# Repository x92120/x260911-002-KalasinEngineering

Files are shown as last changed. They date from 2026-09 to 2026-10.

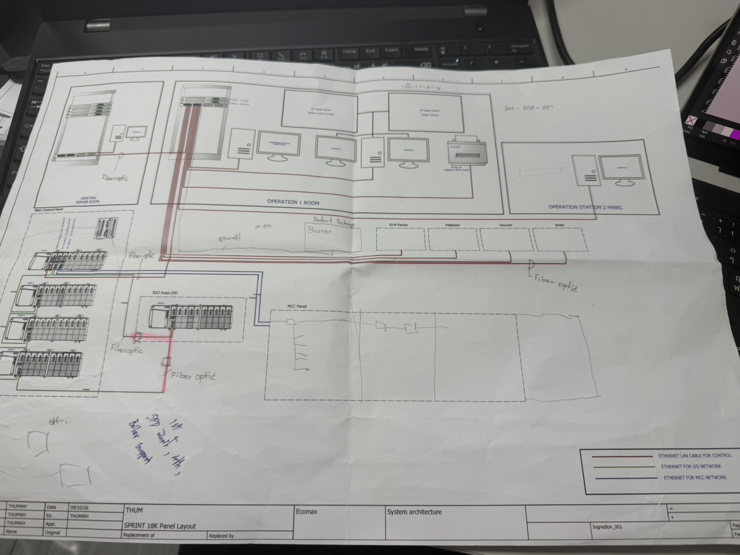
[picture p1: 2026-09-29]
01_Network_Design/05_Drawings_and_Schematics/S__103251990.jpg

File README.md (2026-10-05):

# Ingredion Kalasin Spray Dryer Plant — Engineering Workspace

**Project**: Ingredion Thailand — Sprint 18K TPA Spray Dryer Plant (Kalasin)  
**Engineering Disciplines**: Industrial OT Networks, Electrical Engineering, Instrumentation, Control Systems & CAD Automation  
**Control Platform**: Rockwell Automation ControlLogix 5580 (1756-L950TPSXT) / Studio 5000 / FactoryTalk View SE / Cisco Catalyst 9300 / Stratix 5700  
**Location**: Kalasin, Thailand  
**Ref / Order**: SPRINT 18K TPA Project  

---

## 📁 Workspace Directory Map

```text
x260911-002-KalasinEngineering/
├── 01_Network_Design/                  # Industrial OT Network Architecture, Cisco Core & Redundancy
│   ├── 01_Topology_and_Architecture/  # CPwE Topology Specs & Purdue Level 1-3 Network Architecture
│   ├── 02_IP_Address_Allocation/      # Subnet & IP Allocation Matrix (VLAN 10, 20, 30, 40, 50, 99)
│   ├── 03_Switch_and_Hardware_Config/ # Cisco Catalyst 9300 HSRP, Stratix 5700 & Server Teaming Configurations
│   ├── 04_DLR_and_Redundancy/         # Device Level Ring (DLR) Design & Supervisor Ring Rules
│   ├── 05_Drawings_and_Schematics/    # Network Riser Drawings (SVG, PDF, PNG, DXF & HTML Viewers)
│   ├── 06_Cable_Schedule/             # Cat6A Copper & OM3/OS2 Fiber Optic Cable Schedule
│   └── 07_Commissioning_and_FAT_SAT/  # SAT Test Sheets & Failover Validation Checklists
│
├── 02_Electrical_and_eDrawing/         # Electrical Schematics, CAD Deliverables & Instrument Specifications
│   ├── 01_Source_Drawings_DWG/        # Original Vendor AutoCAD DWG Drawings (SCD, LAY, WIR)
│   ├── 02_ePlan_Exports/              # Exported ePlan Project Packages (Spray Dryer & Electrical)
│   ├── 03_CAD_Exports_DXF_SVG/        # 154 Vectorized DXF & SVG Engineering Drawing Sheets
│   ├── 04_PDF_Reports_and_Drawings/   # 145 Engineering Drawing PDFs, JB Reports & Mounting Plans
│   ├── 05_Instrument_Manuals/         # 22 Vendor Instrument Technical & User Manuals & IS Barriers
│   ├── 06_SCADA_Demo/                 # FactoryTalk View SE HMI Demo Screens, Trends & Slides
│   └── 07_Presentations_and_Overviews/# PID Control Strategy Presentations & Loop Architecture
│
├── 03_IO_Lists_and_Schedules/          # Master Excel Workbooks, I/O Tag Databases & Junction Schedules
│   ├── Destination_Reports/           # 16 Field Junction Box & MCC Destination Schedule Workbooks
│   ├── IO_List/                       # Slot-Configured I/O Master Workbooks & Tag Databases
│   ├── IO_List-Bak/                   # Engineering Revision Archives & Raw Tag Imports
│   └── Slot_by_Slot_Reports/          # Per-Chassis (C1–C7) Slot-by-Slot Hardware Reports (Excel & PDF)
│
├── 04_Automation_Scripts/              # CAD Automation, PDF Report Builders & Interactive HTML Viewers
│   ├── cable_schedule_viewer.html      # Interactive Cable Schedule Search & Filter Tool
│   ├── pid_loop_control_viewer.html    # Interactive PID Loop Control Strategy Web Viewer
│   └── *.py                            # Python Scripts for CAD, PDF, SVG, and Excel Report Generation
│
├── 261005-IO_Config/                   # Remote I/O & Junction Panel Configuration Reports
├── Datasheet/                          # Pepperl+Fuchs Barrier & Instrument Field Datasheets
├── eDrawingTemplate/                   # AutoCAD DXF Drawing Frames, Title Blocks & Module Templates
├── x900-eDrawing/                      # Legacy Vendor ePlan EDB Projects & AutoCAD DWG Drawings
└── x9100-eDrawing/                     # 47 Individual Slot-by-Slot I/O DXF Schematics (C1S1–C5S4)
```

---

## 🎨 Visual Master Deliverables & Interactive Viewers

| Deliverable Sheet | Web / Vector / CAD Links | Description |
| :--- | :--- | :--- |
| **Redundant Cisco Core & Server Infrastructure** | [Web Viewer](file:///e:/xApp-01/x260911-002-KalasinEngineering/01_Network_Design/05_Drawings_and_Schematics/Viewer_Redundant_Network_Diagram.html) • [PDF](file:///e:/xApp-01/x260911-002-KalasinEngineering/01_Network_Design/05_Drawings_and_Schematics/Redundant_Cisco_Core_and_Server_Network_Diagram.pdf) • [SVG](file:///e:/xApp-01/x260911-002-KalasinEngineering/01_Network_Design/05_Drawings_and_Schematics/Redundant_Cisco_Core_and_Server_Network_Diagram.svg) | Dual Cisco Catalyst 9300 HSRP v2, FT View SE Server Teaming, 10G Fiber Uplinks, MCC Switch Trunk |
| **ControlLogix 5-Chassis DLR Network & 13-Slot Rack** | [Web Viewer](file:///e:/xApp-01/x260911-002-KalasinEngineering/01_Network_Design/05_Drawings_and_Schematics/Viewer_Network_and_Rack_Design.html) • [PDF](file:///e:/xApp-01/x260911-002-KalasinEngineering/01_Network_Design/05_Drawings_and_Schematics/ControlLogix_5Chassis_DLR_Network_and_Rack_Design.pdf) • [SVG](file:///e:/xApp-01/x260911-002-KalasinEngineering/01_Network_Design/05_Drawings_and_Schematics/ControlLogix_5Chassis_DLR_Network_and_Rack_Design.svg) | ODVA DLR Ring (CS1–CS4 in MCP-01, CS5 RIO200 via Fiber) & 13-Slot Chassis Elevation |
| **SPRINT 18K Control Layout & System Architecture** | [Web Viewer](file:///e:/xApp-01/x260911-002-KalasinEngineering/01_Network_Design/05_Drawings_and_Schematics/Viewer_SPRINT_18K_Control_Layout.html) • [DXF](file:///e:/xApp-01/x260911-002-KalasinEngineering/01_Network_Design/05_Drawings_and_Schematics/SPRINT_18K_Control_Layout_System_Architecture.dxf) • [PDF](file:///e:/xApp-01/x260911-002-KalasinEngineering/01_Network_Design/05_Drawings_and_Schematics/SPRINT_18K_Control_Layout_System_Architecture.pdf) | Complete Plant Architecture matching hand-drawn draft S__103251990 |
| **Interactive Plant Cable Schedule Viewer** | [HTML Viewer](file:///e:/xApp-01/x260911-002-KalasinEngineering/04_Automation_Scripts/cable_schedule_viewer.html) | Interactive tool for searching instrument cables, terminal pins, and destination JB routing |
| **Interactive PID Loop Control Viewer** | [HTML Viewer](file:///e:/xApp-01/x260911-002-KalasinEngineering/04_Automation_Scripts/pid_loop_control_viewer.html) | Interactive viewer detailing PID control loops for Jet Cooker, Dryer Tower, and CIP |

---

## 📑 Core Documentation Index

### 1. Network Engineering (`01_Network_Design`)
* 📄 [Network Architecture Specification](file:///e:/xApp-01/x260911-002-KalasinEngineering/01_Network_Design/01_Topology_and_Architecture/NETWORK_ARCHITECTURE_SPEC.md)
* 📄 [Plant Subnet & IP Allocation Matrix](file:///e:/xApp-01/x260911-002-KalasinEngineering/01_Network_Design/02_IP_Address_Allocation/IP_ALLOCATION_MATRIX.md)
* 📄 [Cisco Core Switch Configuration Guide](file:///e:/xApp-01/x260911-002-KalasinEngineering/01_Network_Design/03_Switch_and_Hardware_Config/CISCO_REDUNDANT_CORE_SWITCH_CONFIG.md)
* 📄 [Server Redundancy & Dual NIC Teaming](file:///e:/xApp-01/x260911-002-KalasinEngineering/01_Network_Design/03_Switch_and_Hardware_Config/SERVER_REDUNDANCY_AND_NIC_TEAMING_CONFIG.md)
* 📄 [MCC Trunk & Stratix Switch Setup](file:///e:/xApp-01/x260911-002-KalasinEngineering/01_Network_Design/03_Switch_and_Hardware_Config/MCC_TRUNK_AND_SWITCH_CONFIG.md)
* 📄 [Device Level Ring (DLR) Topology Design](file:///e:/xApp-01/x260911-002-KalasinEngineering/01_Network_Design/04_DLR_and_Redundancy/DLR_TOPOLOGY_DESIGN.md)

### 2. Electrical & Drawings (`02_Electrical_and_eDrawing`)
* 📄 [Source DWG Drawings Overview](file:///e:/xApp-01/x260911-002-KalasinEngineering/02_Electrical_and_eDrawing/01_Source_Drawings_DWG/README.md)
* 📄 [ePlan Project Exports Index](file:///e:/xApp-01/x260911-002-KalasinEngineering/02_Electrical_and_eDrawing/02_ePlan_Exports/README.md)
* 📄 [CAD Exports (DXF/SVG) Index](file:///e:/xApp-01/x260911-002-KalasinEngineering/02_Electrical_and_eDrawing/03_CAD_Exports_DXF_SVG/README.md)
* 📄 [PDF Reports & Wiring PDF Drawings](file:///e:/xApp-01/x260911-002-KalasinEngineering/02_Electrical_and_eDrawing/04_PDF_Reports_and_Drawings/README.md)
* 📄 [Pepperl+Fuchs IS Barriers Documentation](file:///e:/xApp-01/x260911-002-KalasinEngineering/02_Electrical_and_eDrawing/05_Instrument_Manuals/Pepperl+Fuchs%20IS%20Barriers/README.md)

### 3. I/O Lists & Schedules (`03_IO_Lists_and_Schedules`)
* 📄 [Destination Junction Box Schedules](file:///e:/xApp-01/x260911-002-KalasinEngineering/03_IO_Lists_and_Schedules/Destination_Reports/README.md)
* 📄 [Master Slot-Configured I/O Databases](file:///e:/xApp-01/x260911-002-KalasinEngineering/03_IO_Lists_and_Schedules/IO_List/README.md)
* 📄 [Per-Chassis Slot-by-Slot Reports](file:///e:/xApp-01/x260911-002-KalasinEngineering/03_IO_Lists_and_Schedules/Slot_by_Slot_Reports/README.md)

### 4. CAD & Automation Tools (`04_Automation_Scripts`)
* 📄 [Automation Scripts Overview](file:///e:/xApp-01/x260911-002-KalasinEngineering/04_Automation_Scripts/README.md)

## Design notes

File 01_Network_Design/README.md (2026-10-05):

# Industrial OT Network Design Specification

**Project**: Ingredion Thailand — Sprint 18K TPA Spray Dryer Plant (Kalasin)  
**Standard**: Converged Plantwide Ethernet (CPwE) / ANSI/ISA-95 & ISA-99 (IEC 62443)  
**Plant Systems**: Area 202 (Pre-Slurry), Area 402 (Adjustment), Area 602 (Spray Dryer), Area 814 (Plant CIP)  
**Main Platform**: Rockwell Automation ControlLogix 5580, Stratix 5700/5400 Managed Switches, EtherNet/IP (CIP), Cisco Catalyst 9300 Core  

---

## 📌 Overview & Architecture Principles

The Industrial OT Network for the Ingredion Kalasin Spray Dryer Plant is architected according to CPwE guidelines to ensure:
1. **Deterministic Performance**: Dedicated EtherNet/IP bandwidth for real-time PLC-to-PLC communication and I/O scan loops.
2. **High Availability & Fault Tolerance**: Device Level Ring (DLR) for field I/O racks with sub-3ms media recovery time, redundant Cisco Catalyst 9300 core switches (HSRP v2), and dual-homed server NIC teaming.
3. **Purdue Security Segmentation**: Strict segmentation across Purdue Levels 0–3 using managed VLANs (10, 20, 30, 40, 50, 99) and access control policies.
4. **Structured Cabling**: Standardized Cat6A industrial copper and OM3/OS2 fiber optic links with defined cabling schedules.

---

## 📁 Directory Structure & Module Index

```text
01_Network_Design/
├── README.md                              # Main Industrial OT Network Specification
├── 01_Topology_and_Architecture/          # CPwE Architecture, Purdue Levels & Topology Specifications
│   ├── README.md
│   └── NETWORK_ARCHITECTURE_SPEC.md       # Core Architecture & Purdue Model Definition
├── 02_IP_Address_Allocation/              # Subnetting Plan, VLAN Assignments & Device Schedule
│   ├── README.md
│   └── IP_ALLOCATION_MATRIX.md            # Detailed IP Address Assignment Table
├── 03_Switch_and_Hardware_Config/         # Cisco IOS Core Configs, Stratix Switch Port Maps & Server Setup
│   ├── README.md
│   ├── CISCO_REDUNDANT_CORE_SWITCH_CONFIG.md  # Cisco Catalyst 9300 HSRP v2 & LACP Production Config
│   ├── MCC_TRUNK_AND_SWITCH_CONFIG.md         # Stratix 5700 MCC 802.1Q Trunk Configuration
│   ├── SERVER_REDUNDANCY_AND_NIC_TEAMING_CONFIG.md # FT View SE Server Redundancy & Teaming Guide
│   └── SWITCH_HARDWARE_SPEC.md                # Managed Switch Hardware Specifications
├── 04_DLR_and_Redundancy/                 # Device Level Ring (DLR) Topology & Ring Supervisor Rules
│   ├── README.md
│   └── DLR_TOPOLOGY_DESIGN.md             # DLR Ring Supervisor Rules & Active/Backup Node Setup
├── 05_Drawings_and_Schematics/            # Master Vector Network Riser Diagrams, Elevation & Web Viewers
│   ├── README.md
│   ├── Redundant_Cisco_Core_and_Server_Network_Diagram.svg
│   ├── ControlLogix_5Chassis_DLR_Network_and_Rack_Design.svg
│   ├── SPRINT_18K_Control_Layout_System_Architecture.dxf
│   └── *.html / *.pdf / *.png
├── 06_Cable_Schedule/                     # Copper Cat6A & Fiber Optic Cable Schedule
│   ├── README.md
│   └── CABLE_SCHEDULE_TEMPLATE.md         # Industrial Cable Schedule Specification
└── 07_Commissioning_and_FAT_SAT/          # SAT Checklists, Ping Sweep Records & Failover Testing
    ├── README.md
    └── NETWORK_COMMISSIONING_CHECKLIST.md # Network Testing & Validation Protocol
```

---

## 🎨 Master Deliverable Drawings

1. **Redundant Cisco Core & Server Infrastructure**:
   * [Interactive Web Viewer](file:///e:/xApp-01/x260911-002-KalasinEngineering/01_Network_Design/05_Drawings_and_Schematics/Viewer_Redundant_Network_Diagram.html)
   * [Printable PDF](file:///e:/xApp-01/x260911-002-KalasinEngineering/01_Network_Design/05_Drawings_and_Schematics/Redundant_Cisco_Core_and_Server_Network_Diagram.pdf)
   * [Vector SVG](file:///e:/xApp-01/x260911-002-KalasinEngineering/01_Network_Design/05_Drawings_and_Schematics/Redundant_Cisco_Core_and_Server_Network_Diagram.svg)
2. **ControlLogix 5-Chassis DLR Network & 13-Slot Rack Redesign**:
   * [Interactive Web Viewer](file:///e:/xApp-01/x260911-002-KalasinEngineering/01_Network_Design/05_Drawings_and_Schematics/Viewer_Network_and_Rack_Design.html)
   * [Printable PDF](file:///e:/xApp-01/x260911-002-KalasinEngineering/01_Network_Design/05_Drawings_and_Schematics/ControlLogix_5Chassis_DLR_Network_and_Rack_Design.pdf)
   * [Vector SVG](file:///e:/xApp-01/x260911-002-KalasinEngineering/01_Network_Design/05_Drawings_and_Schematics/ControlLogix_5Chassis_DLR_Network_and_Rack_Design.svg)
3. **SPRINT 18K Control Layout & System Architecture**:
   * [Interactive Web Viewer](file:///e:/xApp-01/x260911-002-KalasinEngineering/01_Network_Design/05_Drawings_and_Schematics/Viewer_SPRINT_18K_Control_Layout.html)
   * [AutoCAD DXF (R2010)](file:///e:/xApp-01/x260911-002-KalasinEngineering/01_Network_Design/05_Drawings_and_Schematics/SPRINT_18K_Control_Layout_System_Architecture.dxf)

---

## 🏷️ Network Layer Summary

| Layer | Purdue Level | Typical Devices | Network Media | Subnet Example |
|---|---|---|---|---|
| **Site Operations / SCADA** | Level 3 | FactoryTalk SE HMI Server, Historian, Engineering Workstation (EWS) | 1Gbps Fiber / Cat6A | `192.168.10.0/24` (VLAN 10) |
| **Supervisory / Operator HMI** | Level 2 | PanelView 5510, Area Thin Clients, Engineering Laptops | 1Gbps / 100Mbps Copper | `192.168.20.0/24` (VLAN 20) |
| **Control & Inter-PLC** | Level 1 | ControlLogix 5580 CPUs, 1756-EN4TR, Safety PACs | 1000BASE-T / Ring Trunk | `192.168.30.0/24` (VLAN 30) |
| **Field I/O & Drives (DLR Rings)** | Level 0/1 | POINT I/O 1734-AENTR, PowerFlex 525/755 VFDs, Flowmeters | 100BASE-TX M12 / RJ45 DLR | `192.168.40.0/24` (VLAN 40) |

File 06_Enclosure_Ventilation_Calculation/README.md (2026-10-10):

# 06 Enclosure Ventilation & Thermal Calculation

**Project**: Sprint 18K TPA Spray Dryer / Jet Cooker  
**Ref Code**: `xCIP-1545` (Ref: `x2608003`)  
**Client**: Ingredion (Thailand) Co., Ltd.  
**Contractor**: Kalasin Engineering Co., Ltd.  

---

## Deliverables in this Folder

1. **Official PDF Calculation Report**:
   - [`Enclosure_Ventilation_Calculation_Report.pdf`](file:///Users/x92120/xApp-001/x260911-002-KalasinEngineering/06_Enclosure_Ventilation_Calculation/Enclosure_Ventilation_Calculation_Report.pdf) (4 Pages, ready for client submission & FAT binder)

2. **Full Markdown Engineering Report**:
   - [`Enclosure_Ventilation_Calculation_Report.md`](file:///Users/x92120/xApp-001/x260911-002-KalasinEngineering/06_Enclosure_Ventilation_Calculation/Enclosure_Ventilation_Calculation_Report.md)

3. **Source Typst File**:
   - [`Enclosure_Ventilation_Calculation_Report.typ`](file:///Users/x92120/xApp-001/x260911-002-KalasinEngineering/06_Enclosure_Ventilation_Calculation/Enclosure_Ventilation_Calculation_Report.typ)

4. **Automated Calculation Script**:
   - [`calculate_ventilation.py`](file:///Users/x92120/xApp-001/x260911-002-KalasinEngineering/06_Enclosure_Ventilation_Calculation/calculate_ventilation.py)

5. **Diagrams & Catalog Excerpts in `assets/`**:
   - Enclosure Thermal Layout Diagram: [`assets/enclosure_ventilation_diagram.png`](file:///Users/x92120/xApp-001/x260911-002-KalasinEngineering/06_Enclosure_Ventilation_Calculation/assets/enclosure_ventilation_diagram.png)
   - Airflow vs. Temperature Characteristic Curves: [`assets/airflow_vs_temperature_curve.png`](file:///Users/x92120/xApp-001/x260911-002-KalasinEngineering/06_Enclosure_Ventilation_Calculation/assets/airflow_vs_temperature_curve.png)
   - Supplier Catalog Excerpt (Fans): [`assets/primus_fan_models_crop.png`](file:///Users/x92120/xApp-001/x260911-002-KalasinEngineering/06_Enclosure_Ventilation_Calculation/assets/primus_fan_models_crop.png)
   - Supplier Catalog Excerpt (Thermostats): [`assets/primus_thermostats_crop.png`](file:///Users/x92120/xApp-001/x260911-002-KalasinEngineering/06_Enclosure_Ventilation_Calculation/assets/primus_thermostats_crop.png)

---

## Quick Summary of Calculation Results

- **Enclosure**: 800 (W) × 2000 (H) × 400 (D) mm (Volume = 0.640 m³)
- **External Ambient**: 30.0 °C
- **Target Enclosure Temperature**: 35.0 °C ($\Delta T = 5.0\text{ K}$)
- **Total Thermal Dissipation**: **268.3 Watts** (**915.5 BTU/h**), including +15% engineering margin
- **Required Airflow**:
  - Pure Airflow: **166.3 m³/h**
  - Design Airflow (+30% filter margin): **216.2 m³/h**
- **Selected Primus Equipment**:
  - **Filter Fan Unit**: **Primus PMV250N** (8", 220VAC, **428 m³/h**, 56 dB, IP54) — **1.98× design safety factor**
  - **Exhaust Grille**: **Primus PMF250N** (250 × 250 mm with G4 washable filter mat)
  - **Thermostat**: **Primus CMA-001** (Mechanical bimetal, set to Cut-in 35°C / Cut-out 30°C)

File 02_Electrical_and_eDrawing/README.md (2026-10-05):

# Electrical & eDrawing Deliverables

**Project**: Ingredion Thailand — Sprint 18K TPA Spray Dryer Plant (Kalasin)  
**Engineering Discipline**: Electrical Engineering, Cabinet Layout, Loop Wiring, & CAD Deliverables  

---

## 📁 Module Directory Overview

This module houses all original vendor DWG schematics, exported ePlan packages, DXF/SVG CAD exports, print-ready PDF engineering drawing sets, instrument vendor documentation, SCADA demo assets, and control strategy presentations.

```text
02_Electrical_and_eDrawing/
├── 01_Source_Drawings_DWG/          # Original vendor AutoCAD DWG schematics & wiring layouts
├── 02_ePlan_Exports/                # Exported ePlan project packages & electrical schematics
├── 03_CAD_Exports_DXF_SVG/          # 154 vectorized DXF & SVG component & panel sheets
├── 04_PDF_Reports_and_Drawings/     # 145 engineering PDF drawings, JB reports & cable schedules
├── 05_Instrument_Manuals/           # 22 vendor instrument manuals & IS Barrier datasheets
├── 06_SCADA_Demo/                   # SCADA HMI demo screens, process trend slides & HTML viewers
└── 07_Presentations_and_Overviews/  # PID loop control specification slides & architecture overviews
```

---

## 📑 Key Master Engineering Documents

| Document Title | Format | Description / Link |
| :--- | :---: | :--- |
| **Kalasin Jet Cooker Master Drawings** | PDF | [KALASIN_JET_COOKER_MASTER_ENGINEERING_DRAWINGS_COMPLETE.pdf](file:///e:/xApp-01/x260911-002-KalasinEngineering/02_Electrical_and_eDrawing/04_PDF_Reports_and_Drawings/KALASIN_JET_COOKER_MASTER_ENGINEERING_DRAWINGS_COMPLETE.pdf) |
| **Jet Cooker PLC I/O Wiring Drawings Complete** | PDF | [Jet_Cooker_PLC_IO_Wiring_Drawings_Complete.pdf](file:///e:/xApp-01/x260911-002-KalasinEngineering/02_Electrical_and_eDrawing/04_PDF_Reports_and_Drawings/Jet_Cooker_PLC_IO_Wiring_Drawings_Complete.pdf) |
| **MCC Panel Layout & Mounting Plan (M1–M4)** | PDF | [MCC_Panel_Layout_Mounting_Plan_M1_M2_M3_M4.pdf](file:///e:/xApp-01/x260911-002-KalasinEngineering/02_Electrical_and_eDrawing/04_PDF_Reports_and_Drawings/MCC_Panel_Layout_Mounting_Plan_M1_M2_M3_M4.pdf) |
| **Cable Schedule (MCC to Junction Boxes)** | PDF | [Cable_Schedule_MCC_to_Junction_Boxes.pdf](file:///e:/xApp-01/x260911-002-KalasinEngineering/02_Electrical_and_eDrawing/04_PDF_Reports_and_Drawings/Cable_Schedule_MCC_to_Junction_Boxes.pdf) |
| **Instrument Installation Hookups & Wiring** | PDF | [Instrument_Installation_Hookup_and_Wiring_Templates.pdf](file:///e:/xApp-01/x260911-002-KalasinEngineering/02_Electrical_and_eDrawing/04_PDF_Reports_and_Drawings/Instrument_Installation_Hookup_and_Wiring_Templates.pdf) |
| **All Junction Boxes Master I/O Report** | PDF | [IO_List_All_Junction_Boxes_Master_Report.pdf](file:///e:/xApp-01/x260911-002-KalasinEngineering/02_Electrical_and_eDrawing/04_PDF_Reports_and_Drawings/IO_List_All_Junction_Boxes_Master_Report.pdf) |
| **PID Loop Control Specification Presentation** | PPTX / HTML | [PID_Loop_Control_Specification_Kalasin.pptx](file:///e:/xApp-01/x260911-002-KalasinEngineering/02_Electrical_and_eDrawing/07_Presentations_and_Overviews/PID_Loop_Control_Specification_Kalasin.pptx) |

---

## 📐 Source AutoCAD DWG Reference

* [R5THS00138-000-SCD-10001_0.dwg](file:///e:/xApp-01/x260911-002-KalasinEngineering/02_Electrical_and_eDrawing/01_Source_Drawings_DWG/R5THS00138-000-SCD-10001_0.dwg) — Master Control System Schematic
* [R5THS00138-FBR-LAY-20001_1.dwg](file:///e:/xApp-01/x260911-002-KalasinEngineering/02_Electrical_and_eDrawing/01_Source_Drawings_DWG/R5THS00138-FBR-LAY-20001_1.dwg) — Silo Panel General Layout & BOM
* [R5THS00138-FBR-WIR-20001_3.dwg](file:///e:/xApp-01/x260911-002-KalasinEngineering/02_Electrical_and_eDrawing/01_Source_Drawings_DWG/R5THS00138-FBR-WIR-20001_3.dwg) — Electrical Wiring Layout

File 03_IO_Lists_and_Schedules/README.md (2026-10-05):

# I/O Lists & Instrument Schedules

**Project**: Ingredion Thailand — Sprint 18K TPA Spray Dryer Plant (Kalasin)  
**Engineering Discipline**: Instrumentation, Control System I/O Allocation & Cable Scheduling  

---

## 📌 Module Directory Overview

This module houses all master Excel workbooks, PDF I/O schedules, per-enclosure destination reports, per-chassis slot reports, and instrument cable mapping matrices for the plant control system.

```text
03_IO_Lists_and_Schedules/
├── Destination_Reports/             # 16 Field Junction Box & MCC Enclosure Workbooks
│   └── README.md
├── IO_List/                         # Slot-Configured I/O Master Workbooks & Tag Databases
│   └── README.md
├── IO_List-Bak/                     # Revision Archives, Raw Tag Imports & Historical Summaries
│   └── README.md
├── Slot_by_Slot_Reports/            # Per-Chassis (C1–C7) Slot-by-Slot Reports (Excel & PDF)
│   └── README.md
├── Chassis_and_Slot_IO_Source_Destination_Report.pdf  # ⭐ MASTER PDF: 99-Page I/O Schedule
├── Chassis_IO_List_Per_Slot_Report.xlsx               # ⭐ MASTER EXCEL: 48 Tabs (1 Sheet per Slot)
├── Destination_IO_List_Master_Report.pdf              # ⭐ MASTER PDF: 82-Page Destination Schedule
└── Destination_IO_List_Master_Report.xlsx             # ⭐ MASTER EXCEL: 17 Tabs (1 Sheet per Destination)
```

---

## 📑 Key Master Workbooks & PDF Reports

| Report / Deliverable Name | Format | Purpose | Link / Location |
| :--- | :---: | :--- | :--- |
| **Destination I/O Master Schedule** | PDF (82 Pages) | Master Field Enclosure Vector Schedule | [Destination_IO_List_Master_Report.pdf](file:///e:/xApp-01/x260911-002-KalasinEngineering/03_IO_Lists_and_Schedules/IO_List-Bak/Destination_IO_List_Master_Report.pdf) |
| **Destination I/O Master Excel** | Excel (17 Tabs) | 1 Tab Per Field Destination (16 JBs + Index) | [Destination_IO_List_Master_Report.xlsx](file:///e:/xApp-01/x260911-002-KalasinEngineering/03_IO_Lists_and_Schedules/IO_List-Bak/Destination_IO_List_Master_Report.xlsx) |
| **Per-Destination Workbooks** | Excel (16 Files) | Independent Enclosure Schedule Workbooks | [Destination_Reports/](file:///e:/xApp-01/x260911-002-KalasinEngineering/03_IO_Lists_and_Schedules/Destination_Reports/README.md) |
| **Chassis & Slot Master PDF** | PDF (99 Pages) | Hardware Rack Wiring Vector Deliverable | [Chassis_and_Slot_IO_Source_Destination_Report.pdf](file:///e:/xApp-01/x260911-002-KalasinEngineering/03_IO_Lists_and_Schedules/IO_List-Bak/Chassis_and_Slot_IO_Source_Destination_Report.pdf) |
| **Chassis I/O List Per Slot** | Excel (48 Tabs) | 1 Tab Per Hardware Slot (47 Slot Tabs + Index) | [Chassis_IO_List_Per_Slot_Report.xlsx](file:///e:/xApp-01/x260911-002-KalasinEngineering/03_IO_Lists_and_Schedules/IO_List-Bak/Chassis_IO_List_Per_Slot_Report.xlsx) |
| **Per-Chassis Slot Packages** | Excel + PDF | Per-Chassis Hardware Packages (C1–C7) | [Slot_by_Slot_Reports/](file:///e:/xApp-01/x260911-002-KalasinEngineering/03_IO_Lists_and_Schedules/Slot_by_Slot_Reports/README.md) |
| **Instrument & Cable Matrix** | Excel Workbook | Master Instrument-to-Cable Schedule | [Instrument_IO_Mapping_with_Models_and_Cables.xlsx](file:///e:/xApp-01/x260911-002-KalasinEngineering/03_IO_Lists_and_Schedules/IO_List-Bak/Instrument_IO_Mapping_with_Models_and_Cables.xlsx) |

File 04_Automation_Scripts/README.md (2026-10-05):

# 04_Automation_Scripts — Engineering CAD & Report Generators

This directory contains the Python automation tools, drawing generation engines, PDF compilers, and interactive HTML web viewers for the **Ingredion Kalasin Spray Dryer Plant** project.

---

## 🌐 Interactive Web Viewers

* 🌐 **[cable_schedule_viewer.html](file:///e:/xApp-01/x260911-002-KalasinEngineering/04_Automation_Scripts/cable_schedule_viewer.html)**: Dynamic cable schedule inspector with live search, field destination filtering, and cable routing breakdown.
* 🌐 **[pid_loop_control_viewer.html](file:///e:/xApp-01/x260911-002-KalasinEngineering/04_Automation_Scripts/pid_loop_control_viewer.html)**: Interactive PID loop control architecture viewer covering Jet Cooker, Dryer Tower, and CIP systems.

---

## 📁 Automation Scripts Inventory & Categorization

### 1. I/O Report & Master Excel Workbooks Generators
* ⚙️ **`build_chassis_slot_pdf_reports.py`**: Compiles per-chassis (C1–C7) slot-by-slot PDF vector reports.
* ⚙️ **`build_chassis_slot_source_destination_report.py`**: Builds 99-page master chassis & slot source-to-destination vector report.
* ⚙️ **`build_destination_io_report.py`**: Builds 82-page master destination report and 16 individual junction box workbooks.
* ⚙️ **`build_io_list_by_slot_config.py`**: Maps raw ePlan tag data into slot-configured Excel workbooks.
* ⚙️ **`build_junction_io_panel_report.py`**: Generates panel P1–P4 junction-to-panel allocation matrix & remote I/O reports.
* ⚙️ **`build_per_slot_io_report.py`**: Builds 48-tab master Excel workbook with 1 tab per slot.
* ⚙️ **`build_tags_list_plc_r02.py`**: Processes and updates PLC tag databases.

### 2. CAD Drawing Generators & Converters
* ⚙️ **`export_cad_svg_dxf.py`**: Batch CAD export pipeline converting ePlan DWG/DXF drawings into vectorized SVG presentation sheets.
* ⚙️ **`generate_di_slot_dxf_drawings.py`**: Generates 15 individual DI slot DXF schematics (C1S4–C4S3).
* ⚙️ **`generate_do_slot_dxf_drawings.py`**: Generates 9 individual DO slot DXF schematics (C1S8–C5S3).
* ⚙️ **`generate_plc_io_wiring_drawings.py`**: Generates 40-sheet PLC I/O modular wiring schematics (`KAL-JC-WIR-*`).
* ⚙️ **`generate_mcc_panel_layout.py`**: Generates 14-sheet MCC panel layout drawings (front elevation, internal GA, BOM).
* ⚙️ **`generate_instrument_drawing_templates.py`**: Generates 26 instrument installation hookup drawings (`KAL-JC-TYP-*`).
* ⚙️ **`generate_pf_is_barrier_dxf.py`**: Generates Pepperl+Fuchs IS barrier CAD wiring diagrams.
* ⚙️ **`convert_pf_datasheet_to_dxf.py`** & **`convert_yamamori_pdf_to_dxf.py`**: PDF datasheet-to-DXF CAD converter scripts.

### 3. Presentation & SCADA Assets Generators
* ⚙️ **`generate_automation_architecture_slides.py`**: Generates dark-theme automation architecture presentation slides.
* ⚙️ **`generate_light_architecture_slides.py`**: Generates light-theme architecture presentation slides.
* ⚙️ **`generate_cable_schedule_slides.py`**: Generates cable schedule SVG vector presentation slides.
* ⚙️ **`generate_pid_control_presentation.py`**: Generates PID loop control specification presentation slides.
* ⚙️ **`generate_scada_demo_video.py`**: Renders 60-second 1080p SCADA demo MP4 video animation.

---

## ⚙️ Running Generators

```powershell
# Build master destination I/O report & 16 enclosure workbooks:
python 04_Automation_Scripts/build_destination_io_report.py

# Build master chassis & slot 99-page vector PDF report:
python 04_Automation_Scripts/build_chassis_slot_source_destination_report.py

# Generate 40-sheet PLC wiring diagrams:
python 04_Automation_Scripts/generate_plc_io_wiring_drawings.py

# Generate MCC panel layout drawings:
python 04_Automation_Scripts/generate_mcc_panel_layout.py
```

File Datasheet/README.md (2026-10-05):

# Datasheet — Field Instruments & Barrier Datasheets

This directory contains vendor technical datasheets, component specifications, and CAD-converted datasheet pages for field instruments and intrinsically safe isolator modules deployed at the **Ingredion Kalasin Spray Dryer Plant**.

---

## 📁 Subdirectories & Files

* **`75ebca09-4009-4d5b-9186-ca9b53211407.pdf`**: Master instrument datasheet package.
* **[PF/](file:///e:/xApp-01/x260911-002-KalasinEngineering/Datasheet/PF/README.md)**: Pepperl+Fuchs Intrinsically Safe (IS) K-System Isolating Barrier datasheets (PDF) and converted CAD drawings (DXF).

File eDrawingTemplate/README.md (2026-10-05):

# eDrawingTemplate — AutoCAD DXF & DWG Drawing Frames and Templates

This directory contains standardized AutoCAD drawing title block frames, border templates, and module wiring templates used by automated script generators for the **Ingredion Kalasin Spray Dryer Plant** CAD deliverables.

---

## 📐 Template Inventory

### 1. Title Block & Frame Templates
* **`frame.dwg`** / **`frame.dxf`**: Standard A3 ISO drawing frame with title block, engineering revision block, project metadata, and logo attributes.
* **`Frame_rev01.dxf`**: Revision 01 updated title block frame.
* **`Drawing2.dxf`**: Reference AutoCAD layout workspace template.

### 2. Module Electrical Wiring Templates
* **`template_DI-r02.dwg`** / **`template_DI-r02.dxf`**: Revision 02 32-Channel Digital Input (1756-IB32) module wiring drawing template.
* **`template_DO-r02.dwg`** / **`template_DO-r02.dxf`**: Revision 02 32-Channel Digital Output (1756-OB32 + Relay) module wiring drawing template.
* **`template_AI-r02.dwg`** / **`template_AI-r02.dxf`**: Revision 02 16-Channel Analog Input (1756-IF16) module wiring drawing template.
* **`template_DI.dxf`** / **`template_DO.dxf`**: Legacy baseline single-channel wiring templates.

---

## ⚙️ Usage in Automation Pipeline

Python scripts in `04_Automation_Scripts` (such as `generate_di_slot_dxf_drawings.py` and `generate_do_slot_dxf_drawings.py`) read these DXF templates, clone entity structures, update tag text and wire numbers, and output per-slot drawings into `02_Electrical_and_eDrawing/03_CAD_Exports_DXF_SVG/` and `x9100-eDrawing/`.

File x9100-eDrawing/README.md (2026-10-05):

# x9100-eDrawing — Individual Slot-by-Slot CAD Wiring Drawings

This directory contains individual AutoCAD `.dxf` single-slot wiring diagrams for **all 13 slots (Slots 0 to 12)** across Chassis `C1`, `C2`, `C3`, `C4`, and `C5`, formatted with explicit hardware module model tags (`CxSy-<CARD>.dxf`, e.g. `C1S4-IB32.dxf`), master multi-slot CAD compilations, Python generation scripts, and module templates for the **Ingredion Kalasin Spray Dryer Plant**.

---

## 📁 Group Subdirectories Index (`CxSy-<CARD>.dxf`)

* 📁 **[C1/](file:///e:/xApp-01/x260911-002-KalasinEngineering/x9100-eDrawing/C1)** — Chassis C1 Main Controller Rack Drawings (30 files: `C1S0-L950TPSXT` to `C1S12-N2` DI, DO, AI, CPU & COMM DXFs)
* 📁 **[C2/](file:///e:/xApp-01/x260911-002-KalasinEngineering/x9100-eDrawing/C2)** — Chassis C2 Process Expansion Rack Drawings (26 files: `C2S0-EN4TR` to `C2S12-IF16` COMM, DI, DO & AI DXFs)
* 📁 **[C3/](file:///e:/xApp-01/x260911-002-KalasinEngineering/x9100-eDrawing/C3)** — Chassis C3 Evaporator & Skid I/O Rack Drawings (26 files: `C3S0-EN4TR` to `C3S12-OF8` COMM, DI, DO, AI, Reserve & AO DXFs)
* 📁 **[C4/](file:///e:/xApp-01/x260911-002-KalasinEngineering/x9100-eDrawing/C4)** — Chassis C4 Spray Dryer & Exhaust Rack Drawings (26 files: `C4S0-EN4TR` to `C4S12-N2` COMM, DI, DO, AI & Reserve DXFs)
* 📁 **[C5/](file:///e:/xApp-01/x260911-002-KalasinEngineering/x9100-eDrawing/C5)** — Chassis C5 Remote I/O Skid RIO-200 Drawings (26 files: `C5S0-EN4TR` to `C5S12-N2` COMM, DI, DO, AI & Reserve DXFs)

---

## 📑 Complete 13-Slot Hardware Model Filename Schedule

| Chassis | Slot 0 | Slots 1–3 | Slots 4–7 | Slots 8–9 | Slots 10–11 | Slot 12 |
| :---: | :--- | :--- | :--- | :--- | :--- | :--- |
| **C1** | `C1S0-L950TPSXT.dxf` | `C1S1-EN4TR.dxf` .. `C1S3-EN4TR.dxf` | `C1S4-IB32.dxf` .. `C1S7-IB32.dxf` | `C1S8-OB32.dxf` .. `C1S9-OB32.dxf` | `C1S10-IF16.dxf` .. `C1S11-IF16.dxf` | `C1S12-N2.dxf` |
| **C2** | `C2S0-EN4TR.dxf` | `C2S1-IB32.dxf` .. `C2S3-IB32.dxf` | `C2S4-IB32.dxf` .. `C2S5-IB32.dxf` | `C2S6-OB32.dxf` .. `C2S8-OB32.dxf` | `C2S9-IF16.dxf` .. `C2S11-IF16.dxf` | `C2S12-IF16.dxf` |
| **C3** | `C3S0-EN4TR.dxf` | `C3S1-IB32.dxf` .. `C3S3-IB32.dxf` | `C3S4-OB32.dxf` .. `C3S5-OB32.dxf` | `C3S6-IF16.dxf` .. `C3S9-IF16.dxf` | `C3S10-N2.dxf` .. `C3S11-N2.dxf` | `C3S12-OF8.dxf` |
| **C4** | `C4S0-EN4TR.dxf` | `C4S1-IB32.dxf` .. `C4S3-IB32.dxf` | `C4S4-OB32.dxf` | `C4S5-IF16.dxf` .. `C4S6-IF16.dxf` | `C4S7-N2.dxf` .. `C4S11-N2.dxf` | `C4S12-N2.dxf` |
| **C5** | `C5S0-EN4TR.dxf` | `C5S1-IB32.dxf` .. `C5S2-IB32.dxf` | `C5S3-OB32.dxf` | `C5S4-IF16.dxf` | `C5S5-N2.dxf` .. `C5S11-N2.dxf` | `C5S12-N2.dxf` |

---

## ⚙️ Running Automation Scripts

```powershell
# Batch update all per-slot DXF drawings with CxSy-<CARD> naming:
python x9100-eDrawing/update_x9100_drawings.py

# Recompile master 65-slot (5 Rows x 13 Columns) DXF grid compilation file:
python x9100-eDrawing/build_master_dxf.py
```

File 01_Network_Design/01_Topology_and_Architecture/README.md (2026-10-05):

# 01_Topology_and_Architecture — Industrial OT Network Architecture

This directory contains the core topology and architecture specifications for the **Ingredion Kalasin Spray Dryer Plant** industrial control system network, designed according to Converged Plantwide Ethernet (CPwE) standards.

---

## 📄 Key Documents & Specifications

* **[NETWORK_ARCHITECTURE_SPEC.md](file:///e:/xApp-01/x260911-002-KalasinEngineering/01_Network_Design/01_Topology_and_Architecture/NETWORK_ARCHITECTURE_SPEC.md)**: Detailed architecture specification covering Purdue Model Levels 1–3, industrial VLAN segmentation, firewall boundaries, and network redundancy standards.

---

## 📐 CPwE Network Architecture Overview

```text
+-------------------------------------------------------------------+
| Level 3: Industrial Zone / SCADA Servers (FactoryTalk SE, EWS)    |
+-------------------------------------------------------------------+
                                  |
                   [Cisco Catalyst 9300 Core HSRP]
                                  |
+-------------------------------------------------------------------+
| Level 2: Supervisory Control / HMI & PanelView Touchscreens      |
+-------------------------------------------------------------------+
                                  |
                   [Stratix 5700 Industrial Switches]
                                  |
+-------------------------------------------------------------------+
| Level 1: Control (ControlLogix 5580 PACs & 1756-EN4TR Cards)     |
+-------------------------------------------------------------------+
                                  |
                   [Device Level Ring (DLR) Topology]
                                  |
+-------------------------------------------------------------------+
| Level 0: Field I/O (POINT I/O 1734-AENTR, PowerFlex VFDs, Sensors)|
+-------------------------------------------------------------------+
```

---

## 🎯 Primary Architectural Goals

1. **Sub-3ms Ring Recovery**: ODVA Device Level Ring (DLR) topology for field chassis (CS1–CS5).
2. **Core Redundancy**: Dual Cisco Catalyst 9300 core switches operating with Hot Standby Router Protocol (HSRP v2).
3. **Dual-Homed Server NIC Teaming**: FactoryTalk View SE servers configured with active/standby NIC teaming for seamless failover.

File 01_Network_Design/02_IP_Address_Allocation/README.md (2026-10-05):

# 02_IP_Address_Allocation — Subnet & IP Matrix

This directory defines the plant-wide IP address allocation matrix and VLAN segmentation schema for the **Ingredion Kalasin Spray Dryer Plant**.

---

## 📄 Key Document

* **[IP_ALLOCATION_MATRIX.md](file:///e:/xApp-01/x260911-002-KalasinEngineering/01_Network_Design/02_IP_Address_Allocation/IP_ALLOCATION_MATRIX.md)**: Full master IP address allocation table for PLCs, HMIs, Remote I/O adapters, VFDs, Managed Switches, and SCADA Servers.

---

## 🌐 Industrial VLAN Assignment Table

| VLAN ID | Subnet CIDR | Description / Target Equipment | Gateway / HSRP |
| :---: | :--- | :--- | :--- |
| **VLAN 10** | `192.168.10.0/24` | SCADA Servers, Historian, Engineering Workstations (Level 3) | `192.168.10.1` |
| **VLAN 20** | `192.168.20.0/24` | PanelView HMI Touchscreens & Thin Clients (Level 2) | `192.168.20.1` |
| **VLAN 30** | `192.168.30.0/24` | Primary PAC Controller Inter-PLC Network (Level 1) | `192.168.30.1` |
| **VLAN 40** | `192.168.40.0/24` | Field Remote I/O & DLR EtherNet/IP Sub-ring (Level 0/1) | N/A (Isolated DLR) |
| **VLAN 50** | `192.168.50.0/24` | PowerFlex VFDs & Motor Control Center (MCC) Devices | `192.168.50.1` |
| **VLAN 99** | `10.10.99.0/24` | Network Infrastructure Management (Stratix / Cisco Switches) | `10.10.99.1` |

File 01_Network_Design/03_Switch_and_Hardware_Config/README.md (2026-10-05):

# 03_Switch_and_Hardware_Config — Switch Configurations & Hardware Setup

This directory contains production-ready Cisco IOS and Rockwell Stratix managed switch configurations, along with server NIC teaming guidelines for the **Ingredion Kalasin Spray Dryer Plant**.

---

## 📄 Key Production Configurations & Specifications

* 🛠️ **[CISCO_REDUNDANT_CORE_SWITCH_CONFIG.md](file:///e:/xApp-01/x260911-002-KalasinEngineering/01_Network_Design/03_Switch_and_Hardware_Config/CISCO_REDUNDANT_CORE_SWITCH_CONFIG.md)**: Production Cisco Catalyst 9300 HSRP v2, LACP EtherChannel, and VLAN Trunk configuration scripts.
* 🛠️ **[MCC_TRUNK_AND_SWITCH_CONFIG.md](file:///e:/xApp-01/x260911-002-KalasinEngineering/01_Network_Design/03_Switch_and_Hardware_Config/MCC_TRUNK_AND_SWITCH_CONFIG.md)**: Stratix 5700 802.1Q trunking configuration for the Motor Control Center (MCC) switch cabinet.
* 💻 **[SERVER_REDUNDANCY_AND_NIC_TEAMING_CONFIG.md](file:///e:/xApp-01/x260911-002-KalasinEngineering/01_Network_Design/03_Switch_and_Hardware_Config/SERVER_REDUNDANCY_AND_NIC_TEAMING_CONFIG.md)**: Configuration guide for FT View SE Primary/Secondary SCADA Server NIC teaming and network failover.
* 📋 **[SWITCH_HARDWARE_SPEC.md](file:///e:/xApp-01/x260911-002-KalasinEngineering/01_Network_Design/03_Switch_and_Hardware_Config/SWITCH_HARDWARE_SPEC.md)**: Hardware specification sheet for Cisco Catalyst 9300 and Stratix 5700/5400 switches.

---

## 🔒 Security & Redundancy Features

1. **HSRP v2 Core Failover**: Sub-second virtual router failover between Active and Standby Catalyst 9300 core switches.
2. **802.1Q Trunking**: Standardized VLAN tagging across fiber optic uplinks between MCP-01 and field cabinets.
3. **Port Security & CIP Sync**: Optimized QoS configuration prioritizing PTP (Precision Time Protocol / IEEE 1588) and CIP I/O packets.

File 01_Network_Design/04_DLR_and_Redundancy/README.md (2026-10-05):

# 04_DLR_and_Redundancy — Device Level Ring Topology

This directory details the ODVA EtherNet/IP Device Level Ring (DLR) design, ring supervisor configuration, and redundancy protocols for the **Ingredion Kalasin Spray Dryer Plant**.

---

## 📄 Key Document

* **[DLR_TOPOLOGY_DESIGN.md](file:///e:/xApp-01/x260911-002-KalasinEngineering/01_Network_Design/04_DLR_and_Redundancy/DLR_TOPOLOGY_DESIGN.md)**: Device Level Ring topology specification, active ring supervisor setup, backup supervisor rules, and sub-3ms recovery benchmarks.

---

## ⭕ DLR Ring Allocation Summary

| Ring ID | Location / Cabinet | Included Nodes / Chassis | Active Supervisor | Backup Supervisor | Media / Speed |
| :---: | :--- | :--- | :--- | :--- | :--- |
| **DLR-01** | MCP-01 (Main Control Panel) | Chassis CS1, CS2, CS3, CS4 | 1756-EN4TR (CS1 Slot 1) | 1756-EN4TR (CS2 Slot 1) | Cat6A Shielded (100Mbps Full-Duplex) |
| **DLR-02** | RIO200 (Remote I/O Cabinet) | Chassis CS5 (RIO200 1734-AENTR / 1756-RIO) | 1756-EN4TR (CS5 Slot 1) | Stratix 5700 Managed Switch | Single-Mode Fiber Optic Link |

---

## ⚡ Performance Specifications

* **Media Recovery Time**: < 3 ms upon single link disruption.
* **Beacon Interval**: 400 microseconds.
* **Timeout Value**: 1,960 microseconds.

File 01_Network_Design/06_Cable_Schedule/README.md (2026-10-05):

# 06_Cable_Schedule — Industrial Network Cable Specifications

This directory contains the cable schedule standards, media specifications, and labeling conventions for the **Ingredion Kalasin Spray Dryer Plant**.

---

## 📄 Key Document

* **[CABLE_SCHEDULE_TEMPLATE.md](file:///e:/xApp-01/x260911-002-KalasinEngineering/01_Network_Design/06_Cable_Schedule/CABLE_SCHEDULE_TEMPLATE.md)**: Master network cabling specification, cable ID format, wire colors, and shielding rules.

---

## 🔌 Cable Media & Standards

| Cable Code | Cable Type | Conductor / Spec | Typical Usage | Max Distance |
| :---: | :--- | :--- | :--- | :---: |
| **CAT6A-SH** | Cat6A Shielded S/FTP | 24 AWG Twisted Pair, Teal PUR Jacket | EtherNet/IP Field DLR & Switch Links | 100 m |
| **FO-SM-OS2** | Single-Mode Fiber OS2 | 9/125 µm Duplex LC | MCP-01 to RIO200 & MCC Fiber Trunk | 2 km |
| **FO-MM-OM3** | Multi-Mode Fiber OM3 | 50/125 µm Duplex LC | Server Room to Core Switch Interconnect | 300 m |

---

## 🏷️ Cable Labeling Format

Format: `[Source Device] - [Media Type] - [Destination Device] - [Cable No.]`  
Example: `CS1-EN4TR1 - CAT6A - CS2-EN4TR1 - CABLE-0104`

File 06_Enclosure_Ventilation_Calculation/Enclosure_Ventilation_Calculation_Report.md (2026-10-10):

# Control Enclosure Thermal Dissipation & Ventilation Fan Sizing Report

**Document Reference**: `KAL-CALC-VENT-2610-001`  
**Revision**: `Rev 1.0` (Date: 10-Oct-2026)  
**Project**: Sprint 18K TPA Spray Dryer / Jet Cooker (xCIP-1545, Ref: `x2608003`)  
**Client**: Ingredion (Thailand) Co., Ltd.  
**Contractor**: Kalasin Engineering Co., Ltd.  
**Applicable Standards**: IEC 60890, IEC 61439-1, DIN 57660  
**Supplier Catalog Reference**: [`x9100-eDrawing/Supplier/PrimusVentilation.pdf`](file:///Users/x92120/xApp-001/x260911-002-KalasinEngineering/x9100-eDrawing/Supplier/PrimusVentilation.pdf)  
**Deliverable PDF**: [`06_Enclosure_Ventilation_Calculation/Enclosure_Ventilation_Calculation_Report.pdf`](file:///Users/x92120/xApp-001/x260911-002-KalasinEngineering/06_Enclosure_Ventilation_Calculation/Enclosure_Ventilation_Calculation_Report.pdf)  

---

## 1. Executive Summary & Design Basis

This formal engineering report calculates the total internal heat dissipation, evaluates natural surface radiation/conduction, determines forced cooling ventilation airflow requirements, and selects the optimal industrial cabinet filter fan from the approved supplier catalog **Primus Ventilation Systems** for an automation cabinet with dimensions **800 mm (W) × 2000 mm (H) × 400 mm (D)**.

### Summary of Operating Conditions & Results

| Parameter | Specified / Calculated Value | Design Reference & Standard |
| :--- | :--- | :--- |
| **Enclosure Outer Dimensions** | **800 mm (W) × 2000 mm (H) × 400 mm (D)** | Floor-standing automation cabinet |
| **Gross Enclosure Volume** | **0.640 m³** | Free internal air volume |
| **Effective Surface Area ($A_{\text{eff}}$)** | **4.768 m²** (Free-standing) / **3.168 m²** (Wall-mounted) | Calculated per IEC 60890 |
| **External Ambient Temperature ($T_{\text{ambient}}$)** | **30.0 °C** | Specified external ambient condition |
| **Target Internal Temperature ($T_{\text{internal}}$)** | **35.0 °C** (Optimum Lifespan) / **40.0 °C** (Standard Limit) | $\Delta T = 5.0\text{ K}$ (Optimum) / $10.0\text{ K}$ (Standard) |
| **Installed Equipment Heat Load** | **233.3 Watts** | 2x 40A PSUs + 1756 13-Slot Rack + Relays |
| **Engineering Safety Margin (+15%)** | **35.0 Watts** | Cable resistance, aging & future expansion |
| **Total Design Heat Load ($Q_{\text{total}}$)** | **268.3 Watts** (**915.5 BTU/h**) | Evacuated by forced airflow |
| **Required Design Airflow ($V_{\text{design}}$ @ 35°C)** | **216.2 m³/h** | Includes +30% dust clogging margin |
| **Selected Fan Model** | **PRIMUS PMV250N** (8" Filter Fan, 220VAC, IP54) | **428 m³/h** airflow (**1.98× design safety factor**) |
| **Matching Exhaust Grille** | **PRIMUS PMF250N** (250 × 250 mm with G4 Filter) | Tool-free Flap-Open front door |
| **Thermostatic Controller** | **PRIMUS CMA-001** (Mechanical DIN-Rail Thermostat) | Setpoint: Cut-in 35°C / Cut-out 30°C |

---

## 2. Enclosure Physical Dimensions & Surface Heat Dissipation (IEC 60890)

The physical enclosure geometry and effective heat dissipation area $A_{\text{eff}}$ are derived in accordance with **IEC 60890** (*Calculation of temperature rise for low-voltage switchgear and controlgear assemblies*):

- **Width ($W$)**: $0.800\text{ m}$ ($800\text{ mm}$)
- **Height ($H$)**: $2.000\text{ m}$ ($2000\text{ mm}$)
- **Depth ($D$)**: $0.400\text{ m}$ ($400\text{ mm}$)
- **Volume ($V$)**: $W \times H \times D = 0.800 \times 2.000 \times 0.400 = \mathbf{0.640\text{ m}^3}$

### Surface Area Breakdown

$$\begin{aligned}
A_{\text{front}} &= W \times H = 0.800 \times 2.000 = 1.600\text{ m}^2 \\
A_{\text{rear}} &= W \times H = 0.800 \times 2.000 = 1.600\text{ m}^2 \\
A_{\text{sides}} &= 2 \times (D \times H) = 2 \times (0.400 \times 2.000) = 1.600\text{ m}^2 \\
A_{\text{roof}} &= W \times D = 0.800 \times 0.400 = 0.320\text{ m}^2 \\
A_{\text{geom, total}} &= 1.600 + 1.600 + 1.600 + 0.320 = \mathbf{5.120\text{ m}^2} \quad \text{(Bottom base on floor excluded)}
\end{aligned}$$

### IEC 60890 Weighted Effective Surface Area ($A_{\text{eff}}$)

1. **Free-Standing Enclosure** (all sides detached from walls):
   $$A_{\text{eff, free}} = 1.8 \cdot H \cdot (W + D) + 1.4 \cdot W \cdot D = 1.8(2.0)(0.8 + 0.4) + 1.4(0.8)(0.4) = 4.320 + 0.448 = \mathbf{4.768\text{ m}^2}$$
2. **Stand-Alone against a Wall** (rear panel covered):
   $$A_{\text{eff, wall}} = 1.4 \cdot W \cdot D + 0.9 \cdot D \cdot H + W \cdot H + 0.5 \cdot D \cdot H = 0.448 + 0.720 + 1.600 + 0.400 = \mathbf{3.168\text{ m}^2}$$

### Natural Surface Heat Dissipation Capability ($Q_s$)

Using the heat transfer coefficient for standard painted sheet steel $k = 5.5\text{ W}/(\text{m}^2\cdot\text{K})$:
- At $\Delta T = 5.0\text{ K}$ ($T_{\text{in}} = 35.0^\circ\text{C}$):
  - Free-Standing: $Q_s = 5.5 \times 4.768 \times 5.0 = \mathbf{131.1\text{ W}}$
  - Wall-Mounted: $Q_s = 5.5 \times 3.168 \times 5.0 = \mathbf{87.1\text{ W}}$
- At $\Delta T = 10.0\text{ K}$ ($T_{\text{in}} = 40.0^\circ\text{C}$):
  - Free-Standing: $Q_s = 5.5 \times 4.768 \times 10.0 = \mathbf{262.2\text{ W}}$
  - Wall-Mounted: $Q_s = 5.5 \times 3.168 \times 10.0 = \mathbf{174.2\text{ W}}$

> **Conservative Design Philosophy**: In industrial food/starch processing plants subject to dust accumulation, high humidity, and seasonal ambient temperature excursions, engineering best practice sizes forced ventilation for **100% of the internal heat dissipation ($Q_v = Q_{\text{total}}$)** without relying on enclosure surface conduction.

---

## 3. Equipment Heat Dissipation Load Inventory ($P_{\text{internal}}$)

Each active electrical component installed inside the cabinet has been inventoried based on manufacturer datasheets:

| No. | Equipment Description | Catalog / Model | Qty | Unit Heat Loss (W) | Total Heat Loss (W) | Design Basis & Technical Reference |
| :---: | :--- | :--- | :---: | :---: | :---: | :--- |
| **1** | 24VDC 40A Industrial Power Supply | Phoenix Contact QUINT4-40A (or eq.) | 2 | 61.3 W | **122.6 W** | Rated 960W output @ 94% efficiency at 100% load |
| **2** | ControlLogix AC Chassis Power Supply | Rockwell 1756-PA75 | 1 | 25.0 W | **25.0 W** | Maximum internal heat dissipation (85.3 BTU/h) |
| **3** | ControlLogix 5580 Controller (40MB) | Rockwell 1756-L95 | 1 | 6.2 W | **6.2 W** | 100% execution cycle, embedded 1Gbps active |
| **4** | EtherNet/IP Dual-Port DLR Adapters | Rockwell 1756-EN4TR | 3 | 3.5 W | **10.5 W** | Gigabit dual-port adapter (11.9 BTU/h each) |
| **5** | ControlLogix Digital Input Modules | Rockwell 1756-IB32 | 4 | 5.5 W | **22.0 W** | 32-ch 24VDC sink/source input cards |
| **6** | ControlLogix Digital Output Modules | Rockwell 1756-OB32 | 2 | 4.8 W | **9.6 W** | 32-ch 24VDC sourcing output cards |
| **7** | ControlLogix Analog Input Modules | Rockwell 1756-IF16 | 2 | 6.2 W | **12.4 W** | 16-ch isolated analog input cards |
| **8** | Auxiliary Relays, MCBs & Diode Module | QUINT4-DIODE / PLC-RSC | Lot | 25.0 W | **25.0 W** | Diode module (10W), relay coils, terminal losses |
| --- | **SUBTOTAL ACTIVE EQUIPMENT HEAT** | --- | **15** | --- | **233.3 W** | **Continuous operating electrical heat load** |
| --- | **ENGINEERING SAFETY MARGIN (+15%)** | --- | --- | --- | **35.0 W** | **Cable Joule heating, aging & future expansion** |
| --- | **TOTAL DESIGN THERMAL LOAD ($Q_{\text{total}}$)** | --- | --- | --- | **268.3 W** | **$\mathbf{915.5\text{ BTU/h}}$ total heat dissipation** |

---

## 4. Thermodynamic Ventilation Sizing Equations & Calculation

The required forced air volume flow rate $V$ (in $\text{m}^3/\text{h}$) is calculated using the sensible heat balance equation:

$$V = \frac{f \cdot Q_v}{\Delta T} \quad [\text{m}^3/\text{h}]$$

Where:
- $Q_v$: Heat load to be dissipated by forced airflow ($W$).
- $\Delta T = T_{\text{internal}} - T_{\text{ambient}}$: Permissible temperature rise inside the enclosure ($K$ or $^\circ\text{C}$).
- $f$: Specific thermal constant of atmospheric air at sea level ($T = 20^\circ\text{C}$, $\rho = 1.204\text{ kg}/\text{m}^3$, $c_p = 1005\text{ J}/(\text{kg}\cdot\text{K})$):
  $$f = \frac{1}{\rho \cdot c_p} = \frac{3600\text{ s/h}}{1.204\text{ kg/m}^3 \times 1005\text{ W}\cdot\text{s}/(\text{kg}\cdot\text{K})} \approx \mathbf{3.10\text{ m}^3\cdot\text{K}/(W\cdot\text{h})}$$
- $k_{\text{filter}} = 1.30$: Dust loading and filter impedance derating factor (+30% headroom):
  $$V_{\text{design}} = V_{\text{req}} \times 1.30$$

### Parametric Ventilation Analysis Table

| Operational Design Case | Internal Temp ($T_{\text{in}}$) | $\Delta T$ | Natural Convection ($Q_s$) | Net Heat ($Q_v$) | Required Pure Airflow ($V_{\text{pure}}$) | Design Airflow ($V_{\text{design}}$, +30%) | Compliance Status |
| :--- | :---: | :---: | :---: | :---: | :---: | :---: | :--- |
| **Case 1: Optimum Lifespan (Conservative)** | **35.0 °C** | **5.0 K** | 0.0 W (Cons.) | 268.3 W | **166.3 m³/h** | **216.2 m³/h** | **Target Operating Point (Safe for PLCs)** |
| **Case 2: Standard Industrial Limit (Cons.)** | **40.0 °C** | **10.0 K** | 0.0 W (Cons.) | 268.3 W | **83.2 m³/h** | **108.1 m³/h** | Standard industrial limit per IEC 61439-1 |
| **Case 3: Maximum Allowable (Cons.)** | **45.0 °C** | **15.0 K** | 0.0 W (Cons.) | 268.3 W | **55.4 m³/h** | **72.1 m³/h** | Emergency maximum threshold |
| **Case 4: Case 1 with Wall Conduction** | **35.0 °C** | **5.0 K** | 87.1 W | 181.2 W | **112.3 m³/h** | **146.0 m³/h** | Takes credit for wall conduction |
| **Case 5: Case 2 with Wall Conduction** | **40.0 °C** | **10.0 K** | 174.2 W | 94.1 W | **29.2 m³/h** | **37.9 m³/h** | Minimal ventilation required |

---

## 5. Visual Diagrams & Thermal Characteristics

### Enclosure Layout & Airflow Management Diagram
Enclosure Layout & Airflow Diagram

### Airflow Requirement vs. Internal Temperature Curve
Airflow vs Temperature Curve

---

## 6. Supplier Catalog Comparison & Equipment Selection

From the approved document **Primus Ventilation Systems** ([`x9100-eDrawing/Supplier/PrimusVentilation.pdf`](file:///Users/x92120/xApp-001/x260911-002-KalasinEngineering/x9100-eDrawing/Supplier/PrimusVentilation.pdf)), all filter fans and roof fans were evaluated against the design airflow of **216.2 m³/h**:

| Primus Model | Dimensions (mm) | Power Supply | Power (W / A) | Air Flow (m³/h) | Sound Level (dB) | Protection | Suitability & Selection Status |
| :--- | :---: | :---: | :---: | :---: | :---: | :---: | :--- |
| **PMV115N** (3") | 115 × 115 | 220VAC / 50Hz | 13 W / 0.10 A | 31 m³/h | 30 dB | IP54 | Insufficient airflow capacity |
| **PMV205N** (4") | 205 × 205 | 220VAC / 50Hz | 21 W / 0.11 A | 142 m³/h | 43 dB | IP54 | Fits Case 2 (40°C), marginal for Case 1 (35°C) |
| **PMV250N** (8") | **250 × 250** | **220VAC / 50Hz** | **49 W / 0.38 A** | **428 m³/h** | **56 dB** | **IP54** | **SELECTED PRIMARY FAN (1.98× safety factor)** |
| **PMV320N** (10") | 320 × 320 | 220VAC / 50Hz | 87 W / 0.40 A | 654 m³/h | 80 dB | IP54 | High acoustic noise (80 dB), oversized |
| **PMV12** | 120 × 120 | 220VAC / 50Hz | 16 W / 0.13 A | 133 m³/h | 50 dB | IP54 | Undersized for conservative 35°C design |
| **PMV25** | **255 × 255** | **220VAC / 50Hz** | **38 W / 0.50 A** | **248 m³/h** | **58 dB** | **IP54** | **COMPACT ALTERNATIVE (Fits 35°C @ 216 m³/h)** |
| **PMV30.00S** | 323 × 323 | 220VAC / 50Hz | 40 W / 0.40 A | 428 m³/h | 69 dB | IP54 | Higher noise (69 dB) compared to PMV250N (56 dB) |
| **PMB03.00** | 364 × 364 | 220VAC / 50Hz | 85 W / 0.38 A | 905 m³/h | 64 dB | IP44 | Roof exhaust fan; alternative if door cutout blocked |

### Supplier Catalog Clippings
| Fan Models (PMV-N & PMB Series) | Thermostats & Controllers (CMA Series) |
| :---: | :---: |
| Primus Fan Catalog | Primus Thermostats |

---

## 7. Recommended Bill of Materials (BOM)

| Item | Component Description | Model / Catalog Code | Qty | Supplier | Technical Specification & Key Function |
| :---: | :--- | :--- | :---: | :---: | :--- |
| **1** | Industrial Cabinet Filter Fan | **PMV250N** | 1 Set | Primus | 250 × 250 mm, 220VAC 50Hz, 49W, 428 m³/h, IP54, 56 dB, Clips-Lock & Flap-Open front door |
| **2** | Matching Exhaust Filter Grille | **PMF250N** | 1 Set | Primus | 250 × 250 mm matching frame, G4 synthetic fiber filter mat, IP54 polyurethane seal |
| **3** | Cabinet Thermostat Controller | **CMA-001** | 1 Set | Primus | DIN-Rail bimetallic mechanical thermostat, 18–87 °C, NO contact for fan control, 220VAC 10A |
| **4** | Spare Replacement Filter Mat | **PMM-250N (G4)** | 2 Pcs | Primus | G4 / EU4 synthetic filter mat, washable, low pressure drop |
| **5** | Fan Power Protection MCB | **C60H-2P 2A C-Curve** | 1 Pcs | Schneider | 2-Pole 2A miniature circuit breaker for 220VAC fan auxiliary supply branch |

---

## 8. Installation, Airflow Path & Maintenance Guidelines

1. **Airflow Pathway Configuration (Positive Pressure vs. Exhaust)**:
   - **Air Intake Location**: Install the **PMF250N** filter grille at the **bottom of the front door** (or bottom side panel), at least 200 mm above the floor plinth to avoid floor dust suction.
   - **Exhaust Location**: Install the **PMV250N** filter fan at the **top of the front door** (or top side panel), blowing hot air outwards.
   - **Natural Chimney Convection**: Cool ambient air sweeps upward from the bottom, absorbs heat from the 40A DC power supplies mounted on lower DIN rails, cools the 1756 ControlLogix chassis in the middle section, and is actively evacuated at the top.
2. **Thermostat Placement & Control Strategy**:
   - Mount the **Primus CMA-001** thermostat on the top DIN rail near the warmest zone above the 1756 rack.
   - Set the dial to **35.0 °C**. The fan will automatically energize when internal temperature reaches 35.0 °C and turn off when the temperature drops to ~30.0 °C.
   - **Operational Advantages**: Prevents 24/7 continuous fan spinning, saves ~70% auxiliary power, extends bearing life beyond 50,000 hours, and significantly reduces dust accumulation on the filter mats.
3. **Preventive Maintenance**:
   - Inspect and clean/replace filter mats every **3 months** in starch processing plant environments.
   - The Primus **Flap-Open** front door allows maintenance technicians to replace the filter mat in under 30 seconds without opening high-voltage panel doors or using tools.

---

## 9. Verification & Quality Sign-Off

| Engineering Role | Name / Title | Organization | Status / Signature |
| :--- | :--- | :--- | :--- |
| **Calculated By** | Senior Thermal & Automation Engineer | Kalasin Engineering Co., Ltd. | Verified & Approved (10-Oct-2026) |
| **Reviewed By** | Lead Electrical Systems Engineer | Kalasin Engineering Co., Ltd. | Verified & Approved (10-Oct-2026) |
| **Client Verification** | Plant Automation Manager | Ingredion (Thailand) Co., Ltd. | Pending FAT Inspection |
| **Compliance Rating** | IEC 60890 / IEC 61439-1 / DIN 57660 | Industrial Automation Enclosures | **PASS (Technical Compliance Confirmed)** |

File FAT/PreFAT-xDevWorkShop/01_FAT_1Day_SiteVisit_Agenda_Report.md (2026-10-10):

# FACTORY ACCEPTANCE TEST (FAT) — 1-DAY SITE VISIT AGENDA REPORT
## Ingredion Thailand — SPRINT 18K TPA Spray Dryer Plant (Kalasin)
### Focus Area: Main Control Panel (MCP-01) — ControlLogix 5580 Chassis C1, C2, C3, C4
**Document Ref**: `KAL-FAT-AGN-2608-C1C4` | **Revision**: `Rev 1.1 (Focus: C1–C4)`  
**Venue**: xDev Engineering Workshop (Integration & Testing Center)  
**Execution Concept**: High-Impact 1-Day Audited FAT & Interactive Site Visit  
**Target Hardware**: 4x Rockwell ControlLogix 1756 13-Slot Chassis (C1, C2, C3, C4 in MCP-01), Cisco Catalyst 9300 Redundant Core, Stratix 5700 DLR Ring, FactoryTalk View SE SCADA, Pepperl+Fuchs K-System IS Barriers

---

## 1. Executive Summary & C1–C4 FAT Architecture

### 1.1 The C1–C4 1-Day Site Visit Concept
The core brain of the **SPRINT 18K TPA Spray Dryer Plant** is housed in **Main Control Panel MCP-01**, consisting of **four 13-slot ControlLogix 1756 chassis (C1, C2, C3, and C4)** interconnected via a 100Mbps ODVA Device Level Ring (DLR) and dual Cisco Catalyst 9300 Core switches.

| Chassis ID | Role / Subsystem | Primary Hardware | I/O Count in C1–C4 | Destination Field Enclosures |
| :---: | :--- | :--- | :---: | :--- |
| **C1** | **Master Controller & Core I/O** | `1756-L950TPSXT` CPU, 3x `1756-EN4TR`, 4x DI, 2x DO, 2x AI | 128 DI, 64 DO, 32 AI | Central Area 1 (CA1), JB-401, JB-601 |
| **C2** | **Main Process RIO Chassis** | `1756-EN4TR` DLR Adapter, 5x DI, 3x DO, 4x AI | 160 DI, 96 DO, 64 AI | JB-402, JB-602, JB-607, CA1 |
| **C3** | **Extended Process & Analog Out** | `1756-EN4TR` DLR Adapter, 3x DI, 2x DO, 4x AI, 1x AO | 96 DI, 64 DO, 64 AI, 8 AO | JB-606, JB-612, JB-618, JB-402, JB-602 |
| **C4** | **Hazardous Area & IS Barriers** | `1756-EN4TR` DLR Adapter, 3x DI, 1x DO, 2x AI + P&F Barriers | 96 DI, 32 DO, 32 AI (All IS) | IS-JB-603, IS-JB-608, IS-JB-612, IS-JB-618 |
| **TOTAL** | **Chassis C1–C4 Combined** | **52 Slots (48 Populated / 4 Reserve)** | **480 DI, 256 DO, 192 AI, 8 AO (936 Total)** | **MCP-01 Local & Field JBs** |

```mermaid
flowchart TD
    subgraph MCP01 ["Main Control Panel MCP-01 (C1 - C4)"]
        direction TB
        C1["Chassis C1: Master CPU 1756-L950TPSXT<br/>DLR Supervisor + C1 Local I/O"]
        C2["Chassis C2: Process RIO (160 DI / 96 DO / 64 AI)<br/>JB-402, JB-602, JB-607"]
        C3["Chassis C3: Process RIO + Modulating AO<br/>JB-606, JB-612, JB-618"]
        C4["Chassis C4: Hazardous Area / IS RIO<br/>P&F Barriers -> IS-JB-603, 608, 612, 618"]
    end
    
    C1 <== "DLR Ring (Port 1/2)" ==> C2
    C2 <== "DLR Ring (Port 1/2)" ==> C3
    C3 <== "DLR Ring (Port 1/2)" ==> C4
    C4 <== "DLR Ring (Port 1/2)" ==> C1

    C1 --- CoreSwitch["Dual Cisco Catalyst 9300 HSRP Core Switch"]
    CoreSwitch --- SCADA["FactoryTalk View SE Redundant Server"]
```

---

## 2. Master FAT Timetable (Focus on C1–C4: 09:00 – 17:00)

| Time Window | Duration | Milestone / Agenda Item | Focus on Chassis C1–C4 Activities | Responsible | Location |
| :---: | :---: | :--- | :--- | :--- | :--- |
| **09:00 – 09:15** | 15 min | **Client Arrival & Welcome** | • Client reception & guest sign-in<br/>• Safety briefing & ESD protection check before entering MCP-01 bay | Safety Officer / Lead Host | Workshop Lobby / Conf A |
| **09:15 – 09:30** | **15 min** | **Detail on FAT (Kick-off)** | • **15-Min Briefing Focused on C1–C4**:<br/>  - 4-Chassis architecture & DLR ring topology<br/>  - Test criteria, Cat A vs B punch rules, sign-off workflow<br/>  - Distribution of C1–C4 slot drawings & test sheets | Project Manager / Lead Automation | Main Conference Room |
| **09:30 – 10:45** | 75 min | **Station 1: C1 & C2 Audit (Core PLC & Main Process)** | • **C1 Master CPU (Slot 0: 1756-L950TPSXT)**: Run mode status, firmware v34, memory & redundancy diagnostics<br/>• **Cisco 9300 & DLR Ring Test**: Unplug DLR Port 2 on C1S1; verify ring fault recovery in $< 3\text{ ms}$ with C2, C3, C4 staying online<br/>• **C1 & C2 DI Loop Simulation**: Toggle field dry contacts into 1756-IB32 (C1S4–S7 & C2S1–S5) via `TB-24VDC` rail; verify tag updates in Studio 5000<br/>• **C1 & C2 DO & Relay Test**: Force DO channels on 1756-OB32 (C1S8–S9 & C2S6–S8); verify `TBRL` relay coils `A1` and `TB-0VDC` return | Lead PLC Engineer / Client Inspector | Workshop Test Bay 1 (MCP-01: C1 & C2) |
| **10:45 – 12:00** | 75 min | **Station 2: C1 & C2 Analog Loops (4–20mA)** | • **C1 Analog Inputs (C1S10–S11)**: Fluke 789 5-point calibration (4, 8, 12, 16, 20mA) for Spray Dryer slurry feed & burner air flow<br/>• **C2 Analog Inputs (C2S9–S12)**: 64 AI channels audit; verify differential current loops (`IN-x` & `i RTN-x`) on 1756-IF16 cards<br/>• Verification of zero crosstalk, proper cable shield grounding, and scaling in Studio 5000 | Instrumentation Specialist / Client Rep | Workshop Test Bay 1 (MCP-01: C1 & C2) |
| **12:00 – 13:00** | 60 min | **Lunch Break & Discussion** | • Executive lunch & refreshments served in private dining room<br/>• Review morning C1/C2 test logs and prepare for C3/C4 afternoon testing | All Participants | Executive Dining Lounge |
| **13:00 – 14:15** | 75 min | **Station 3: C3 (Modulating AO) & C4 (P&F IS Barriers)** | • **Chassis C3 Extended Process**: DI (C3S1–S3), DO (C3S4–S5), AI (C3S6–S9)<br/>• **C3S12 Modulating AO (1756-OF8)**: Drive 4–20mA control valve setpoints; measure current output with precision DMM ($\pm 0.5\%$ tolerance)<br/>• **Chassis C4 Intrinsic Safety RIO**: Dedicated hazardous zone I/O (IS-JB-603, 608, 612, 618)<br/>• **Pepperl+Fuchs K-System Zener Barrier Audit**: Verify signal transmission integrity, galvanic isolation, and line fault detection (wire break) | Instrumentation & IS Specialist / Client Rep | Workshop Test Bay 2 (MCP-01: C3 & C4) |
| **14:15 – 15:00** | 45 min | **Station 4: SCADA Integration & Safety Trips** | • **FactoryTalk View SE SCADA**: Real-time HMI screens for C1–C4 tags, faceplates, alarms, and historical trends<br/>• **Safety Interlock Matrix**: Simulate high-temperature trip on C1/C2 AI; verify automatic burner shutdown and exhaust fan interlock<br/>• **Master Emergency Stop (E-Stop)**: De-energize safety relay; verify all DO outputs across C1–C4 drop to fail-safe state $< 50\text{ ms}$ | SCADA Software Lead / Client Process Eng | SCADA Control Station |
| **15:00 – 15:30** | **30 min** | **Coffee Break & Data Consolidation** | • Afternoon coffee break, artisan snacks, and fresh refreshments<br/>• Engineering team consolidates C1–C4 completed test sheets and prepares preliminary Punch List draft | All Participants (Eng team consolidates) | Hospitality Lounge / Office |
| **15:30 – 16:30** | 60 min | **Summary Meeting & Comments** | • Presentation of C1–C4 test results & overall pass rate ($100\%$ target)<br/>• Detailed review of Client Comments & Observations<br/>• Categorize findings: Category A (Must fix before dispatch) vs Category B (Site punch)<br/>• Assign action item owners, resolution due dates, and SAT alignment | PM, Lead Engineers & Client Delegation | Main Conference Room |
| **16:30 – 17:00** | 30 min | **FAT Protocol Sign-off & Departure** | • Formal endorsement & signing of FAT Certificate of Acceptance for MCP-01 (C1–C4)<br/>• Finalize packaging protection, crate shipping schedule, and client departure | Project Directors & Signatories | Main Conference Room |

---

## 3. C1–C4 Detailed Workstation & Testing Breakdown

### Station 1: Chassis C1 (Master CPU & DLR Supervisor)
- **Rack Configuration**: 13-Slot Chassis, Redundant Power Supplies
  - `Slot 0`: `1756-L950TPSXT` ControlLogix 5580 Processor (20MB memory, 1Gbps onboard port)
  - `Slots 1, 2, 3`: `1756-EN4TR` Ethernet/IP DLR communications modules
  - `Slots 4–7`: `1756-IB32` (128 DI channels) $\rightarrow$ Central Area CA1, Field JB-401, JB-601
  - `Slots 8–9`: `1756-OB32` (64 DO channels) $\rightarrow$ Interposing relays `TBRL1` & `TBRL2`
  - `Slots 10–11`: `1756-IF16` (32 AI channels) $\rightarrow$ Analog transmitters from JB-401 & JB-601
- **Key Test Actions**:
  1. CPU power-up, memory utilization check, firmware revision match.
  2. DLR Ring supervisor status on C1S1: Perform cable break test; verify zero I/O dropping.
  3. DI/DO loop sampling: Verify paired `TB-24VDC` (power) and `TB-0VDC` (return) wiring.

### Station 2: Chassis C2 (Main Process Remote I/O)
- **Rack Configuration**: 13-Slot Chassis
  - `Slot 0`: `1756-EN4TR` DLR Adapter
  - `Slots 1–5`: `1756-IB32` (160 DI channels) $\rightarrow$ Feed preparation, JB-402, JB-602, JB-607
  - `Slots 6–8`: `1756-OB32` (96 DO channels) $\rightarrow$ Solenoids and pump start/stop relays
  - `Slots 9–12`: `1756-IF16` (64 AI channels) $\rightarrow$ Chamber pressure, inlet air temp, scrubber flow
- **Key Test Actions**:
  1. 160 DI / 96 DO loop simulation on representative valves and motors.
  2. 64 AI channel verification: 5-point calibration and differential return (`i RTN-x`) integrity.

### Station 3: Chassis C3 (Extended Process & Modulating Valves)
- **Rack Configuration**: 13-Slot Chassis
  - `Slot 0`: `1756-EN4TR` DLR Adapter
  - `Slots 1–3`: `1756-IB32` (96 DI channels) $\rightarrow$ Exhaust bag filter & powder handling (JB-606, 612, 618)
  - `Slots 4–5`: `1756-OB32` (64 DO channels) $\rightarrow$ Pulse jet valve timers and discharge gates
  - `Slots 6–9`: `1756-IF16` (64 AI channels) $\rightarrow$ Differential pressure across filters & cyclone temp
  - `Slot 12`: `1756-OF8` (8 AO channels) $\rightarrow$ 4–20mA modulating steam and burner valves
- **Key Test Actions**:
  1. Modulating valve output simulation: 0%, 25%, 50%, 75%, 100% current output verification.
  2. Pulse jet filter timer logic and sequential pulsing verification.

### Station 4: Chassis C4 (Hazardous Area / Intrinsic Safety with Pepperl+Fuchs)
- **Rack Configuration**: 13-Slot Chassis with Dedicated IS Barrier Trunking
  - `Slot 0`: `1756-EN4TR` DLR Adapter
  - `Slots 1–3`: `1756-IB32` (96 IS DI channels) $\rightarrow$ Namur proximity switches via P&F barriers
  - `Slot 4`: `1756-OB32` (32 IS DO channels) $\rightarrow$ Ex-proof pilot solenoids via P&F galvanic isolators
  - `Slots 5–6`: `1756-IF16` (32 IS AI channels) $\rightarrow$ Hazardous area temperature and pressure loops
  - Target Field JBs: `IS-JB-603`, `IS-JB-608`, `IS-JB-612`, `IS-JB-618`
- **Key Test Actions**:
  1. Pepperl+Fuchs K-System Zener barrier impedance and signal transparency check.
  2. Line fault detection (LFD): Disconnect field wire; verify red LED illuminates on barrier and alarm triggers in PLC/SCADA.

---

---

## 4. Special Testing Methodology: Automated DI/DO Closed-Loop Cross-Wiring Simulation

### 4.1 Principle & Physical Circuit Architecture
To verify with 100% certainty that the wiring from the **PLC DO Module to the Relay Coil (A1/A2)**, the **Relay Dry Contact (11/14)**, the **Relay Return Line (TB-0VDC)**, and the **DI Field Terminal to the PLC DI Module** are completely sound, an **Automated Closed-Loop Cross-Wiring Routine** is deployed:

```text
┌──────────────────────────────────────────────────────────────────────────────────────────────────┐
│                    AUTOMATED DI / DO CLOSED-LOOP CROSS-WIRING SIMULATION                         │
├──────────────────────────────────────────────────────────────────────────────────────────────────┤
│                                                                                                  │
│  [PLC 1756-OB32 Output] ──(24VDC Out)──> [Relay Coil A1] ──> [Relay Coil A2] ──> [TB-0VDC Rail] │
│                                                │                                                 │
│                                      (Mechanical Pull-in)                                        │
│                                                ▼                                                 │
│  [TB-24VDC Rail] ────> [Relay Common 11] ───[NO Contact 14]                                      │
│                                                   │                                              │
│                                     (Temporary Loopback Jumper)                                  │
│                                                   ▼                                              │
│                                        [DI Terminal Strip (TBDI)]                                │
│                                                   │                                              │
│                                                   ▼                                              │
│                                        [PLC 1756-IB32 Input] ──(Sense = 1 within <200ms)         │
│                                                                                                  │
└──────────────────────────────────────────────────────────────────────────────────────────────────┘
```

### 4.2 Automated Test Execution Sequence
1. **Automated Command (Trigger)**:
   - The Python Automation Test Engine / Studio 5000 FAT Routine commands the target DO channel to Force ON (`DO = 1`).
2. **Hardware Relay Energization**:
   - The `1756-OB32` output pin fires +24VDC to Relay Coil terminal `A1`. The interposing relay coil energizes, pulling down the mechanical armature and closing the Normally Open (NO) dry contact terminals `11` and `14`.
3. **Loopback Feedback**:
   - Positive +24VDC from the `TB-24VDC` distribution rail passes through the closed dry contact `11/14`, traverses the temporary cross-wiring jumper, and enters the paired DI terminal block (`TBDI`).
4. **DI Input Sensing & Latency Validation**:
   - The corresponding `1756-IB32` digital input channel detects +24VDC and transitions from `0` to `1`.
   - The test engine senses this feedback bit transition, validates that response latency is within limit (Delta t < 200 ms), and marks the loop as **PASS**.
5. **De-energization & Contact Opening Check**:
   - The test engine forces `DO = 0`. The relay de-energizes, the contact opens, and the DI bit drops back to `0`, confirming no welded contacts or sticky relays.
6. **Autogenerated Report**:
   - The results (DO Tag, Relay Tag, DI Tag, Timestamp, Response Latency, and Verdict) are automatically logged into the master database and rendered into an official PDF/Excel report.

### 4.3 Why This Guarantees 100% Wiring & Hardware Health
- **Complete End-to-End Validation**: Validates all 4 critical wiring segments simultaneously:
  1. PLC DO card output terminal to Relay coil `A1`.
  2. Relay coil `A2` to `TB-0VDC` power return line.
  3. Relay internal mechanical switching and dry contact (`11/14`) continuity.
  4. DI Terminal block wiring to PLC DI input card terminal.
- **Zero Human Error & High Speed**: Eliminates manual probing and reading errors. Automatically tests all 256 DO channels across C1–C4 in under 5 minutes.
- **Auditable & Tamper-Proof**: Produces an autogenerated certificate with exact response millisecond latencies.

---

## 5. C1–C4 Pre-FAT Readiness Checklist (Internal Workshop Protocol)

Before the client arrives at 09:00, the following items on Chassis C1–C4 must be 100% verified:

- [x] **Chassis Power & Redundancy**: Dual 24VDC power supply rails to C1, C2, C3, C4 tested for seamless failover.
- [x] **DLR Ring Continuity**: All 4 EN4TR modules enrolled in ring; ring supervisor active on C1S1; ring status normal (Ring Closed).
- [x] **Studio 5000 I/O Tree**: All 48 populated modules show green health icons with zero communication faults.
- [x] **DO Terminal Cleaning**: Verified all 9 DO cards (`C1S8`, `C1S9`, `C2S6`, `C2S7`, `C2S8`, `C3S4`, `C3S5`, `C4S4`) contain strictly genuine 32 DO channels with zero spurious `RTN OUT` rows.
- [x] **Pepperl+Fuchs Barrier Pre-check**: All K-System modules seated firmly on DIN rail with power rail energized and fault bus monitored.
- [x] **Test Equipment Staged at MCP-01**:
  - 2x Fluke 789 ProcessMeter (calibrated).
  - 1x Digital Multimeter (Fluke 87V).
  - 1x DI Simulation Toggle Switch Box (16-CH).
  - 1x DO Pilot Lamp Indicator Box (16-CH).

---

## 6. Formal Endorsement & Acceptance Protocol (C1–C4 Focus)

```text
========================================================================================
         FACTORY ACCEPTANCE TEST (FAT) ENDORSEMENT — CHASSIS C1, C2, C3, C4
========================================================================================

Project:  Ingredion Kalasin — SPRINT 18K TPA Spray Dryer Plant
Scope:    Main Control Panel (MCP-01) — ControlLogix Chassis C1, C2, C3, C4
Document: KAL-FAT-AGN-2608-C1C4 / Rev 1.1

Result Summary:
[  ] CHASSIS C1–C4 ACCEPTED WITHOUT RESERVATION
[  ] CHASSIS C1–C4 ACCEPTED SUBJECT TO CLEARANCE OF CATEGORY B PUNCH LIST ITEMS
[  ] CHASSIS C1–C4 REJECTED (CATEGORY A DEFECTS REQUIRE RE-TESTING)

Representative of Client / Owner:            Representative of Kalasin Engineering:

Signature: __________________________        Signature: __________________________
Name:      __________________________        Name:      __________________________
Title:     __________________________        Title:     __________________________
Date:      ______ / ______ / 2026            Date:      ______ / ______ / 2026
========================================================================================
```

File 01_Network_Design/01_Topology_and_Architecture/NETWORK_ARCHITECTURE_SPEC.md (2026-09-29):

# Industrial Network Architecture Specification
**Facility**: Ingredion Kalasin Spray Dryer Plant  
**Architecture Framework**: Cisco / Rockwell Automation Converged Plantwide Ethernet (CPwE)  

---

## 1. Network Topology Overview

The plant automation network employs a **Hierarchical Star with Redundant Device-Level Rings (DLR)**:

```
                  ┌────────────────────────────────────────┐
                  │ Level 3: FactoryTalk SCADA & Historian │
                  └───────────────────┬────────────────────┘
                                      │ (VLAN Trunk / 1Gbps Fiber)
                  ┌───────────────────┴────────────────────┐
                  │ Main Plant Distribution Switch (Core) │
                  │     Stratix 5400 / Cisco Catalyst      │
                  └─────────┬────────────────────┬─────────┘
                            │                    │ (Fiber Trunk / REP or RSTP)
            ┌───────────────┴────────┐  ┌────────┴───────────────┐
            │ Area 202/402 Switch    │  │ Area 602/814 Switch    │
            │ Stratix 5700 (SW-201)  │  │ Stratix 5700 (SW-601)  │
            └───┬────────────────────┘  └───┬────────────────────┘
                │                           │
       ┌────────┴────────┐         ┌────────┴────────┐
       │ DLR Ring 1      │         │ DLR Ring 2      │
       │ (Area 202/402)  │         │ (Area 602 Core) │
       │ ControlLogix    │         │ ControlLogix    │
       │ 1756-EN2TR      │         │ 1756-EN4TR      │
       │ 1734-AENTR I/O  │         │ PowerFlex VFDs  │
       │ PowerFlex 525   │         │ Remote Racks    │
       └─────────────────┘         └─────────────────┘
```

---

## 2. Network Segmentation & VLAN Definition

| VLAN ID | VLAN Name | Purpose | Subnet CIDR | Default Gateway |
|:---:|---|---|---|---|
| **VLAN 10** | `VLAN_SCADA_SRV` | FactoryTalk SE Servers, Historian, Batch Server | `192.168.10.0/24` | `192.168.10.1` |
| **VLAN 20** | `VLAN_HMI_CLIENT` | PanelView 5510, Area ThinManager Thin Clients, EWS | `192.168.20.0/24` | `192.168.20.1` |
| **VLAN 30** | `VLAN_PLC_CONTROL` | ControlLogix 5580 Process & Safety Controller Racks | `192.168.30.0/24` | `192.168.30.1` |
| **VLAN 40** | `VLAN_IO_AREA202` | Area 202 Pre-Slurry Remote I/O & Pumps (DLR 1) | `192.168.40.0/24` | `192.168.40.1` |
| **VLAN 42** | `VLAN_IO_AREA402` | Area 402 Adjustment Remote I/O & Valves | `192.168.42.0/24` | `192.168.42.1` |
| **VLAN 60** | `VLAN_IO_AREA602` | Area 602 Spray Dryer Burner & Core RIO (DLR 2) | `192.168.60.0/24` | `192.168.60.1` |
| **VLAN 80** | `VLAN_IO_AREA814` | Area 814 CIP Skid RIO & Dosing Pumps | `192.168.80.0/24` | `192.168.80.1` |
| **VLAN 99** | `VLAN_MGMT_SWITCH` | Industrial Switch Management (SSH/SNMP/HTTPS) | `192.168.99.0/24` | `192.168.99.1` |

---

## 3. Industrial Protocols & QoS Traffic Prioritization

* **CIP (Common Industrial Protocol) / EtherNet/IP**:
  - Class 1 Implicit I/O: UDP Port 2222 (Highest priority, DSCP 47/59 - Expedited Forwarding).
  - Class 3 Explicit Messaging: TCP Port 44818 (Medium priority, DSCP 0 - Best Effort).
  - PTP (IEEE 1588 / CIP Sync): Synchronization across motion & sequence timestamps.
* **IGMP Snooping & Querying**: Enabled on all Stratix switches to prevent EtherNet/IP multicast flooding.

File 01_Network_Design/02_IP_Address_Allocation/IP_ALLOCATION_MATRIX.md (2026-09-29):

# Plant-Wide IP Address Allocation Matrix
**Project**: Ingredion Kalasin — Sprint 18K TPA Spray Dryer Plant  
**Subnet Mask (Class C Standard)**: `255.255.255.0` (`/24`)  

---

## 1. 5-Chassis ControlLogix DLR Ring & Controller Allocation (VLAN 30: `192.168.30.0/24`)

| IP Address | Device Tag | Chassis / Slot | Hardware Model | DLR / Network Role | Panel Location |
|---|---|---|---|---|---|
| `192.168.30.1`  | `GW-COR-01` | Core Switch L3 SVI | Stratix 5400 | Plant Default Gateway | Server Rack |
| `192.168.30.10` | `PLC-01-CPU` | CS1 Slot 00 | 1756-L950TPSXT | Master Process Safety Controller (XT) | Main Control Panel (MCP-01) |
| `192.168.30.11` | `CS1-EN4TR-DLR`| CS1 Slot 01 | 1756-EN4TR | **Active Ring Supervisor (Beacon Port 2)** | Main Control Panel (MCP-01) |
| `192.168.30.12` | `CS2-EN4TR` | CS2 Slot 00 | 1756-EN4TR | Remote I/O Adapter (Ring Node 1) | Main Control Panel (MCP-01) |
| `192.168.30.13` | `CS3-EN4TR` | CS3 Slot 00 | 1756-EN4TR | Remote I/O Adapter (Ring Node 2) | Main Control Panel (MCP-01) |
| `192.168.30.14` | `CS4-EN4TR` | CS4 Slot 00 | 1756-EN4TR | Remote I/O Adapter (Ring Node 3) | Main Control Panel (MCP-01) |
| `192.168.30.15` | `CS5-EN4TR` | CS5 Slot 00 | 1756-EN4TR | Remote I/O Adapter (Ring Node 4 via Fiber) | Remote Panel (RIO200) |
| `192.168.30.20` | `PLC-01-EN4T2` | CS1 Slot 02 | 1756-EN4TR | Plant SCADA / FactoryTalk Uplink | Main Control Panel (MCP-01) |
| `192.168.30.250`| `MC-01-MCP` | Din-Rail MCP-01 | 1783-ETAP2F / Stratix | Fiber DLR Tap / Transceiver (MCP side) | Main Control Panel (MCP-01) |
| `192.168.30.251`| `MC-02-RIO` | Din-Rail RIO200 | 1783-ETAP2F / Stratix | Fiber DLR Tap / Transceiver (RIO side) | Remote Panel (RIO200) |
| `192.168.30.50` | `HMI-MCP-01` | Door Panel | PanelView 5510 15" | Operator Touchscreen HMI | Main Control Panel (MCP-01) |

---

## 2. Area 202 & 402 Pre-Slurry & Adjustment (VLAN 40: `192.168.40.0/24`)

| IP Address | Device Tag | Device Description | Connected Equipment | Hardware Model |
|---|---|---|---|---|
| `192.168.40.1` | `GW-SW201` | Gateway / Switch SVI | Area 202 RIO Panel (RIO-202) | Stratix 5700 |
| `192.168.40.10`| `RIO-202-AENT`| Remote I/O Adapter 1 (Pre-Slurry TS2020) | `XV-20202`, `XV-20203`, `LT-20201` | 1734-AENTR |
| `192.168.40.11`| `RIO-202-AENT2`| Remote I/O Adapter 2 (Pre-Slurry TS2021) | `XV-20212`, `XV-20213`, `LT-20211` | 1734-AENTR |
| `192.168.40.21`| `VFD-PC-20201` | Slurry Transfer Pump 1 VFD (18.5 kW) | Slurry Pump `PC-20201` | PowerFlex 525 |
| `192.168.40.22`| `VFD-PC-20211` | Slurry Transfer Pump 2 VFD (18.5 kW) | Slurry Pump `PC-20211` | PowerFlex 525 |
| `192.168.40.31`| `VFD-ME-20201` | Slurry Agitator VFD (15 kW) | Slurry Agitator `ME-20201` | PowerFlex 525 |
| `192.168.40.32`| `VFD-ME-20211` | Slurry Agitator VFD (15 kW) | Slurry Agitator `ME-20211` | PowerFlex 525 |
| `192.168.40.50`| `FM-FT-20201` | Coriolis Mass Flowmeter | Transfer Flow to Area 402 | E+H Promass 300 |

---

## 3. Area 602 Spray Dryer & Atomization (VLAN 60: `192.168.60.0/24`)

| IP Address | Device Tag | Device Description | Connected Equipment | Hardware Model |
|---|---|---|---|---|
| `192.168.60.1` | `GW-SW601` | Gateway / Switch SVI | Dryer Main Panel (MCP-602) | Stratix 5700 |
| `192.168.60.10`| `RIO-602-AENT1`| Dryer Chamber RIO Rack (DLR Node 1) | Burner permissives, Temp transmitters | 1734-AENTR |
| `192.168.60.11`| `RIO-602-AENT2`| Exhaust & Cyclone RIO Rack (DLR Node 2)| Cyclone dampers, Baghouse pulses | 1734-AENTR |
| `192.168.60.20`| `VFD-PUPD-11`  | High Pressure Feed Pump (75 kW) | HP Atomizer Feed `PUPD-11` | PowerFlex 755 |
| `192.168.60.21`| `VFD-FN-60201` | Main Supply Air Fan VFD (110 kW) | Combustion Air Fan `FN-60201` | PowerFlex 755 |
| `192.168.60.22`| `VFD-FN-60202` | Exhaust Air Fan VFD (132 kW) | Main Exhaust Fan `FN-60202` | PowerFlex 755 |

---

## 4. Area 814 Plant CIP Skid (VLAN 80: `192.168.80.0/24`)

| IP Address | Device Tag | Device Description | Connected Equipment | Hardware Model |
|---|---|---|---|---|
| `192.168.80.1` | `GW-SW801` | Gateway / Switch SVI | CIP Skid Panel (CIP-01) | Stratix 5700 |
| `192.168.80.10`| `RIO-814-AENT` | CIP Skid Remote I/O Adapter | Routing Valves `XV-814xx` | 1734-AENTR |
| `192.168.80.20`| `VFD-PC-81401` | CIP Forward Supply Pump (22 kW) | CIP Supply `PC-81401` | PowerFlex 525 |
| `192.168.80.21`| `VFD-PC-81402` | CIP Scavenge Return Pump (15 kW) | CIP Return `PC-81402` | PowerFlex 525 |
| `192.168.80.30`| `CT-81401` | CIP Conductivity Transmitter | Caustic/Acid return rinse | E+H Smartec CLD18 |

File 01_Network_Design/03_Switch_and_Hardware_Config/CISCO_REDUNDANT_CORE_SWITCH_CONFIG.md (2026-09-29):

# Cisco Redundant Core Switch Configuration Specification
**Facility**: Ingredion Kalasin Spray Dryer Plant  
**Architecture**: Cisco / Rockwell Automation CPwE (Converged Plantwide Ethernet)  
**Hardware Platform**: Redundant Cisco Catalyst 9300-24T / 9300-48T (or Cisco Industrial Ethernet IE-5000 / Stratix 5400)  
**Redundancy Protocols**: HSRP (Hot Standby Router Protocol v2), LACP (IEEE 802.3ad Port-Channel), Rapid-PVST+ (IEEE 802.1w)  

---

## 1. High Availability & Redundancy Architecture

```text
               ┌────────────────────────────────────────────────────────┐
               │              REDUNDANT SERVER INFRASTRUCTURE           │
               │  [FT View SE Server 01 (Pri)]   [FT View SE Server 02 (Sec)]   │
               │   NIC 1 (Active)  NIC 2 (Standby) NIC 1 (Standby) NIC 2 (Active)│
               └─────────┬───────────────┬──────────────┬───────────────┬───────┘
                         │ (LACP Teaming)│              │               │
                         ▼               │              ▼               │
               ┌──────────────────┐      │     ┌──────────────────┐     │
               │  SW-CORE-01      │◄─────┼────►│  SW-CORE-02      │◄────┘
               │  Cisco Core SW 1 │      └────►│  Cisco Core SW 2 │
               │  (HSRP Priority) │            │  (HSRP Standby)  │
               └────────┬─────────┘            └────────┬─────────┘
                        │                               │
   ┌────────────────────┴───────────────────────────────┴────────────────────┐
   │                                                                         │
   ▼ (Fiber Optic Backbone Trunk)                                            ▼ (Copper/Fiber 802.1Q Trunk)
┌─────────────────────────────────┐                       ┌─────────────────────────────────┐
│ EXISTING SERVER ROOM            │                       │ MCC ROOM (MOTOR CONTROL CENTER) │
│ • FDF-SR01 Fiber Patch Panel    │                       │ • SW-MCC-01 (Stratix / Cisco IE)│
│ • Domain Controllers DC01/DC02  │                       │ • PowerFlex 755/525 VFDs (VLAN50)│
│ • Historian / Batch Archives    │                       │ • Power Meter 1408-BC3A         │
└─────────────────────────────────┘                       └─────────────────────────────────┘
```

---

## 2. IP Addressing & HSRP Default Gateway Plan

| VLAN ID | VLAN Name | Subnet / CIDR | Virtual IP (HSRP VIP) | SW-CORE-01 (Active) | SW-CORE-02 (Standby) |
|:---:|---|---|:---:|:---:|:---:|
| **VLAN 10** | `VLAN_SCADA_SRV` | `192.168.10.0/24` | `192.168.10.1` (VIP) | `192.168.10.2` (Pri: 110) | `192.168.10.3` (Pri: 100) |
| **VLAN 20** | `VLAN_HMI_CLIENT`| `192.168.20.0/24` | `192.168.20.1` (VIP) | `192.168.20.2` (Pri: 110) | `192.168.20.3` (Pri: 100) |
| **VLAN 30** | `VLAN_PLC_CONTROL`| `192.168.30.0/24`| `192.168.30.1` (VIP) | `192.168.30.2` (Pri: 110) | `192.168.30.3` (Pri: 100) |
| **VLAN 50** | `VLAN_MCC_DRIVES` | `192.168.50.0/24` | `192.168.50.1` (VIP) | `192.168.50.2` (Pri: 110) | `192.168.50.3` (Pri: 100) |
| **VLAN 99** | `VLAN_MGMT` | `192.168.99.0/24` | - | `192.168.99.2` | `192.168.99.3` |

---

## 3. Cisco SW-CORE-01 Configuration (Primary Core Switch)

```cisco
! ==============================================================================
! CISCO IOS-XE CONFIGURATION: SW-CORE-01 (PRIMARY / ACTIVE HSRP GATEWAY)
! ==============================================================================
hostname SW-CORE-01
no ip domain-lookup
ip domain-name ingredion.local

! --- 1. Global Services & Spanning Tree ---
spanning-tree mode rapid-pvst
spanning-tree portfast default
spanning-tree portfast bpduguard default
! Set SW-CORE-01 as primary STP root for all VLANs
spanning-tree vlan 1-99 root primary

! --- 2. VLAN Definitions ---
vlan 10
 name VLAN_SCADA_SRV
!
vlan 20
 name VLAN_HMI_CLIENT
!
vlan 30
 name VLAN_PLC_CONTROL
!
vlan 50
 name VLAN_MCC_DRIVES
!
vlan 99
 name VLAN_MGMT
!
vlan 999
 name VLAN_QUARANTINE_UNUSED
!

! --- 3. Inter-Switch Link (ISL Cross-Connect: Port-Channel 1) ---
! Dual 10Gbps or 1Gbps bonded links between SW-CORE-01 and SW-CORE-02
interface range TenGigabitEthernet1/0/1 - 2
 description ISL-TRUNK-TO-SW-CORE-02
 switchport mode trunk
 switchport trunk encapsulation dot1q
 switchport trunk allowed vlan 10,20,30,50,99
 channel-group 1 mode active
 no shutdown
!
interface Port-channel 1
 description ISL-PORT-CHANNEL-TRUNK
 switchport mode trunk
 switchport trunk allowed vlan 10,20,30,50,99
 no shutdown
!

! --- 4. Redundant Server Dual-Homed Ports (NIC Teaming / LACP) ---
! Primary SCADA Server 01 (Port-Channel 10)
interface GigabitEthernet1/0/1
 description FT-VIEW-SERVER-01_NIC1
 switchport mode access
 switchport access vlan 10
 channel-group 10 mode active
 spanning-tree portfast
 no shutdown
!
interface Port-channel 10
 description FT-VIEW-SERVER-01_TEAM_A
 switchport mode access
 switchport access vlan 10
 spanning-tree portfast
 no shutdown
!
! Secondary SCADA Server 02 (Cross-connected port)
interface GigabitEthernet1/0/2
 description FT-VIEW-SERVER-02_NIC2
 switchport mode access
 switchport access vlan 10
 channel-group 11 mode active
 spanning-tree portfast
 no shutdown
!
interface Port-channel 11
 description FT-VIEW-SERVER-02_TEAM_A
 switchport mode access
 switchport access vlan 10
 spanning-tree portfast
 no shutdown
!

! --- 5. Fiber Uplink to Existing Server Room (SFP Module) ---
interface TenGigabitEthernet1/1/1
 description FIBER-UPLINK-TO-SERVER-ROOM-FDF01
 switchport mode trunk
 switchport trunk allowed vlan 10,20,99
 speed nonegotiate
 no shutdown
!

! --- 6. Trunk to MCC Room (PowerFlex VFDs & Motor Starters) ---
interface GigabitEthernet1/0/24
 description TRUNK-TO-MCC-ROOM-SW-MCC-01
 switchport mode trunk
 switchport trunk allowed vlan 30,50,99
 switchport trunk native vlan 99
 spanning-tree portfast trunk
 no shutdown
!

! --- 7. Uplink to Main Control Panel (MCP-01 ControlLogix CS1) ---
interface GigabitEthernet1/0/12
 description UPLINK-TO-MCP01-CS1-EN4TR-S02
 switchport mode access
 switchport access vlan 30
 spanning-tree portfast
 no shutdown
!

! --- 8. Layer 3 SVI & HSRP v2 Gateway Configuration ---
ip routing
!
interface Vlan10
 description SVI_SCADA_SERVERS
 ip address 192.168.10.2 255.255.255.0
 standby version 2
 standby 10 ip 192.168.10.1
 standby 10 priority 110
 standby 10 preempt
 standby 10 authentication md5 key-string IngredionKalasin#10
 no shutdown
!
interface Vlan20
 description SVI_HMI_CLIENTS
 ip address 192.168.20.2 255.255.255.0
 standby version 2
 standby 20 ip 192.168.20.1
 standby 20 priority 110
 standby 20 preempt
 standby 20 authentication md5 key-string IngredionKalasin#20
 no shutdown
!
interface Vlan30
 description SVI_PLC_CONTROL
 ip address 192.168.30.2 255.255.255.0
 standby version 2
 standby 30 ip 192.168.30.1
 standby 30 priority 110
 standby 30 preempt
 standby 30 authentication md5 key-string IngredionKalasin#30
 no shutdown
!
interface Vlan50
 description SVI_MCC_DRIVES
 ip address 192.168.50.2 255.255.255.0
 standby version 2
 standby 50 ip 192.168.50.1
 standby 50 priority 110
 standby 50 preempt
 standby 50 authentication md5 key-string IngredionKalasin#50
 no shutdown
!
interface Vlan99
 description SVI_IN_BAND_MGMT
 ip address 192.168.99.2 255.255.255.0
 no shutdown
!

! --- 9. Industrial EtherNet/IP CIP Multicast Management ---
ip igmp snooping
ip igmp snooping querier
ip igmp snooping vlan 30 querier address 192.168.30.2
ip igmp snooping vlan 50 querier address 192.168.50.2
!
end
write memory
```

---

## 4. Cisco SW-CORE-02 Configuration (Secondary / Standby Core Switch)

```cisco
! ==============================================================================
! CISCO IOS-XE CONFIGURATION: SW-CORE-02 (SECONDARY / STANDBY HSRP GATEWAY)
! ==============================================================================
hostname SW-CORE-02
no ip domain-lookup
ip domain-name ingredion.local

! --- 1. Global Services & Spanning Tree ---
spanning-tree mode rapid-pvst
spanning-tree portfast default
spanning-tree portfast bpduguard default
! Set SW-CORE-02 as secondary STP root for fast failover
spanning-tree vlan 1-99 root secondary

! --- 2. VLAN Definitions ---
vlan 10
 name VLAN_SCADA_SRV
!
vlan 20
 name VLAN_HMI_CLIENT
!
vlan 30
 name VLAN_PLC_CONTROL
!
vlan 50
 name VLAN_MCC_DRIVES
!
vlan 99
 name VLAN_MGMT
!
vlan 999
 name VLAN_QUARANTINE_UNUSED
!

! --- 3. Inter-Switch Link (ISL Cross-Connect: Port-Channel 1) ---
interface range TenGigabitEthernet1/0/1 - 2
 description ISL-TRUNK-TO-SW-CORE-01
 switchport mode trunk
 switchport trunk encapsulation dot1q
 switchport trunk allowed vlan 10,20,30,50,99
 channel-group 1 mode active
 no shutdown
!
interface Port-channel 1
 description ISL-PORT-CHANNEL-TRUNK
 switchport mode trunk
 switchport trunk allowed vlan 10,20,30,50,99
 no shutdown
!

! --- 4. Redundant Server Dual-Homed Ports (NIC Teaming / LACP) ---
! Secondary connection for Server 01 (Port-Channel 10)
interface GigabitEthernet1/0/1
 description FT-VIEW-SERVER-01_NIC2
 switchport mode access
 switchport access vlan 10
 channel-group 10 mode active
 spanning-tree portfast
 no shutdown
!
interface Port-channel 10
 description FT-VIEW-SERVER-01_TEAM_B
 switchport mode access
 switchport access vlan 10
 spanning-tree portfast
 no shutdown
!
! Primary connection for Server 02 (Port-Channel 11)
interface GigabitEthernet1/0/2
 description FT-VIEW-SERVER-02_NIC1
 switchport mode access
 switchport access vlan 10
 channel-group 11 mode active
 spanning-tree portfast
 no shutdown
!
interface Port-channel 11
 description FT-VIEW-SERVER-02_TEAM_B
 switchport mode access
 switchport access vlan 10
 spanning-tree portfast
 no shutdown
!

! --- 5. Redundant Fiber Uplink to Server Room ---
interface TenGigabitEthernet1/1/1
 description FIBER-UPLINK-TO-SERVER-ROOM-FDF02
 switchport mode trunk
 switchport trunk allowed vlan 10,20,99
 speed nonegotiate
 no shutdown
!

! --- 6. Redundant Trunk to MCC Room ---
interface GigabitEthernet1/0/24
 description REDUNDANT-TRUNK-TO-MCC-ROOM
 switchport mode trunk
 switchport trunk allowed vlan 30,50,99
 switchport trunk native vlan 99
 spanning-tree portfast trunk
 no shutdown
!

! --- 7. Layer 3 SVI & HSRP v2 Gateway Configuration ---
ip routing
!
interface Vlan10
 description SVI_SCADA_SERVERS
 ip address 192.168.10.3 255.255.255.0
 standby version 2
 standby 10 ip 192.168.10.1
 standby 10 priority 100
 standby 10 preempt
 standby 10 authentication md5 key-string IngredionKalasin#10
 no shutdown
!
interface Vlan20
 description SVI_HMI_CLIENTS
 ip address 192.168.20.3 255.255.255.0
 standby version 2
 standby 20 ip 192.168.20.1
 standby 20 priority 100
 standby 20 preempt
 standby 20 authentication md5 key-string IngredionKalasin#20
 no shutdown
!
interface Vlan30
 description SVI_PLC_CONTROL
 ip address 192.168.30.3 255.255.255.0
 standby version 2
 standby 30 ip 192.168.30.1
 standby 30 priority 100
 standby 30 preempt
 standby 30 authentication md5 key-string IngredionKalasin#30
 no shutdown
!
interface Vlan50
 description SVI_MCC_DRIVES
 ip address 192.168.50.3 255.255.255.0
 standby version 2
 standby 50 ip 192.168.50.1
 standby 50 priority 100
 standby 50 preempt
 standby 50 authentication md5 key-string IngredionKalasin#50
 no shutdown
!
interface Vlan99
 description SVI_IN_BAND_MGMT
 ip address 192.168.99.3 255.255.255.0
 no shutdown
!

! --- 8. Industrial EtherNet/IP CIP Multicast Management ---
ip igmp snooping
ip igmp snooping querier
ip igmp snooping vlan 30 querier address 192.168.30.3
ip igmp snooping vlan 50 querier address 192.168.50.3
!
end
write memory
```

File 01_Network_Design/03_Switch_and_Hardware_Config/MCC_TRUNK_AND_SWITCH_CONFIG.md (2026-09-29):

# MCC Room Trunk & Switch Configuration Specification
**Facility**: Ingredion Kalasin Spray Dryer Plant  
**MCC Switch Tag**: `SW-MCC-01` (Allen-Bradley Stratix 5700 `1783-BMS10CGN` / Cisco IE-4000)  
**Location**: Motor Control Center (MCC) Room  
**Trunk Link**: Dual/Single 802.1Q VLAN Trunk from Central Cisco Core Switches  

---

## 1. MCC Room Network Architecture & Port Schedule

```text
               ┌─────────────────────────────────────────────────┐
               │ Central Cisco Core Switches (Operation Room)     │
               │ SW-CORE-01 (Gi1/0/24)    SW-CORE-02 (Gi1/0/24)  │
               └─────────┬───────────────────────────────┬───────┘
                         │                               │
                         ▼ (Trunk Cable 1)               ▼ (Trunk Cable 2 / Standby STP)
               ┌─────────────────────────────────────────────────┐
               │ SW-MCC-01: Industrial Managed Switch (MCC Room) │
               │ Stratix 5700 (1783-BMS10CGN) / IP: 192.168.50.10│
               └─────────┬───────────────────────────────┬───────┘
                         │                               │
        ┌────────────────┼───────────────────────────────┼────────────────┐
        ▼ (Port 3)       ▼ (Port 4)                      ▼ (Port 5)       ▼ (Port 7)
┌──────────────┐ ┌──────────────┐                 ┌──────────────┐ ┌──────────────┐
│ PowerFlex 755│ │ PowerFlex 755│                 │ PowerFlex 525│ │ Power Meter  │
│ 110kW Fan    │ │ 132kW Fan    │                 │ 18.5kW Pump  │ │ 1408-BC3A    │
│ IP: .50.21   │ │ IP: .50.22   │                 │ IP: .50.31   │ │ IP: .50.50   │
└──────────────┘ └──────────────┘                 └──────────────┘ └──────────────┘
```

---

## 2. Port Allocation Table (`SW-MCC-01`)

| Port No. | Connector | Type | Connected Device | VLAN | IP Address | Notes |
|:---:|:---:|:---:|---|:---:|:---:|---|
| **Port 1** | RJ45 | **TRUNK** | Cisco Core `SW-CORE-01` (Gi1/0/24) | 30, 50, 99 | - | **Main MCC Trunk Link** |
| **Port 2** | RJ45 | **TRUNK** | Cisco Core `SW-CORE-02` (Gi1/0/24) | 30, 50, 99 | - | **Redundant MCC Trunk (STP)** |
| **Port 3** | RJ45 | Access | PowerFlex 755 (Supply Fan FN-60201) | VLAN 50 | `192.168.50.21` | 110 kW Combustion Air |
| **Port 4** | RJ45 | Access | PowerFlex 755 (Exhaust Fan FN-60202)| VLAN 50 | `192.168.50.22` | 132 kW Main Exhaust |
| **Port 5** | RJ45 | Access | PowerFlex 525 (Slurry Pump PC-20201)| VLAN 50 | `192.168.50.31` | 18.5 kW Transfer Pump 1 |
| **Port 6** | RJ45 | Access | PowerFlex 525 (Slurry Pump PC-20211)| VLAN 50 | `192.168.50.32` | 18.5 kW Transfer Pump 2 |
| **Port 7** | RJ45 | Access | Power Meter `1408-BC3A` | VLAN 50 | `192.168.50.50` | Main Incoming Power Meter |
| **Port 8** | RJ45 | Access | Spare / Maintenance Laptop | VLAN 50 | DHCP | Local Diagnostics |

---

## 3. Stratix 5700 / Cisco IE Switch Configuration Script

```cisco
! ==============================================================================
! CONFIGURATION FOR SW-MCC-01 (MCC ROOM INDUSTRIAL SWITCH)
! ==============================================================================
hostname SW-MCC-01
no ip domain-lookup
ip domain-name ingredion.local

! --- 1. Spanning Tree & VLANs ---
spanning-tree mode rapid-pvst
spanning-tree portfast default
spanning-tree portfast bpduguard default

vlan 30
 name VLAN_PLC_CONTROL
!
vlan 50
 name VLAN_MCC_DRIVES
!
vlan 99
 name VLAN_MGMT
!

! --- 2. Main Trunk Ports to Cisco Core Switches ---
interface FastEthernet1/1
 description TRUNK-TO-SW-CORE-01
 switchport mode trunk
 switchport trunk allowed vlan 30,50,99
 switchport trunk native vlan 99
 no shutdown
!
interface FastEthernet1/2
 description REDUNDANT-TRUNK-TO-SW-CORE-02
 switchport mode trunk
 switchport trunk allowed vlan 30,50,99
 switchport trunk native vlan 99
 no shutdown
!

! --- 3. PowerFlex VFD Drive Ports (VLAN 50) ---
interface range FastEthernet1/3 - 7
 switchport mode access
 switchport access vlan 50
 spanning-tree portfast
 storm-control broadcast level 2.0
 storm-control multicast level 5.0
 no shutdown
!

! --- 4. Switch Management SVI & Default Gateway ---
interface Vlan50
 description SVI_MCC_MANAGEMENT
 ip address 192.168.50.10 255.255.255.0
 no shutdown
!
ip default-gateway 192.168.50.1

! --- 5. EtherNet/IP CIP Multicast Optimization ---
ip igmp snooping
ip igmp snooping vlan 50
!
end
write memory
```

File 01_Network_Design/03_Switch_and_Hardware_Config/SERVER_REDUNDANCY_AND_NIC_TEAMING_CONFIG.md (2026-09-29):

# Server Redundancy & NIC Teaming Configuration Specification
**Facility**: Ingredion Kalasin Spray Dryer Plant  
**Applications**: Rockwell FactoryTalk View SE Distributed, FactoryTalk Historian SE, FactoryTalk Batch  
**OS Platform**: Microsoft Windows Server 2022 / 2025 Standard (Fault-Tolerant High-Availability Cluster)  

---

## 1. Physical Server Hardware & NIC Allocation

Each physical server (HPE ProLiant DL380 Gen10/Gen11 or Dell PowerEdge R750) is equipped with:
* **Dual Hot-Plug Redundant Power Supplies (1+1 PSUs)** connected to separate PDU feeds (UPS A & UPS B).
* **4x 10GbE/1GbE Network Interface Cards (NICs)**:
  - **NIC 1 (Plant LAN A)**: Connected to Cisco Core Switch `SW-CORE-01`.
  - **NIC 2 (Plant LAN B)**: Connected to Cisco Core Switch `SW-CORE-02`.
  - **NIC 3 (Dedicated Heartbeat / Inter-Server Sync)**: Direct high-speed cross-connect cable between Server 01 and Server 02.
  - **NIC 4 (iLO / iDRAC Out-of-Band Management)**: Connected to Management Switch (`VLAN 99`).

---

## 2. Windows Server NIC Teaming (LACP / Switch Independent)

### PowerShell Configuration for Switch-Independent Active/Standby Team:
```powershell
# Create NIC Team with Active / Standby failover across Cisco Switches
New-NetLbfoTeam -Name "ProductionTeam" `
                -TeamMembers "NIC1","NIC2" `
                -TeamingMode SwitchIndependent `
                -LoadBalancingAlgorithm Dynamic

# Configure Static IP Address on the Team Interface (VLAN 10)
# Example for Primary SCADA Server (SRV-SCADA-01):
New-NetIPAddress -InterfaceAlias "ProductionTeam" `
                 -IPAddress 192.168.10.10 `
                 -PrefixLength 24 `
                 -DefaultGateway 192.168.10.1

Set-DnsClientServerAddress -InterfaceAlias "ProductionTeam" `
                           -ServerAddresses ("192.168.10.30", "192.168.10.31")
```

---

## 3. Dedicated Inter-Server Heartbeat Link (Split-Brain Prevention)

To prevent "Split-Brain" (where both servers believe they are the active master during a network hiccup), a dedicated private link is established over NIC 3:

| Server Name | NIC 3 IP Address | Subnet Mask | Description |
|---|---|---|---|
| **SRV-SCADA-01 (Primary)** | `10.10.10.1` | `255.255.255.252` (`/30`) | Direct Cat6A Patch to Server 02 NIC 3 |
| **SRV-SCADA-02 (Secondary)** | `10.10.10.2` | `255.255.255.252` (`/30`) | Direct Cat6A Patch to Server 01 NIC 3 |

---

## 4. Rockwell FactoryTalk View SE Redundancy Setup

1. **FactoryTalk Directory (FTD) Redundancy**:
   - `SRV-SCADA-01` configured as **Primary Directory Server**.
   - `SRV-SCADA-02` configured as **Secondary Directory Server**.
   - Replication interval: **Real-time synchronized** with automatic certificate renewal.

2. **HMI Tag & Data Server Redundancy**:
   - **Active/Standby Pair**: In Studio 5000 / FactoryTalk Administration Console:
     - Primary Server: `SRV-SCADA-01` (`192.168.10.10`)
     - Secondary Server: `SRV-SCADA-02` (`192.168.10.11`)
     - Heartbeat Interval: **500 ms**
     - Failover Switchover Time: **< 1.5 seconds**
   - **Auto-Synchronization**: Graphic display edits, tag database changes, and security accounts automatically synchronize from Primary to Secondary.

3. **FactoryTalk Alarms and Events (FTA&E)**:
   - Alarm status, acknowledgment, and suppression states are mirrored continuously across both servers.
   - Operators on any station (Operator 1, Operator 2, or Station 2) acknowledge alarms once, updating both servers simultaneously.

---

## 5. FactoryTalk Historian SE Collective Mirroring

* Primary Historian Node: `192.168.10.20`
* Secondary Historian (Mirror Node): `192.168.10.21`
* **Dual-Buffering Architecture**: ControlLogix PLC tags are sent concurrently to local buffers on both historian servers. If one server is taken down for Windows updates or hardware maintenance, zero trend data points are lost.

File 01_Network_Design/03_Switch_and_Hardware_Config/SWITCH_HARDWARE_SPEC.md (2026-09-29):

# Industrial Switch & Hardware Configuration Spec
**Project**: Ingredion Kalasin — Sprint 18K TPA Spray Dryer Plant  
**Switch Hardware Standard**: Rockwell Automation Allen-Bradley Stratix 5700 / 5400 Managed Industrial Switches  

---

## 1. Switch Bill of Materials (BOM)

| Switch Tag | Model Number | Total Ports | Fiber SFP Ports | Location | Role / Uplink |
|---|---|---|---|---|---|
| `SW-COR-01` | **Stratix 5400 (1783-HMS16S4CGN)** | 20 Ports | 4x 1Gbps SFP Fiber | Central Server Rack | Core / Distribution Layer |
| `SW-201` | **Stratix 5700 (1783-BMS10CGN)** | 10 Ports | 2x Combo SFP Fiber | RIO-202 (Area 202) | Area 202 Aggregation & DLR |
| `SW-401` | **Stratix 5700 (1783-BMS10CGN)** | 10 Ports | 2x Combo SFP Fiber | RIO-402 (Area 402) | Area 402 Distribution |
| `SW-601` | **Stratix 5700 (1783-BMS20CGN)** | 20 Ports | 2x Combo SFP Fiber | MCP-602 (Dryer) | Dryer Process & Burner DLR |
| `SW-801` | **Stratix 5700 (1783-BMS10CGN)** | 10 Ports | 2x Combo SFP Fiber | CIP-01 (CIP Skid)  | Area 814 Distribution |

---

## 2. Standard Stratix Managed Switch Configuration Settings

* **Spanning Tree Protocol**: Rapid Spanning Tree Protocol (RSTP - IEEE 802.1w) enabled on all inter-switch trunks.
* **QoS (Quality of Service)**:
  - Trust DSCP tags from Rockwell 1756-EN2TR/EN4TR and PowerFlex drives.
  - Priority Queue 1 assigned to PTP (Precision Time Protocol / IEEE 1588) and CIP Motion.
  - Priority Queue 2 assigned to CIP Implicit I/O (UDP 2222).
* **Multicast Management**:
  - IGMP Snooping: Enabled globally.
  - IGMP Querier: Enabled on `SW-COR-01` (Core Switch).
* **Security & Port Hardening**:
  - Unused ports: Admin down (`shutdown`) and assigned to a dummy quarantine VLAN (VLAN 999).
  - Port Security: MAC address sticky or limit of 2 MAC addresses on access ports.
  - DHCP Snooping: Enabled on all access ports to block rogue DHCP servers.

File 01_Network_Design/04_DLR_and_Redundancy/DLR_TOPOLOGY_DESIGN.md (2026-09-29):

# Device Level Ring (DLR) & Redundancy Design
**Standard**: ODVA EtherNet/IP Device Level Ring (DLR) Specification / IEC 62439-3  
**Project**: Ingredion Kalasin Spray Dryer Plant  

---

## 1. DLR Overview & Fault Recovery
DLR is a Layer 2 ring protocol designed for rapid single-fault recovery (< 3ms) in industrial automation systems. In the event of a severed cable or failed node, the Ring Supervisor unblocks its secondary port within milliseconds, preventing communication timeout (`Connection Timeout`) on the ControlLogix processor.

```
       [ 1756-EN2TR / EN4TR Bridge ] <--- Active Ring Supervisor
        Port 1                  Port 2
          │                       │ (Normally Blocked Beacon Port)
          ▼                       ▼
    [1734-AENTR] ◄────────► [PowerFlex 525] ◄────────► [1734-AENTR Node 2]
     (Ring Node)             (Dual Port VFD)            (Ring Node)
```

---

## 2. Kalasin Plant DLR Ring Assignments

### Ring 1: Area 202 Pre-Slurry DLR
* **Ring Supervisor**: 1756-EN4TR in Main Control Panel (MCP-01) Slot 2 (IP: `192.168.40.10`)
* **Backup Supervisor**: 1783-ETAP (or Stratix 5700 port pair in DLR supervisor mode)
* **Ring Nodes (Daisy-chained)**:
  1. `RIO-202-AENT1` (1734-AENTR Slot 1/2)
  2. `VFD-PC-20201` (PowerFlex 525 with 25-COMM-E2P dual Ethernet)
  3. `VFD-PC-20211` (PowerFlex 525 with 25-COMM-E2P dual Ethernet)
  4. `VFD-ME-20201` (PowerFlex 525 dual Ethernet)
  5. `RIO-202-AENT2` (1734-AENTR Slot 1/2)
* **Beacon Interval**: $400\,\mu\text{s}$
* **Beacon Timeout**: $1960\,\mu\text{s}$ (less than 2ms total failover time)

### Ring 2: Area 602 Spray Dryer Burner & Process DLR
* **Ring Supervisor**: 1756-EN4TR in MCP-602 Slot 3 (IP: `192.168.60.10`)
* **Ring Nodes**:
  1. `RIO-602-AENT1` (Chamber Instrumentation)
  2. `RIO-602-AENT2` (Cyclone & Baghouse)
  3. `VFD-PUPD-11` (PowerFlex 755 with 20-750-ENETR dual port)
  4. `VFD-FN-60201` (PowerFlex 755 dual port)
  5. `VFD-FN-60202` (PowerFlex 755 dual port)

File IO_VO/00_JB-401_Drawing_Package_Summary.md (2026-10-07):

# Junction Box JB-401 Engineering Drawing & Testing Package

**Project**: Project Sprint 18K TPA Spray Dryer / Jet Cooker  
**Client**: Ingredion (Thailand) Co., Ltd.  
**Contractor**: Kalasin Engineering Co., Ltd. (Ref: x2608003)  
**Location**: Infeed 2nd Floor  
**Enclosure**: JB-401 (Standard Stainless Steel Field Junction Box, 800 x 600 x 250 mm)  
**Channel Capacity**: 112 Total Channels (85 Active, 27 Spares / 24.1% Margin)

---

## 1. Master Drawing Deliverables in `IO_VO`

| File Name | Format | Description & Engineering Content |
| :--- | :---: | :--- |
| **`JB-401_Master_Engineering_Drawings_Complete.pdf`** | **PDF (20 Pages)** | Complete compiled master engineering drawing book for JB-401 containing the System Configuration Diagram (SCD), full ControlLogix 1756 Chassis C1 I/O schematics (DI, DO, AI), and all 13 instrument typical loop hook-up diagrams for instruments landed in JB-401. |
| **`JB-401_Terminal_Wiring_Report.pdf`** | **PDF (4 Pages)** | Point-by-point field terminal wiring schedule, terminal numbers (P1-TBDI1, P1-TBDI2, P1-TBDI3, P1-TBRL1, P1-TBRL2, P1-TBAI1), cable wire numbers, PLC rack/slots, and tag assignments. |
| **`Loop_Test_Report_JB-401.xlsx`** | **Excel (43 Sheets)** | Formal Loop Test Report: Sheet `00_JB_Index` + 42 dedicated equipment testing certificates (1 sheet per equipment) with consolidated multi-signal channels (AI: 2-pin differential A/B). |
| **`Loop_Test_Report_JB-401.pdf`** | **PDF (43 Sheets)** | Printable vector PDF export of the complete JB-401 Loop Test Report workbook. |
| **`JB-401_IO_Schedule.xlsx`** | **Excel** | Master engineering I/O allocation schedule specifically for destination JB-401. |

---

## 2. Individual Schematic Drawings in `IO_VO/JB-401_Drawings/`

| Sheet No. | Drawing Number | Signal Type & Terminal Strip | Equipment & Instruments Landed in JB-401 |
| :---: | :--- | :--- | :--- |
| **03** | `KAL-JC-WIR-Sheet_03` | Main Controller Architecture | ControlLogix 1756-A13 Chassis C1 in Panel M1 (CA1 Marshalling) |
| **04** | `KAL-JC-WIR-Sheet_04` | 1756-IB32 DI (`P1-TBDI1`) | FSL-40201/02, FT-40201/02 Pulse, HV-40201..06, XV-40201A..C Feedback |
| **05** | `KAL-JC-WIR-Sheet_05` | 1756-IB32 DI (`P1-TBDI2`) | XV-40201D..H, XV-40202A..E Open & Close Feedback Limit Switches |
| **06** | `KAL-JC-WIR-Sheet_06` | 1756-IB32 DI (`P1-TBDI3`) | XV-40202F..H, XV-40203A..D Open & Close Feedback Limit Switches |
| **08** | `KAL-JC-WIR-Sheet_08` | 1756-OB32 DO (`P1-TBRL1`) | Solenoid Actuation Commands for XV-40201A..D, Relay Interposing Coils |
| **09** | `KAL-JC-WIR-Sheet_09` | 1756-OB32 DO (`P1-TBRL2`) | Solenoid Actuation Commands for XV-40201E..H, XV-40202A..H, XV-40203A..D |
| **10** | `KAL-JC-WIR-Sheet_10` | 1756-IF16 AI (`P1-TBAI1`) | 4-20mA Current Loops: FT-40201 (Flow/Density), FT-40202, LT-40201..03, pHT-40201/02 |

*Both high-resolution vector PDF and SVG versions of each sheet are stored in `IO_VO/JB-401_Drawings/`.*

---

## 3. Instrument Typical Hook-Up Diagrams in `JB-401_Master_Engineering_Drawings_Complete.pdf`

- **Page 8 (TYP-003)**: pH Analytical Measurement Loop (`pHT-40201`, `pHT-40202`)
- **Page 9 (TYP-006)**: Magnetic Flowmeter 4-Wire Active Loop (`FT-40202`)
- **Page 10 (TYP-007)**: Coriolis Mass Flowmeter 4-Wire Loop (`FT-40201`)
- **Page 11 (TYP-010)**: Differential Pressure Level / Flow (`PDT-40201`)
- **Page 12 (TYP-011)**: Guided Wave / Free Space Radar Level (`LT-40201`, `LT-40202`, `LT-40203`)
- **Page 13 (TYP-012)**: RTD Temperature Transmitter Pt100 (`TT-40201`..`03`)
- **Page 14 (TYP-014)**: Control Valve with SMART Positioner (`FCV-40201`, `TCV-40201`)
- **Page 15 (TYP-017)**: Pneumatic On-Off Solenoid Valve with Dual Proximity Limit Switches (`XV-40201A`..`H`, `XV-40202A`..`H`, `XV-40203A`..`D`)
- **Page 16 (TYP-019)**: Vibrating Fork Level Switch High/Low (`LSH-40201`, `LSL-40201`)
- **Page 17 (TYP-020)**: Pressure Switch High/Low (`PSH-40201`, `PSL-40201`)

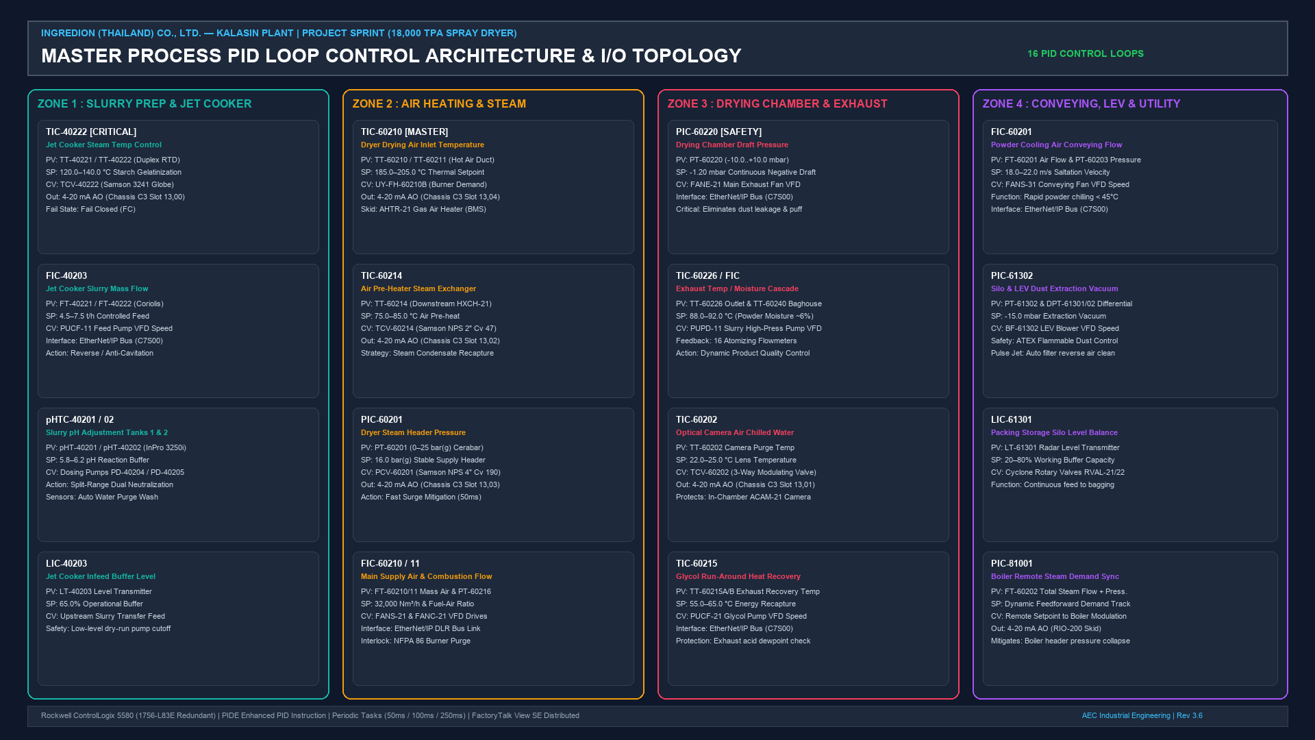
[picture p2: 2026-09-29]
02_Electrical_and_eDrawing/06_SCADA_Demo/PID_Loop_Control_Architecture_Overview.png

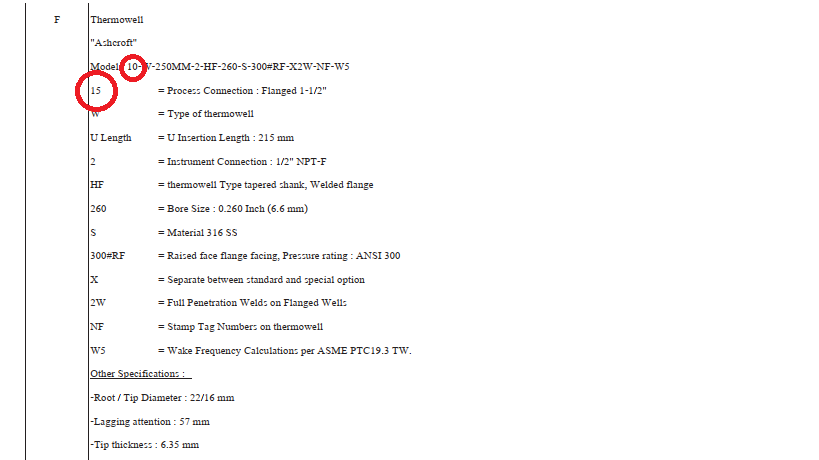
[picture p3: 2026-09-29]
02_Electrical_and_eDrawing/05_Instrument_Manuals/CS-DS-15 Temp gauge/spec thermowell comfirm.png

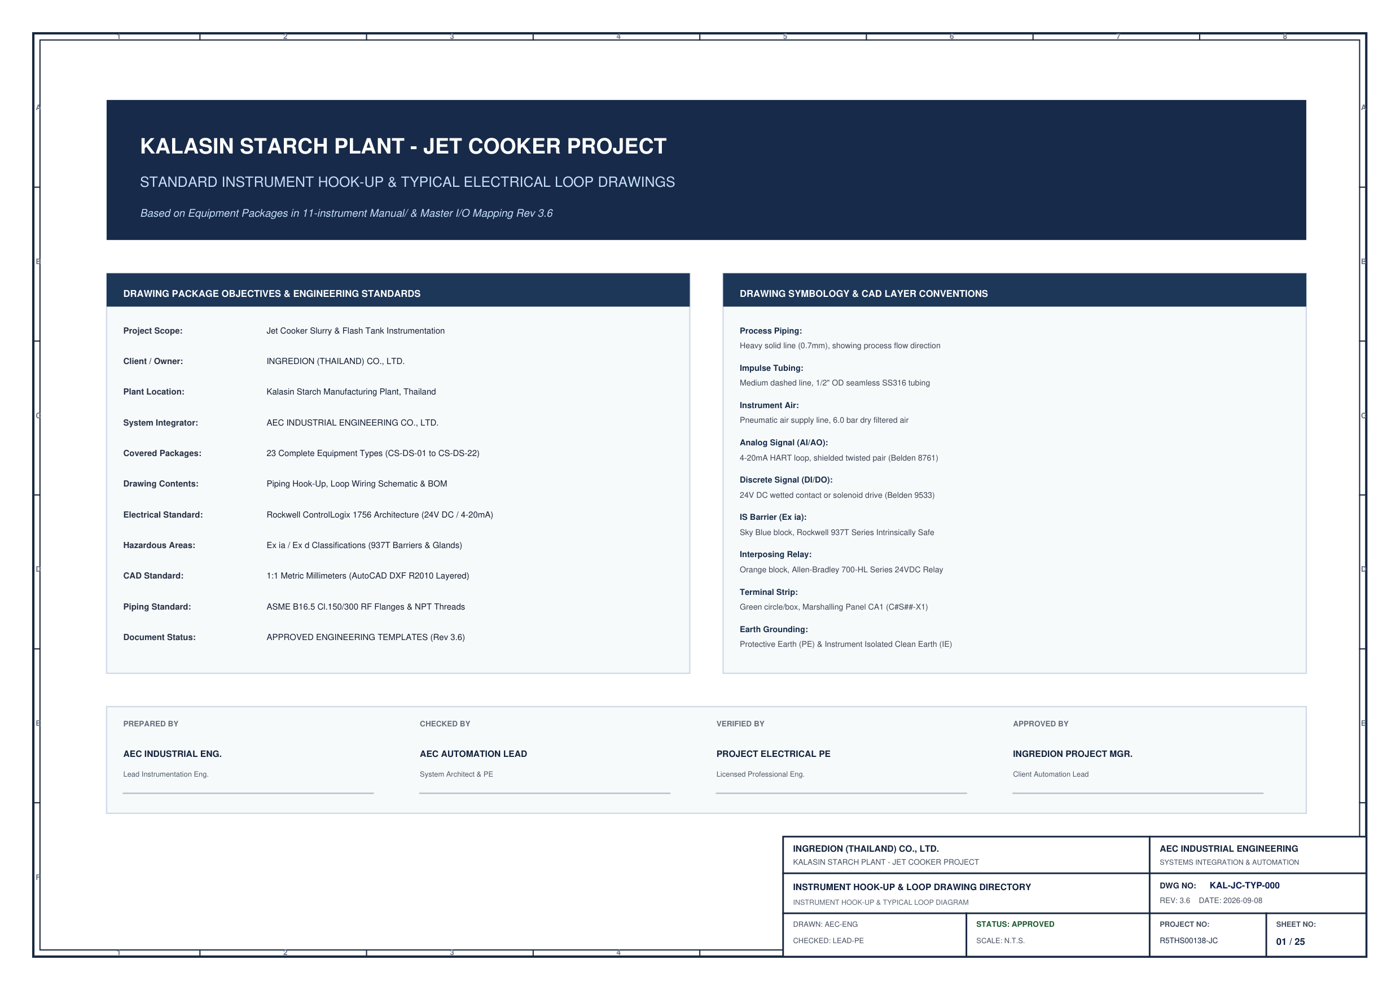
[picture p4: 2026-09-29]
02_Electrical_and_eDrawing/04_PDF_Reports_and_Drawings/instrument_template_sheet_01.png

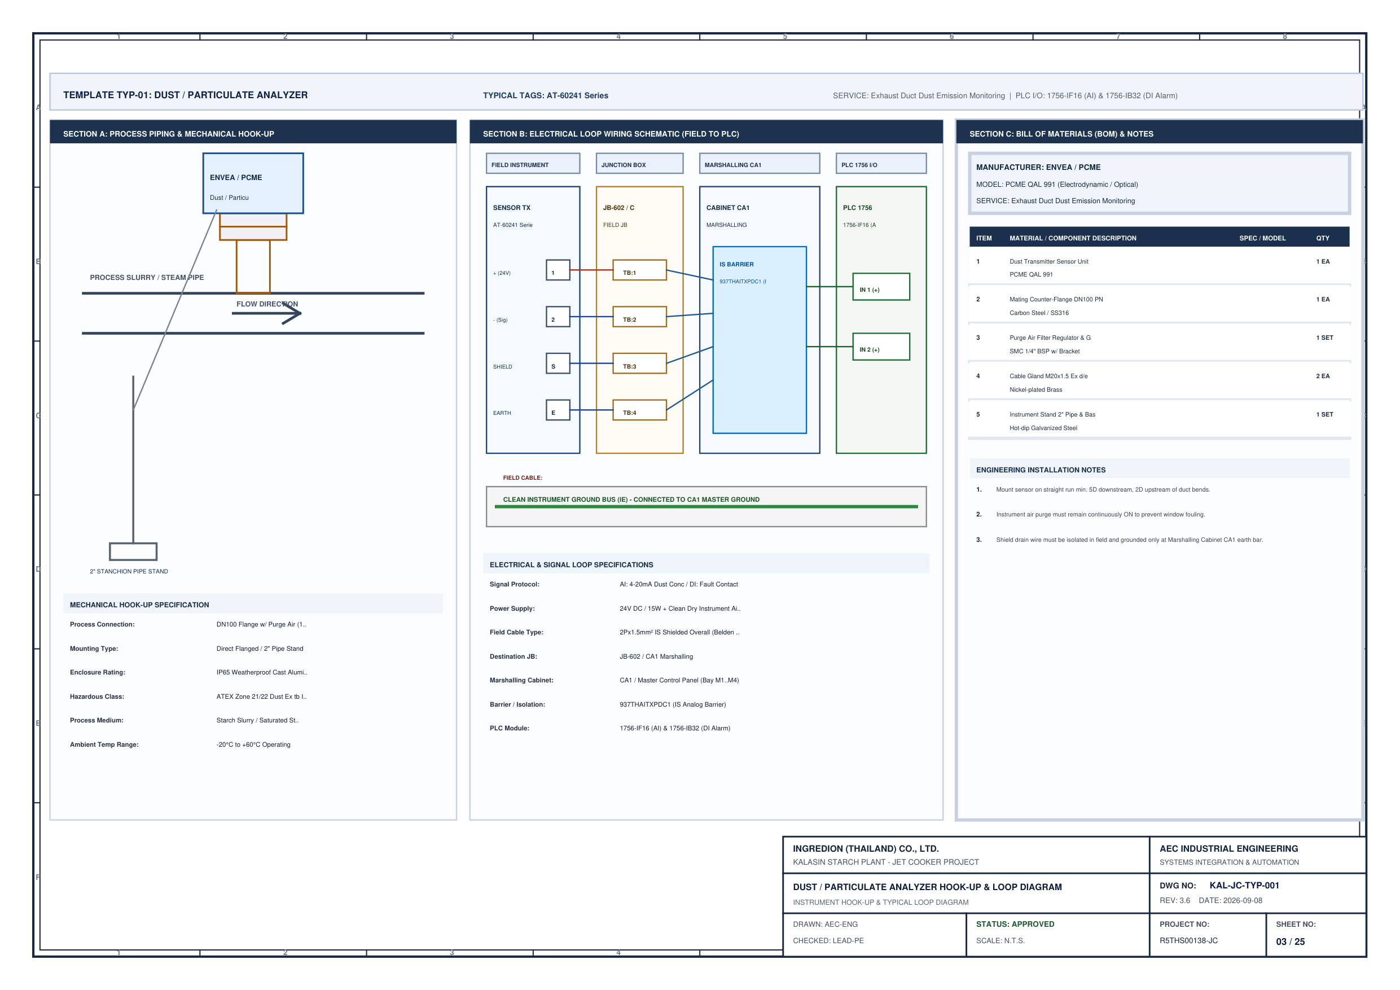
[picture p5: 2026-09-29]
02_Electrical_and_eDrawing/04_PDF_Reports_and_Drawings/instrument_template_sheet_03.png

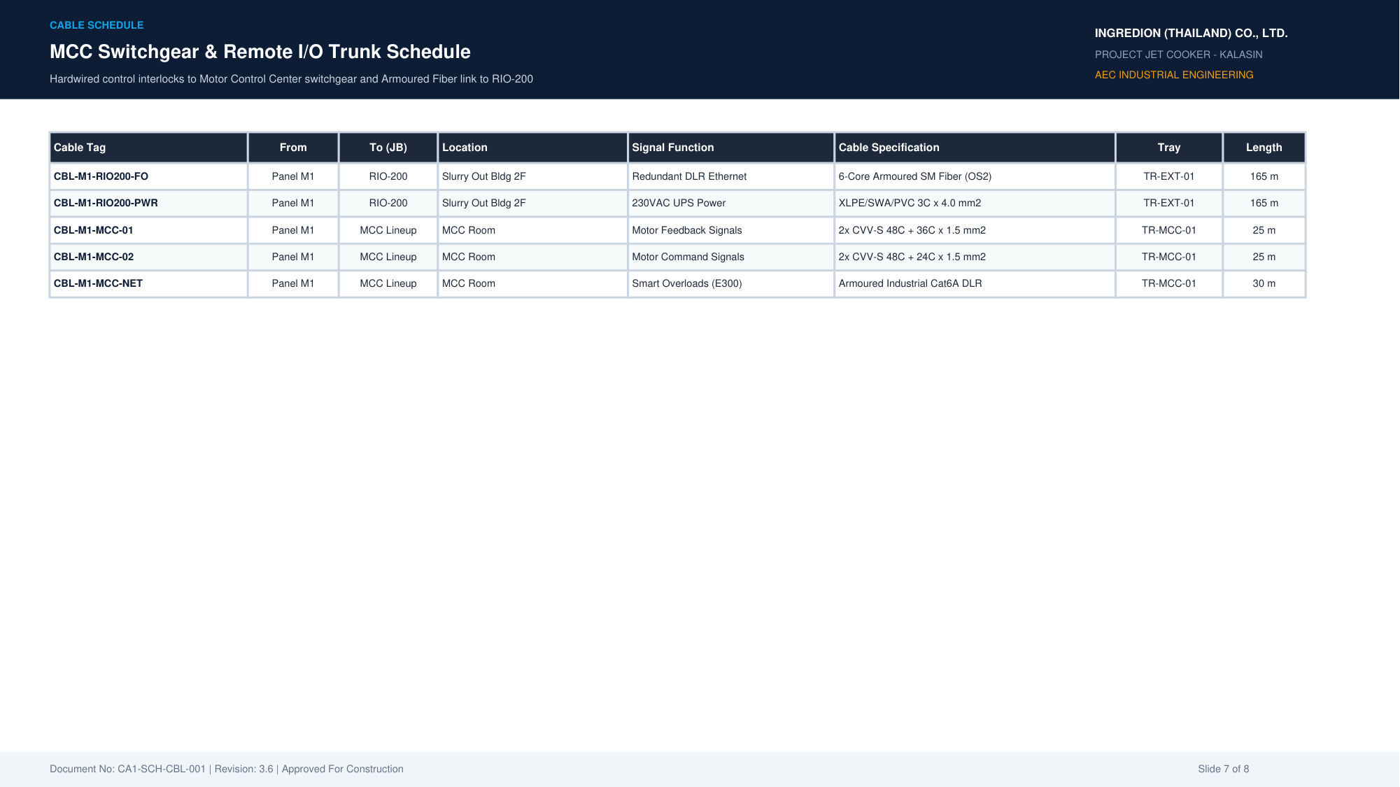
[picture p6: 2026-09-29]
02_Electrical_and_eDrawing/04_PDF_Reports_and_Drawings/cable_schedule_slide_7.png

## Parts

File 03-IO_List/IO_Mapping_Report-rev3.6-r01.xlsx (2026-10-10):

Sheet: 00_Executive_Summary
KALASIN ENGINEERING | xCIP-1545 AUTOMATION SYSTEM (Ref: x2608003)
MASTER PLC I/O MAPPING & HARDWARE ALLOCATION REPORT — SPRINT 18K TPA SPRAY DRYER / JET COOKER
TOTAL INSTRUMENTS |  | PHYSICAL PLC CHANNELS |  | ACTIVE PROCESS I/O |  | SPARE CAPACITY |  | COMMON / INTERNAL |  | NETWORK REDUNDANCY
560 |  | 1,466 |  | 746 |  | 561 |  | 159 |  | 1Gbps DLR RING
Rev 3.6a Master Client Schedule |  | 5 Chassis (C1-C5), 57 Slots |  | Assigned to Process Instruments |  | 38.3% Expansion Margin (>20% Req) |  | Power Commons, CPU & Comm Ports |  | EtherNet/IP Device Level Ring CA1-RIO
1. CONTROLLOGIX 1756 CHASSIS HARDWARE & UTILIZATION DIRECTORY
Chassis Code | Overview Sheet | Chassis & Function Description | Physical Location | Hardware Model | Mounted Slots | Total Channels | Active Channels | Spare Channels | Spare Margin % | Main Power Supply | Network Link | Cabinet / Panel
C1 | C1SlotConfig | Main Controller Rack (1756-L950TPSXT CPU) | Control Cabinet CA1 (Main Control Room MCP) | 1756-A13 (13-Slot ControlLogix Chassis) | 13 Slots (S0..S12) | 306 | 174 | 103 | 33.7% | 1756-PA75 (85-265VAC) | 1Gbps DLR Ring + SCADA Uplink | CA1 (Main Control Room MCP)
C2 | C2SlotConfig | Main Expansion Rack (High-Density Field I/O) | Control Cabinet CA1 (Main Control Room MCP) | 1756-A13 (13-Slot ControlLogix Chassis) | 13 Slots (S0..S12) | 436 | 230 | 164 | 37.6% | 1756-PA75 (85-265VAC) | Internal Backplane Bridge | CA1 (Main Control Room MCP)
C3 | C3SlotConfig | Remote I/O Rack 1 (Spray Dryer / Packing Tower) | Field RIO Cabinet (Spray Dryer / Packing Tower) | 1756-A13 (13-Slot ControlLogix Chassis) | 13 Slots (S0..S12) | 350 | 169 | 135 | 38.6% | 1756-PA75 (85-265VAC) | 1Gbps DLR Fiber Ring Ring Port 1/2 | Field RIO Cabinet (Spray Dryer)
C4 | C4SlotConfig | Remote I/O Rack 2 (Upper Spray Dryer 6th/8th Floor) | Field RIO Cabinet (Spray Dryer 6th/8th Floor) | 1756-A13 (13-Slot ControlLogix Chassis) | 13 Slots (S0..S12) | 226 | 103 | 95 | 42.0% | 1756-PA75 (85-265VAC) | 1Gbps DLR Copper Ring Port 1/2 | Field RIO Cabinet (6th/8th Fl)
C5 | C5SlotConfig | Remote I/O Station 5 (Slurry Building RIO-200) | Slurry Building 2nd Floor (RIO-200) | 1756-A7 (7-Slot ControlLogix Chassis) | 5 Slots (S0..S4) | 148 | 70 | 64 | 43.2% | 1756-PB75 (24VDC Redundant) | 1Gbps DLR Copper Ring (Slurry Bldg) | Slurry Bldg 2nd Fl (RIO-200)
TOTAL SYSTEM CAPACITY (5 CHASSIS) |  |  |  |  |  | 1466 | 746 | 561 | 38.3% | - | - | -
2. I/O SIGNAL FAMILY & MODULE SCHEDULE |  |  |  |  |  |  | 3. CLIENT INSTRUMENT SCOPE & DESTINATION SUMMARY
Signal Family | Module Hardware | Signal Type | Total Pts | Active Pts | Spare Pts |  | Scope Destination | Primary Wiring Target | Loop Count | Active Pts | Typical Cable | Interface Remark
DI (24VDC Digital Input) | 1756-IB32 (32-Pt Sink/Source) | 24VDC Dry Contact / PNP | 612 | 334 | 210 |  | Direct to Main PLC (CA1/RIO) | Chassis C1, C2, C3, C4 | 454 | 676 | LiY-CY TP 1Px1.0 / CVV | Main Process Automation
DO (24VDC Digital Output) | 1756-OB32 (32-Pt Source Transistor) | 24VDC Energized Solenoids | 324 | 122 | 184 |  | Slurry Bldg RIO-200 | Chassis C5 (Slurry 2nd Fl) | 36 | 70 | LiY-CY TP / CVV Multi-core | Slurry Preparation Area
AI (4-20mA / RTD / Volts) | 1756-IF16 (16-Pt Single-Ended / Diff) | 4-20mA HART Transmitter | 468 | 252 | 164 |  | Air Heater Panel (AHTR) | AHTR Package Control Panel | 22 | 0 | Package Vendor Cables | Dryer Air Heater Skid
AO (4-20mA Analog Output) | 1756-OF8 (8-Pt Voltage / Current) | 4-20mA Control Valves (CV) | 20 | 5 | 3 |  | Heat Control Panel (HCP) | HCP Control Panel | 11 | 0 | Package Vendor Cables | Burner / Heat Package
CPU (Main Controller) | 1756-L950TPSXT (ControlLogix 5580) | Process Controller & SD/USB | 5 | 5 | 0 |  | Fire Deluge / Suppression | Suppression / Deluge Skid | 7 | 0 | Fire Rated Cable | Safety & Fire Interlock
COMM (EtherNet/IP) | 1756-EN4TR (1Gbps 2-Port DLR) | DLR Device Level Ring | 28 | 28 | 0 |  | Local Mechanical Instruments | Local Pipe / Equipment Dial | 23 | 0 | None (Direct Reading) | Pressure Gauges & Sight Glass
EMPTY (Chassis Slot Reserve) | 1756-N2 (Slot Filler Blank Plate) | Future Hardware Expansion | 9 | 0 | 0 |  | Other Package / MCC | MCC / Heat Control HTRE | 7 | 0 | Vendor / Hardwire Interlock | VSD / Motor Feeders

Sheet: 02_PLC_Channel_IO_Mapping
KALASIN ENGINEERING | CONTROLLOGIX 1756 POINT-BY-POINT PLC I/O CHANNEL MAPPING
1,466 Physical Terminal Channels across 5 Chassis (C1S0 - C5S4) with Marshaling Blocks, Field Wire Marks & Instrument Master Data
Seq No. | Chassis | Slot Tag | Module Catalog | Signal Family | Terminal Pin | Channel / Terminal Description | Marshaling Terminal (Px-TB) | Wire Mark (PLC Side) | Wire Mark (Terminal Side) | Destination Area | PLC Tag Name | Instrument Tag | Instrument Description | Instrument Name / Type | P&ID No. | Signal Type | Calibrated Range | Manufacturer | Model Series | Suggested Field Cable | Channel Status | Engineering Remark
1 | C1 | C1S0 | 1756-L950TPSXT | CPU (Controller) | RJ45-1 | Embedded 1Gbps EtherNet/IP Port (SCADA / Enterprise Network) | ETH-CORE-01 | C1S0-ETH1/SW-CORE-01 | SW-CORE-01/C1S0-ETH1 | CA1 (Main Control Room) | CPU_Embedded_ETH | PLC-01 | Main Process Controller EtherNet/IP Uplink Port | Process Field Device | - | - | - | Industrial Process Equipment | Standard Process Field Device | CVV 2Cx1.5 / LiY-CY 1Px1.0 General Control | ACTIVE | -
2 | C1 | C1S0 | 1756-L950TPSXT | CPU (Controller) | USB-1 | USB 2.0 Type-B Programming Port (Maintenance / Diagnostics) | USB-CONSOLE | C1S0-USB/CONSOLE | CONSOLE/C1S0-USB | CA1 (Main Control Room) | CPU_USB_Console | USB-PGM | Engineering Workstation Maintenance Access Port | Process Field Device | - | - | - | Industrial Process Equipment | Standard Process Field Device | CVV 2Cx1.5 / LiY-CY 1Px1.0 General Control | ACTIVE | -
3 | C1 | C1S0 | 1756-L950TPSXT | CPU (Controller) | SD-1 | 1784-SD2 Industrial SD Memory Card Slot (Firmware & Program Backup) | SD-SLOT | C1S0-SD/INTERNAL | INTERNAL/C1S0-SD | CA1 (Main Control Room) | CPU_SD_Card | 1784-SD2 | Non-volatile System Image & User Program Storage | Process Field Device | - | - | - | Industrial Process Equipment | Standard Process Field Device | CVV 2Cx1.5 / LiY-CY 1Px1.0 General Control | ACTIVE | -
4 | C1 | C1S0 | 1756-L950TPSXT | CPU (Controller) | ESM-1 | Capacitor Energy Storage Module (Maintenance-free, Battery-free) | ESM-CAP | C1S0-ESM/INTERNAL | INTERNAL/C1S0-ESM | CA1 (Main Control Room) | CPU_ESM_Module | 1756-ESMCAP | Energy Storage Module for Power Loss Data Retention | Process Field Device | - | - | - | Industrial Process Equipment | Standard Process Field Device | CVV 2Cx1.5 / LiY-CY 1Px1.0 General Control | ACTIVE | -
5 | C1 | C1S0 | 1756-L950TPSXT | CPU (Controller) | DISP-1 | 4-Character Alphanumeric Diagnostic Display & Status LEDs (RUN, FORCE, SD, OK) | DIAG-DISP | C1S0-DISP/DIAG | DIAG/C1S0-DISP | CA1 (Main Control Room) | CPU_Status_Display | DIAG-LED | System Controller Status & Fault Diagnostic Indicators | Process Field Device | - | - | - | Industrial Process Equipment | Standard Process Field Device | CVV 2Cx1.5 / LiY-CY 1Px1.0 General Control | ACTIVE | -
6 | C1 | C1S1 | 1756-EN4TR | COMM (EtherNet/IP) | RJ45-1 | EtherNet/IP Port 1 (DLR Ring Node 1 / Primary Adapter Link) | ETH-DLR-P1 | C1S1-/- | -/C1S1- | CA1 | C1S1_ETH_Port1 | ETH-01 | 10/100/1000 Mbps RJ45 Device Level Ring Port 1 | Process Field Device | - | - | - | Industrial Process Equipment | Standard Process Field Device | CVV 2Cx1.5 / LiY-CY 1Px1.0 General Control | ACTIVE | -
7 | C1 | C1S1 | 1756-EN4TR | COMM (EtherNet/IP) | RJ45-2 | EtherNet/IP Port 2 (DLR Ring Node 2 / Redundant Loop) | ETH-DLR-P2 | C1S1-P2/ETH | ETH/C1S1-P2 | CA1 | C1S1_ETH_Port2 | ETH-02 | 10/100/1000 Mbps RJ45 Device Level Ring Port 2 | Process Field Device | - | - | - | Industrial Process Equipment | Standard Process Field Device | CVV 2Cx1.5 / LiY-CY 1Px1.0 General Control | ACTIVE | -
8 | C1 | C1S1 | 1756-EN4TR | COMM (EtherNet/IP) | USB-1 | USB 2.0 Type-B Device Port (Local Configuration & Diagnostics) | USB-CONSOLE | C1S1-USB/CONSOLE | CONSOLE/C1S1-USB | CA1 | C1S1_USB_Config | USB-CFG | Local IP Configuration and Firmware Flashing Port | Process Field Device | - | - | - | Industrial Process Equipment | Standard Process Field Device | CVV 2Cx1.5 / LiY-CY 1Px1.0 General Control | ACTIVE | -
9 | C1 | C1S1 | 1756-EN4TR | COMM (EtherNet/IP) | DISP-1 | 4-Character Diagnostic Display & Status LEDs (OK, NET A/B, LINK 1/2) | DIAG-DISP | C1S1-DISP/DIAG | DIAG/C1S1-DISP | CA1 | C1S1_Status_Display | DIAG-LED | Hardware Status & Network Link Diagnostic Indicators | Process Field Device | - | - | - | Industrial Process Equipment | Standard Process Field Device | CVV 2Cx1.5 / LiY-CY 1Px1.0 General Control | ACTIVE | -
10 | C1 | C1S2 | 1756-EN4TR | COMM (EtherNet/IP) | RJ45-1 | EtherNet/IP Port 1 (DLR Ring Node 1 / Primary Adapter Link) | ETH-DLR-P1 | C1S2-/- | -/C1S2- | CA1 | C1S2_ETH_Port1 | ETH-01 | 10/100/1000 Mbps RJ45 Device Level Ring Port 1 | Process Field Device | - | - | - | Industrial Process Equipment | Standard Process Field Device | CVV 2Cx1.5 / LiY-CY 1Px1.0 General Control | ACTIVE | -
11 | C1 | C1S2 | 1756-EN4TR | COMM (EtherNet/IP) | RJ45-2 | EtherNet/IP Port 2 (DLR Ring Node 2 / Redundant Loop) | ETH-DLR-P2 | C1S2-P2/ETH | ETH/C1S2-P2 | CA1 | C1S2_ETH_Port2 | ETH-02 | 10/100/1000 Mbps RJ45 Device Level Ring Port 2 | Process Field Device | - | - | - | Industrial Process Equipment | Standard Process Field Device | CVV 2Cx1.5 / LiY-CY 1Px1.0 General Control | ACTIVE | -
12 | C1 | C1S2 | 1756-EN4TR | COMM (EtherNet/IP) | USB-1 | USB 2.0 Type-B Device Port (Local Configuration & Diagnostics) | USB-CONSOLE | C1S2-USB/CONSOLE | CONSOLE/C1S2-USB | CA1 | C1S2_USB_Config | USB-CFG | Local IP Configuration and Firmware Flashing Port | Process Field Device | - | - | - | Industrial Process Equipment | Standard Process Field Device | CVV 2Cx1.5 / LiY-CY 1Px1.0 General Control | ACTIVE | -
13 | C1 | C1S2 | 1756-EN4TR | COMM (EtherNet/IP) | DISP-1 | 4-Character Diagnostic Display & Status LEDs (OK, NET A/B, LINK 1/2) | DIAG-DISP | C1S2-DISP/DIAG | DIAG/C1S2-DISP | CA1 | C1S2_Status_Display | DIAG-LED | Hardware Status & Network Link Diagnostic Indicators | Process Field Device | - | - | - | Industrial Process Equipment | Standard Process Field Device | CVV 2Cx1.5 / LiY-CY 1Px1.0 General Control | ACTIVE | -
14 | C1 | C1S3 | 1756-EN4TR | COMM (EtherNet/IP) | RJ45-1 | EtherNet/IP Port 1 (DLR Ring Node 1 / Primary Adapter Link) | ETH-DLR-P1 | C1S3-/- | -/C1S3- | CA1 | C1S3_ETH_Port1 | ETH-01 | 10/100/1000 Mbps RJ45 Device Level Ring Port 1 | Process Field Device | - | - | - | Industrial Process Equipment | Standard Process Field Device | CVV 2Cx1.5 / LiY-CY 1Px1.0 General Control | ACTIVE | -
15 | C1 | C1S3 | 1756-EN4TR | COMM (EtherNet/IP) | RJ45-2 | EtherNet/IP Port 2 (DLR Ring Node 2 / Redundant Loop) | ETH-DLR-P2 | C1S3-P2/ETH | ETH/C1S3-P2 | CA1 | C1S3_ETH_Port2 | ETH-02 | 10/100/1000 Mbps RJ45 Device Level Ring Port 2 | Process Field Device | - | - | - | Industrial Process Equipment | Standard Process Field Device | CVV 2Cx1.5 / LiY-CY 1Px1.0 General Control | ACTIVE | -
16 | C1 | C1S3 | 1756-EN4TR | COMM (EtherNet/IP) | USB-1 | USB 2.0 Type-B Device Port (Local Configuration & Diagnostics) | USB-CONSOLE | C1S3-USB/CONSOLE | CONSOLE/C1S3-USB | CA1 | C1S3_USB_Config | USB-CFG | Local IP Configuration and Firmware Flashing Port | Process Field Device | - | - | - | Industrial Process Equipment | Standard Process Field Device | CVV 2Cx1.5 / LiY-CY 1Px1.0 General Control | ACTIVE | -
17 | C1 | C1S3 | 1756-EN4TR | COMM (EtherNet/IP) | DISP-1 | 4-Character Diagnostic Display & Status LEDs (OK, NET A/B, LINK 1/2) | DIAG-DISP | C1S3-DISP/DIAG | DIAG/C1S3-DISP | CA1 | C1S3_Status_Display | DIAG-LED | Hardware Status & Network Link Diagnostic Indicators | Process Field Device | - | - | - | Industrial Process Equipment | Standard Process Field Device | CVV 2Cx1.5 / LiY-CY 1Px1.0 General Control | ACTIVE | -
18 | C1 | C1S4 | 1756-IB32 | DI (24VDC Digital Input) | 1 | IN-0 | P1-TBDI1-1 | C1S4-1/P1-TBDI1-1 | P1-TBDI1-1/C1S4-1 | CA1 | Spare_DI_0 | Spare | Spare Reserve Channel | - | - | 24VDC Discrete | - | - | - | Reserved for Future Loop | SPARE | Spare Reserve Channel
19 | C1 | C1S4 | 1756-IB32 | DI (24VDC Digital Input) | 2 | IN-1 | P1-TBDI1-2 | C1S4-2/P1-TBDI1-2 | P1-TBDI1-2/C1S4-2 | CA1 | Spare_DI_0 | Spare | Spare Reserve Channel | - | - | 24VDC Discrete | - | - | - | Reserved for Future Loop | SPARE | Spare Reserve Channel
20 | C1 | C1S4 | 1756-IB32 | DI (24VDC Digital Input) | 3 | IN-2 | P1-TBDI1-3 | C1S4-3/P1-TBDI1-3 | P1-TBDI1-3/C1S4-3 | CA1 | Spare_DI_0 | Spare | Spare Reserve Channel | - | - | 24VDC Discrete | - | - | - | Reserved for Future Loop | SPARE | Spare Reserve Channel
21 | C1 | C1S4 | 1756-IB32 | DI (24VDC Digital Input) | 4 | IN-3 | P1-TBDI1-4 | C1S4-4/P1-TBDI1-4 | P1-TBDI1-4/C1S4-4 | CA1 | Spare_DI_0 | Spare | Spare Reserve Channel | - | - | 24VDC Discrete | - | - | - | Reserved for Future Loop | SPARE | Spare Reserve Channel
22 | C1 | C1S4 | 1756-IB32 | DI (24VDC Digital Input) | 5 | IN-4 | P1-TBDI1-5 | C1S4-5/P1-TBDI1-5 | P1-TBDI1-5/C1S4-5 | CA1 | Spare_DI_0 | Spare | Spare Reserve Channel | - | - | 24VDC Discrete | - | - | - | Reserved for Future Loop | SPARE | Spare Reserve Channel
23 | C1 | C1S4 | 1756-IB32 | DI (24VDC Digital Input) | 6 | IN-5 | P1-TBDI1-6 | C1S4-6/P1-TBDI1-6 | P1-TBDI1-6/C1S4-6 | CA1 | Spare_DI_0 | Spare | Spare Reserve Channel | - | - | 24VDC Discrete | - | - | - | Reserved for Future Loop | SPARE | Spare Reserve Channel
24 | C1 | C1S4 | 1756-IB32 | DI (24VDC Digital Input) | 7 | IN-6 | P1-TBDI1-7 | C1S4-7/P1-TBDI1-7 | P1-TBDI1-7/C1S4-7 | CA1 | Spare_DI_0 | Spare | Spare Reserve Channel | - | - | 24VDC Discrete | - | - | - | Reserved for Future Loop | SPARE | Spare Reserve Channel
25 | C1 | C1S4 | 1756-IB32 | DI (24VDC Digital Input) | 8 | IN-7 | P1-TBDI1-8 | C1S4-8/P1-TBDI1-8 | P1-TBDI1-8/C1S4-8 | CA1 | Spare_DI_0 | Spare | Spare Reserve Channel | - | - | 24VDC Discrete | - | - | - | Reserved for Future Loop | SPARE | Spare Reserve Channel
26 | C1 | C1S4 | 1756-IB32 | DI (24VDC Digital Input) | 9 | IN-8 | P1-TBDI1-9 | C1S4-9/P1-TBDI1-9 | P1-TBDI1-9/C1S4-9 | CA1 | Spare_DI_0 | Spare | Spare Reserve Channel | - | - | 24VDC Discrete | - | - | - | Reserved for Future Loop | SPARE | Spare Reserve Channel
27 | C1 | C1S4 | 1756-IB32 | DI (24VDC Digital Input) | 10 | IN-9 | P1-TBDI1-10 | C1S4-10/P1-TBDI1-10 | P1-TBDI1-10/C1S4-10 | CA1 | Spare_DI_0 | Spare | Spare Reserve Channel | - | - | 24VDC Discrete | - | - | - | Reserved for Future Loop | SPARE | Spare Reserve Channel
28 | C1 | C1S4 | 1756-IB32 | DI (24VDC Digital Input) | 11 | IN-10 | P1-TBDI1-11 | C1S4-11/P1-TBDI1-11 | P1-TBDI1-11/C1S4-11 | CA1 | Spare_DI_0 | Spare | Spare Reserve Channel | - | - | 24VDC Discrete | - | - | - | Reserved for Future Loop | SPARE | Spare Reserve Channel
29 | C1 | C1S4 | 1756-IB32 | DI (24VDC Digital Input) | 12 | IN-11 | P1-TBDI1-12 | C1S4-12/P1-TBDI1-12 | P1-TBDI1-12/C1S4-12 | CA1 | Spare_DI_0 | Spare | Spare Reserve Channel | - | - | 24VDC Discrete | - | - | - | Reserved for Future Loop | SPARE | Spare Reserve Channel
30 | C1 | C1S4 | 1756-IB32 | DI (24VDC Digital Input) | 13 | IN-12 | P1-TBDI1-13 | C1S4-13/P1-TBDI1-13 | P1-TBDI1-13/C1S4-13 | CA1 | Spare_DI_0 | Spare | Spare Reserve Channel | - | - | 24VDC Discrete | - | - | - | Reserved for Future Loop | SPARE | Spare Reserve Channel
31 | C1 | C1S4 | 1756-IB32 | DI (24VDC Digital Input) | 14 | IN-13 | P1-TBDI1-14 | C1S4-14/P1-TBDI1-14 | P1-TBDI1-14/C1S4-14 | CA1 | Spare_DI_0 | Spare | Spare Reserve Channel | - | - | 24VDC Discrete | - | - | - | Reserved for Future Loop | SPARE | Spare Reserve Channel
32 | C1 | C1S4 | 1756-IB32 | DI (24VDC Digital Input) | 15 | IN-14 | P1-TBDI1-15 | C1S4-15/P1-TBDI1-15 | P1-TBDI1-15/C1S4-15 | CA1 | Spare_DI_0 | Spare | Spare Reserve Channel | - | - | 24VDC Discrete | - | - | - | Reserved for Future Loop | SPARE | Spare Reserve Channel
33 | C1 | C1S4 | 1756-IB32 | DI (24VDC Digital Input) | 16 | IN-15 | P1-TBDI1-16 | C1S4-16/P1-TBDI1-16 | P1-TBDI1-16/C1S4-16 | CA1 | Spare_DI_0 | Spare | Spare Reserve Channel | - | - | 24VDC Discrete | - | - | - | Reserved for Future Loop | SPARE | Spare Reserve Channel
34 | C1 | C1S4 | 1756-IB32 | DI (24VDC Digital Input) | 17 | GND-0 | 0VDC | 0VDC | 0VDC | CA1 | Internal Power Common | - | Module Power / Common Return Terminal | - | - | 24VDC Discrete | - | - | - | - | COMMON | -
35 | C1 | C1S4 | 1756-IB32 | DI (24VDC Digital Input) | 18 | GND-0 | 0VDC | 0VDC | 0VDC | CA1 | Internal Power Common | - | Module Power / Common Return Terminal | - | - | 24VDC Discrete | - | - | - | - | COMMON | -
36 | C1 | C1S4 | 1756-IB32 | DI (24VDC Digital Input) | 19 | IN-16 | P1-TBDI1-17 | C1S4-19/P1-TBDI1-17 | P1-TBDI1-17/C1S4-19 | JB-401 | FSL-40201_DI_1 | FSL-40201 | Slurry low flow | Flow Switch | 325-01-402-PD-01 | Dry Contact |  | Industrial Process Equipment | Standard Process Field Device | CVV 2Cx1.5 / LiY-CY 1Px1.0 General Control | ACTIVE | Jet Cooker
37 | C1 | C1S4 | 1756-IB32 | DI (24VDC Digital Input) | 20 | IN-17 | P1-TBDI1-18 | C1S4-20/P1-TBDI1-18 | P1-TBDI1-18/C1S4-20 | JB-401 | FSL-40202_DI_1 | FSL-40202 | Slurry low flow | Flow Switch | 325-01-402-PD-01 | Dry Contact |  | Industrial Process Equipment | Standard Process Field Device | CVV 2Cx1.5 / LiY-CY 1Px1.0 General Control | ACTIVE | Jet Cooker
38 | C1 | C1S4 | 1756-IB32 | DI (24VDC Digital Input) | 21 | IN-18 | P1-TBDI1-19 | C1S4-21/P1-TBDI1-19 | P1-TBDI1-19/C1S4-21 | JB-401 | FT-40201_DI_1 | FT-40201 | Slurry flowrate & density check transfer line | Coriolis Flow Transmitter | 325-01-402-PD-02 | 4 - 20 mA,Pulse | 0-15 m³/hr | Endress+Hauser | Promass F 300 / 83F (Coriolis Mass Flow) | LiY-CY TP 1Px1.0 (Shielded Pair) | ACTIVE | -
39 | C1 | C1S4 | 1756-IB32 | DI (24VDC Digital Input) | 22 | IN-19 | P1-TBDI1-20 | C1S4-22/P1-TBDI1-20 | P1-TBDI1-20/C1S4-22 | JB-401 | FT-40202_DI_1 | FT-40202 | Feed Slurry Flow Transmitter for Pipe (PIPE) | Magnetic Flow Transmitter | 325-01-402-PD-02 | 4 - 20 mA,Pulse | 0 to 8,000 m³/hr | Endress+Hauser | Promass F 300 / 83F (Coriolis Mass Flow) | LiY-CY TP 1Px1.0 (Shielded Pair) | ACTIVE | -
40 | C1 | C1S4 | 1756-IB32 | DI (24VDC Digital Input) | 23 | IN-20 | P1-TBDI1-21 | C1S4-23/P1-TBDI1-21 | P1-TBDI1-21/C1S4-23 | JB-401 | HV-40201_DI_1 | HV-40201 | Slurry Drain line | Valve With Position Switch | 325-01-402-PD-01 | Dry Contact | On-Off | TeroFox / APL-HKC | TF-20DFS Manual Ball Valve + APL-210N Box | CVV 4Cx1.0 (Open/Close Limit Switches) | ACTIVE | -
41 | C1 | C1S4 | 1756-IB32 | DI (24VDC Digital Input) | 24 | IN-21 | P1-TBDI1-22 | C1S4-24/P1-TBDI1-22 | P1-TBDI1-22/C1S4-24 | JB-401 | HV-40202_DI_1 | HV-40202 | Slurry Drain line | Valve With Position Switch | 325-01-402-PD-01 | Dry Contact | On-Off | TeroFox / APL-HKC | TF-20DFS Manual Ball Valve + APL-210N Box | CVV 4Cx1.0 (Open/Close Limit Switches) | ACTIVE | -
42 | C1 | C1S4 | 1756-IB32 | DI (24VDC Digital Input) | 25 | IN-22 | P1-TBDI1-23 | C1S4-25/P1-TBDI1-23 | P1-TBDI1-23/C1S4-25 | JB-401 | HV-40203_DI_1 | HV-40203 | Slurry Drain tank TS-40201 | Valve With Position Switch | 325-01-402-PD-01 | Dry Contact | On-Off | TeroFox / APL-HKC | TF-20DFS Manual Ball Valve + APL-210N Box | CVV 4Cx1.0 (Open/Close Limit Switches) | ACTIVE | -
43 | C1 | C1S4 | 1756-IB32 | DI (24VDC Digital Input) | 26 | IN-23 | P1-TBDI1-24 | C1S4-26/P1-TBDI1-24 | P1-TBDI1-24/C1S4-26 | JB-401 | HV-40204_DI_1 | HV-40204 | Slurry Drain tank TS-40202 | Valve With Position Switch | 325-01-402-PD-01 | Dry Contact | On-Off | TeroFox / APL-HKC | TF-20DFS Manual Ball Valve + APL-210N Box | CVV 4Cx1.0 (Open/Close Limit Switches) | ACTIVE | -
44 | C1 | C1S4 | 1756-IB32 | DI (24VDC Digital Input) | 27 | IN-24 | P1-TBDI1-25 | C1S4-27/P1-TBDI1-25 | P1-TBDI1-25/C1S4-27 | JB-401 | HV-40205_DI_1 | HV-40205 | Slurry Drain line | Valve With Position Switch | 325-01-402-PD-01 | Dry Contact | On-Off | TeroFox / APL-HKC | TF-20DFS Manual Ball Valve + APL-210N Box | CVV 4Cx1.0 (Open/Close Limit Switches) | ACTIVE | -
45 | C1 | C1S4 | 1756-IB32 | DI (24VDC Digital Input) | 28 | IN-25 | P1-TBDI1-26 | C1S4-28/P1-TBDI1-26 | P1-TBDI1-26/C1S4-28 | JB-401 | HV-40206_DI_1 | HV-40206 | Slurry Drain tank TS-40203 | Valve With Position Switch | 325-01-402-PD-01 | Dry Contact | On-Off | TeroFox / APL-HKC | TF-20DFS Manual Ball Valve + APL-210N Box | CVV 4Cx1.0 (Open/Close Limit Switches) | ACTIVE | -
46 | C1 | C1S4 | 1756-IB32 | DI (24VDC Digital Input) | 29 | IN-26 | P1-TBDI1-27 | C1S4-29/P1-TBDI1-27 | P1-TBDI1-27/C1S4-29 | JB-401 | XV-40201A_DI_1 | XV-40201A | Slurry feed-in pH Adjustment tank 1 | Automatic on/off valve | 325-01-402-PD-01 | 24 VDC energized | On-Off | TeroFox / El-O-Matic | TF-20DFS Ball Valve + F-Actuator + ESV | CVV 3Cx1.5 (Solenoid) + CVV 4Cx1.0 (Limit Switches) | ACTIVE | -
47 | C1 | C1S4 | 1756-IB32 | DI (24VDC Digital Input) | 30 | IN-27 | P1-TBDI1-28 | C1S4-30/P1-TBDI1-28 | P1-TBDI1-28/C1S4-30 | JB-401 | XV-40201A_DI_2 | XV-40201A | Slurry feed-in pH Adjustment tank 1 | Automatic on/off valve | 325-01-402-PD-01 | 24 VDC energized | On-Off | TeroFox / El-O-Matic | TF-20DFS Ball Valve + F-Actuator + ESV | CVV 3Cx1.5 (Solenoid) + CVV 4Cx1.0 (Limit Switches) | ACTIVE | -
48 | C1 | C1S4 | 1756-IB32 | DI (24VDC Digital Input) | 31 | IN-28 | P1-TBDI1-29 | C1S4-31/P1-TBDI1-29 | P1-TBDI1-29/C1S4-31 | JB-401 | XV-40201B_DI_1 | XV-40203B | Slurry feed-out Spray dryer infeed tank | Automatic on/off valve | 325-01-402-PD-02 | 24 VDC energized | On-Off | TeroFox / El-O-Matic | TF-20DFS Ball Valve + F-Actuator + ESV | CVV 3Cx1.5 (Solenoid) + CVV 4Cx1.0 (Limit Switches) | ACTIVE | -
49 | C1 | C1S4 | 1756-IB32 | DI (24VDC Digital Input) | 32 | IN-29 | P1-TBDI1-30 | C1S4-32/P1-TBDI1-30 | P1-TBDI1-30/C1S4-32 | JB-401 | XV-40201B_DI_2 | XV-40203B | Slurry feed-out Spray dryer infeed tank | Automatic on/off valve | 325-01-402-PD-02 | 24 VDC energized | On-Off | TeroFox / El-O-Matic | TF-20DFS Ball Valve + F-Actuator + ESV | CVV 3Cx1.5 (Solenoid) + CVV 4Cx1.0 (Limit Switches) | ACTIVE | -
50 | C1 | C1S4 | 1756-IB32 | DI (24VDC Digital Input) | 33 | IN-30 | P1-TBDI1-31 | C1S4-33/P1-TBDI1-31 | P1-TBDI1-31/C1S4-33 | JB-401 | XV-40201C_DI_1 | XV-40203C | Water washing line outlet Spray dryer infeed tank | Automatic on/off valve | 325-01-402-PD-02 | 24 VDC energized | On-Off | TeroFox / El-O-Matic | TF-20DFS Ball Valve + F-Actuator + ESV | CVV 3Cx1.5 (Solenoid) + CVV 4Cx1.0 (Limit Switches) | ACTIVE | -
51 | C1 | C1S4 | 1756-IB32 | DI (24VDC Digital Input) | 34 | IN-31 | P1-TBDI1-32 | C1S4-34/P1-TBDI1-32 | P1-TBDI1-32/C1S4-34 | JB-401 | XV-40201C_DI_2 | XV-40203C | Water washing line outlet Spray dryer infeed tank | Automatic on/off valve | 325-01-402-PD-02 | 24 VDC energized | On-Off | TeroFox / El-O-Matic | TF-20DFS Ball Valve + F-Actuator + ESV | CVV 3Cx1.5 (Solenoid) + CVV 4Cx1.0 (Limit Switches) | ACTIVE | -
52 | C1 | C1S4 | 1756-IB32 | DI (24VDC Digital Input) | 35 | GND1 | 0VDC | 0VDC | 0VDC | CA1 | Internal Power Common | - | Module Power / Common Return Terminal | - | - | 24VDC Discrete | - | - | - | - | COMMON | -
53 | C1 | C1S4 | 1756-IB32 | DI (24VDC Digital Input) | 36 | GND1 | 0VDC | 0VDC | 0VDC | CA1 | Internal Power Common | - | Module Power / Common Return Terminal | - | - | 24VDC Discrete | - | - | - | - | COMMON | -
54 | C1 | C1S5 | 1756-IB32 | DI (24VDC Digital Input) | 1 | IN-0 | P1-TBDI2-1 | C1S5-1/P1-TBDI2-1 | P1-TBDI2-1/C1S5-1 | JB-401 | XV-40201D_DI_1 | XV-40203D | CIP water washing Spray dryer infeed tank | Automatic on/off valve | 325-01-402-PD-02 | 24 VDC energized | On-Off | TeroFox / El-O-Matic | TF-20DFS Ball Valve + F-Actuator + ESV | CVV 3Cx1.5 (Solenoid) + CVV 4Cx1.0 (Limit Switches) | ACTIVE | -
55 | C1 | C1S5 | 1756-IB32 | DI (24VDC Digital Input) | 2 | IN-1 | P1-TBDI2-2 | C1S5-2/P1-TBDI2-2 | P1-TBDI2-2/C1S5-2 | JB-401 | XV-40201D_DI_2 | XV-40203D | CIP water washing Spray dryer infeed tank | Automatic on/off valve | 325-01-402-PD-02 | 24 VDC energized | On-Off | TeroFox / El-O-Matic | TF-20DFS Ball Valve + F-Actuator + ESV | CVV 3Cx1.5 (Solenoid) + CVV 4Cx1.0 (Limit Switches) | ACTIVE | -
56 | C1 | C1S5 | 1756-IB32 | DI (24VDC Digital Input) | 3 | IN-2 | P1-TBDI2-3 | C1S5-3/P1-TBDI2-3 | P1-TBDI2-3/C1S5-3 | JB-401 | XV-40201E_DI_1 | XV-40203E | CIP hight pressure water washing Spray dryer infeed tank | Automatic on/off valve | 325-01-402-PD-02 | 24 VDC energized | On-Off | TeroFox / El-O-Matic | TF-20DFS Ball Valve + F-Actuator + ESV | CVV 3Cx1.5 (Solenoid) + CVV 4Cx1.0 (Limit Switches) | ACTIVE | -
57 | C1 | C1S5 | 1756-IB32 | DI (24VDC Digital Input) | 4 | IN-3 | P1-TBDI2-4 | C1S5-4/P1-TBDI2-4 | P1-TBDI2-4/C1S5-4 | JB-401 | XV-40201E_DI_2 | XV-40203E | CIP hight pressure water washing Spray dryer infeed tank | Automatic on/off valve | 325-01-402-PD-02 | 24 VDC energized | On-Off | TeroFox / El-O-Matic | TF-20DFS Ball Valve + F-Actuator + ESV | CVV 3Cx1.5 (Solenoid) + CVV 4Cx1.0 (Limit Switches) | ACTIVE | -
58 | C1 | C1S5 | 1756-IB32 | DI (24VDC Digital Input) | 5 | IN-4 | P1-TBDI2-5 | C1S5-5/P1-TBDI2-5 | P1-TBDI2-5/C1S5-5 | JB-401 | XV-40201F_DI_1 | XV-40201F | Slurry feed-to spray dry tank | Automatic on/off valve | 325-01-402-PD-01 | 24 VDC energized | On-Off | TeroFox / El-O-Matic | TF-20DFS Ball Valve + F-Actuator + ESV | CVV 3Cx1.5 (Solenoid) + CVV 4Cx1.0 (Limit Switches) | ACTIVE | -
59 | C1 | C1S5 | 1756-IB32 | DI (24VDC Digital Input) | 6 | IN-5 | P1-TBDI2-6 | C1S5-6/P1-TBDI2-6 | P1-TBDI2-6/C1S5-6 | JB-401 | XV-40201F_DI_2 | XV-40201F | Slurry feed-to spray dry tank | Automatic on/off valve | 325-01-402-PD-01 | 24 VDC energized | On-Off | TeroFox / El-O-Matic | TF-20DFS Ball Valve + F-Actuator + ESV | CVV 3Cx1.5 (Solenoid) + CVV 4Cx1.0 (Limit Switches) | ACTIVE | -
60 | C1 | C1S5 | 1756-IB32 | DI (24VDC Digital Input) | 7 | IN-6 | P1-TBDI2-7 | C1S5-7/P1-TBDI2-7 | P1-TBDI2-7/C1S5-7 | JB-401 | XV-40201G_DI_1 | XV-40201G | CIP water washing pH Adjustment tank 1 | Automatic on/off valve | 325-01-402-PD-01 | 24 VDC energized | On-Off | TeroFox / El-O-Matic | TF-20DFS Ball Valve + F-Actuator + ESV | CVV 3Cx1.5 (Solenoid) + CVV 4Cx1.0 (Limit Switches) | ACTIVE | -
61 | C1 | C1S5 | 1756-IB32 | DI (24VDC Digital Input) | 8 | IN-7 | P1-TBDI2-8 | C1S5-8/P1-TBDI2-8 | P1-TBDI2-8/C1S5-8 | JB-401 | XV-40201G_DI_2 | XV-40201G | CIP water washing pH Adjustment tank 1 | Automatic on/off valve | 325-01-402-PD-01 | 24 VDC energized | On-Off | TeroFox / El-O-Matic | TF-20DFS Ball Valve + F-Actuator + ESV | CVV 3Cx1.5 (Solenoid) + CVV 4Cx1.0 (Limit Switches) | ACTIVE | -
62 | C1 | C1S5 | 1756-IB32 | DI (24VDC Digital Input) | 9 | IN-8 | P1-TBDI2-9 | C1S5-9/P1-TBDI2-9 | P1-TBDI2-9/C1S5-9 | JB-401 | XV-40201H_DI_1 | XV-40201H | CIP Hight pressure water washing pH Adjustment tank 1 | Automatic on/off valve | 325-01-402-PD-01 | 24 VDC energized | On-Off | TeroFox / El-O-Matic | TF-20DFS Ball Valve + F-Actuator + ESV | CVV 3Cx1.5 (Solenoid) + CVV 4Cx1.0 (Limit Switches) | ACTIVE | -
63 | C1 | C1S5 | 1756-IB32 | DI (24VDC Digital Input) | 10 | IN-9 | P1-TBDI2-10 | C1S5-10/P1-TBDI2-10 | P1-TBDI2-10/C1S5-10 | JB-401 | XV-40201H_DI_2 | XV-40201H | CIP Hight pressure water washing pH Adjustment tank 1 | Automatic on/off valve | 325-01-402-PD-01 | 24 VDC energized | On-Off | TeroFox / El-O-Matic | TF-20DFS Ball Valve + F-Actuator + ESV | CVV 3Cx1.5 (Solenoid) + CVV 4Cx1.0 (Limit Switches) | ACTIVE | -
64 | C1 | C1S5 | 1756-IB32 | DI (24VDC Digital Input) | 11 | IN-10 | P1-TBDI2-11 | C1S5-11/P1-TBDI2-11 | P1-TBDI2-11/C1S5-11 | JB-401 | XV-40202A_DI_2 | XV-40202A | Slurry feed-in pH Adjustment tank 2 | Automatic on/off valve | 325-01-402-PD-01 | 24 VDC energized | On-Off | TeroFox / El-O-Matic | TF-20DFS Ball Valve + F-Actuator + ESV | CVV 3Cx1.5 (Solenoid) + CVV 4Cx1.0 (Limit Switches) | ACTIVE | -
65 | C1 | C1S5 | 1756-IB32 | DI (24VDC Digital Input) | 12 | IN-11 | P1-TBDI2-12 | C1S5-12/P1-TBDI2-12 | P1-TBDI2-12/C1S5-12 | JB-401 | XV-40202B_DI_1 | XV-40202B | Slurry feed-out pH Adjustment tank 2 | Automatic on/off valve | 325-01-402-PD-01 | 24 VDC energized | On-Off | TeroFox / El-O-Matic | TF-20DFS Ball Valve + F-Actuator + ESV | CVV 3Cx1.5 (Solenoid) + CVV 4Cx1.0 (Limit Switches) | ACTIVE | -
66 | C1 | C1S5 | 1756-IB32 | DI (24VDC Digital Input) | 13 | IN-12 | P1-TBDI2-13 | C1S5-13/P1-TBDI2-13 | P1-TBDI2-13/C1S5-13 | JB-401 | XV-40202B_DI_2 | XV-40202B | Slurry feed-out pH Adjustment tank 2 | Automatic on/off valve | 325-01-402-PD-01 | 24 VDC energized | On-Off | TeroFox / El-O-Matic | TF-20DFS Ball Valve + F-Actuator + ESV | CVV 3Cx1.5 (Solenoid) + CVV 4Cx1.0 (Limit Switches) | ACTIVE | -
67 | C1 | C1S5 | 1756-IB32 | DI (24VDC Digital Input) | 14 | IN-13 | P1-TBDI2-14 | C1S5-14/P1-TBDI2-14 | P1-TBDI2-14/C1S5-14 | JB-401 | XV-40202C_DI_1 | XV-40202C | Water washing line outlet pH Adjustment tank 2 | Automatic on/off valve | 325-01-402-PD-01 | 24 VDC energized | On-Off | TeroFox / El-O-Matic | TF-20DFS Ball Valve + F-Actuator + ESV | CVV 3Cx1.5 (Solenoid) + CVV 4Cx1.0 (Limit Switches) | ACTIVE | -
68 | C1 | C1S5 | 1756-IB32 | DI (24VDC Digital Input) | 15 | IN-14 | P1-TBDI2-15 | C1S5-15/P1-TBDI2-15 | P1-TBDI2-15/C1S5-15 | JB-401 | XV-40202C_DI_2 | XV-40202C | Water washing line outlet pH Adjustment tank 2 | Automatic on/off valve | 325-01-402-PD-01 | 24 VDC energized | On-Off | TeroFox / El-O-Matic | TF-20DFS Ball Valve + F-Actuator + ESV | CVV 3Cx1.5 (Solenoid) + CVV 4Cx1.0 (Limit Switches) | ACTIVE | -
69 | C1 | C1S5 | 1756-IB32 | DI (24VDC Digital Input) | 16 | IN-15 | P1-TBDI2-16 | C1S5-16/P1-TBDI2-16 | P1-TBDI2-16/C1S5-16 | JB-401 | XV-40202D_DI_1 | XV-40202D | Slurry circulation pH Adjustment tank 2 | Automatic on/off valve | 325-01-402-PD-01 | 24 VDC energized | On-Off | TeroFox / El-O-Matic | TF-20DFS Ball Valve + F-Actuator + ESV | CVV 3Cx1.5 (Solenoid) + CVV 4Cx1.0 (Limit Switches) | ACTIVE | -
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

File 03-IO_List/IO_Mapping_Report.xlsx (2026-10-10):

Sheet: 00_Executive_Summary
KALASIN ENGINEERING | xCIP-1545 AUTOMATION SYSTEM (Ref: x2608003)
MASTER PLC I/O MAPPING & HARDWARE ALLOCATION REPORT — SPRINT 18K TPA SPRAY DRYER / JET COOKER
TOTAL INSTRUMENTS |  | PHYSICAL PLC CHANNELS |  | ACTIVE PROCESS I/O |  | SPARE CAPACITY |  | COMMON / INTERNAL |  | NETWORK REDUNDANCY
560 |  | 1,466 |  | 746 |  | 561 |  | 159 |  | 1Gbps DLR RING
Rev 3.6a Master Client Schedule |  | 5 Chassis (C1-C5), 57 Slots |  | Assigned to Process Instruments |  | 38.3% Expansion Margin (>20% Req) |  | Power Commons, CPU & Comm Ports |  | EtherNet/IP Device Level Ring CA1-RIO
1. CONTROLLOGIX 1756 CHASSIS HARDWARE & UTILIZATION DIRECTORY
Chassis Code | Overview Sheet | Chassis & Function Description | Physical Location | Hardware Model | Mounted Slots | Total Channels | Active Channels | Spare Channels | Spare Margin % | Main Power Supply | Network Link | Cabinet / Panel
C1 | C1SlotConfig | Main Controller Rack (1756-L950TPSXT CPU) | Control Cabinet CA1 (Main Control Room MCP) | 1756-A13 (13-Slot ControlLogix Chassis) | 13 Slots (S0..S12) | 306 | 174 | 103 | 33.7% | 1756-PA75 (85-265VAC) | 1Gbps DLR Ring + SCADA Uplink | CA1 (Main Control Room MCP)
C2 | C2SlotConfig | Main Expansion Rack (High-Density Field I/O) | Control Cabinet CA1 (Main Control Room MCP) | 1756-A13 (13-Slot ControlLogix Chassis) | 13 Slots (S0..S12) | 436 | 230 | 164 | 37.6% | 1756-PA75 (85-265VAC) | Internal Backplane Bridge | CA1 (Main Control Room MCP)
C3 | C3SlotConfig | Remote I/O Rack 1 (Spray Dryer / Packing Tower) | Field RIO Cabinet (Spray Dryer / Packing Tower) | 1756-A13 (13-Slot ControlLogix Chassis) | 13 Slots (S0..S12) | 350 | 169 | 135 | 38.6% | 1756-PA75 (85-265VAC) | 1Gbps DLR Fiber Ring Ring Port 1/2 | Field RIO Cabinet (Spray Dryer)
C4 | C4SlotConfig | Remote I/O Rack 2 (Upper Spray Dryer 6th/8th Floor) | Field RIO Cabinet (Spray Dryer 6th/8th Floor) | 1756-A13 (13-Slot ControlLogix Chassis) | 13 Slots (S0..S12) | 226 | 103 | 95 | 42.0% | 1756-PA75 (85-265VAC) | 1Gbps DLR Copper Ring Port 1/2 | Field RIO Cabinet (6th/8th Fl)
C5 | C5SlotConfig | Remote I/O Station 5 (Slurry Building RIO-200) | Slurry Building 2nd Floor (RIO-200) | 1756-A7 (7-Slot ControlLogix Chassis) | 5 Slots (S0..S4) | 148 | 70 | 64 | 43.2% | 1756-PB75 (24VDC Redundant) | 1Gbps DLR Copper Ring (Slurry Bldg) | Slurry Bldg 2nd Fl (RIO-200)
TOTAL SYSTEM CAPACITY (5 CHASSIS) |  |  |  |  |  | 1466 | 746 | 561 | 38.3% | - | - | -
2. I/O SIGNAL FAMILY & MODULE SCHEDULE |  |  |  |  |  |  | 3. CLIENT INSTRUMENT SCOPE & DESTINATION SUMMARY
Signal Family | Module Hardware | Signal Type | Total Pts | Active Pts | Spare Pts |  | Scope Destination | Primary Wiring Target | Loop Count | Active Pts | Typical Cable | Interface Remark
DI (24VDC Digital Input) | 1756-IB32 (32-Pt Sink/Source) | 24VDC Dry Contact / PNP | 612 | 334 | 210 |  | Direct to Main PLC (CA1/RIO) | Chassis C1, C2, C3, C4 | 454 | 676 | LiY-CY TP 1Px1.0 / CVV | Main Process Automation
DO (24VDC Digital Output) | 1756-OB32 (32-Pt Source Transistor) | 24VDC Energized Solenoids | 324 | 122 | 184 |  | Slurry Bldg RIO-200 | Chassis C5 (Slurry 2nd Fl) | 36 | 70 | LiY-CY TP / CVV Multi-core | Slurry Preparation Area
AI (4-20mA / RTD / Volts) | 1756-IF16 (16-Pt Single-Ended / Diff) | 4-20mA HART Transmitter | 468 | 252 | 164 |  | Air Heater Panel (AHTR) | AHTR Package Control Panel | 22 | 0 | Package Vendor Cables | Dryer Air Heater Skid
AO (4-20mA Analog Output) | 1756-OF8 (8-Pt Voltage / Current) | 4-20mA Control Valves (CV) | 20 | 5 | 3 |  | Heat Control Panel (HCP) | HCP Control Panel | 11 | 0 | Package Vendor Cables | Burner / Heat Package
CPU (Main Controller) | 1756-L950TPSXT (ControlLogix 5580) | Process Controller & SD/USB | 5 | 5 | 0 |  | Fire Deluge / Suppression | Suppression / Deluge Skid | 7 | 0 | Fire Rated Cable | Safety & Fire Interlock
COMM (EtherNet/IP) | 1756-EN4TR (1Gbps 2-Port DLR) | DLR Device Level Ring | 28 | 28 | 0 |  | Local Mechanical Instruments | Local Pipe / Equipment Dial | 23 | 0 | None (Direct Reading) | Pressure Gauges & Sight Glass
EMPTY (Chassis Slot Reserve) | 1756-N2 (Slot Filler Blank Plate) | Future Hardware Expansion | 9 | 0 | 0 |  | Other Package / MCC | MCC / Heat Control HTRE | 7 | 0 | Vendor / Hardwire Interlock | VSD / Motor Feeders

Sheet: 02_PLC_Channel_IO_Mapping
KALASIN ENGINEERING | CONTROLLOGIX 1756 POINT-BY-POINT PLC I/O CHANNEL MAPPING
1,466 Physical Terminal Channels across 5 Chassis (C1S0 - C5S4) with Marshaling Blocks, Field Wire Marks & Instrument Master Data
Seq No. | Chassis | Slot Tag | Module Catalog | Signal Family | Terminal Pin | Channel / Terminal Description | Marshaling Terminal (Px-TB) | Wire Mark (PLC Side) | Wire Mark (Terminal Side) | Destination Area | PLC Tag Name | Instrument Tag | Instrument Description | Instrument Name / Type | P&ID No. | Signal Type | Calibrated Range | Manufacturer | Model Series | Suggested Field Cable | Channel Status | Engineering Remark
1 | C1 | C1S0 | 1756-L950TPSXT | CPU (Controller) | RJ45-1 | Embedded 1Gbps EtherNet/IP Port (SCADA / Enterprise Network) | ETH-CORE-01 | C1S0-ETH1/SW-CORE-01 | SW-CORE-01/C1S0-ETH1 | CA1 (Main Control Room) | CPU_Embedded_ETH | PLC-01 | Main Process Controller EtherNet/IP Uplink Port | Process Field Device | - | - | - | Industrial Process Equipment | Standard Process Field Device | CVV 2Cx1.5 / LiY-CY 1Px1.0 General Control | ACTIVE | -
2 | C1 | C1S0 | 1756-L950TPSXT | CPU (Controller) | USB-1 | USB 2.0 Type-B Programming Port (Maintenance / Diagnostics) | USB-CONSOLE | C1S0-USB/CONSOLE | CONSOLE/C1S0-USB | CA1 (Main Control Room) | CPU_USB_Console | USB-PGM | Engineering Workstation Maintenance Access Port | Process Field Device | - | - | - | Industrial Process Equipment | Standard Process Field Device | CVV 2Cx1.5 / LiY-CY 1Px1.0 General Control | ACTIVE | -
3 | C1 | C1S0 | 1756-L950TPSXT | CPU (Controller) | SD-1 | 1784-SD2 Industrial SD Memory Card Slot (Firmware & Program Backup) | SD-SLOT | C1S0-SD/INTERNAL | INTERNAL/C1S0-SD | CA1 (Main Control Room) | CPU_SD_Card | 1784-SD2 | Non-volatile System Image & User Program Storage | Process Field Device | - | - | - | Industrial Process Equipment | Standard Process Field Device | CVV 2Cx1.5 / LiY-CY 1Px1.0 General Control | ACTIVE | -
4 | C1 | C1S0 | 1756-L950TPSXT | CPU (Controller) | ESM-1 | Capacitor Energy Storage Module (Maintenance-free, Battery-free) | ESM-CAP | C1S0-ESM/INTERNAL | INTERNAL/C1S0-ESM | CA1 (Main Control Room) | CPU_ESM_Module | 1756-ESMCAP | Energy Storage Module for Power Loss Data Retention | Process Field Device | - | - | - | Industrial Process Equipment | Standard Process Field Device | CVV 2Cx1.5 / LiY-CY 1Px1.0 General Control | ACTIVE | -
5 | C1 | C1S0 | 1756-L950TPSXT | CPU (Controller) | DISP-1 | 4-Character Alphanumeric Diagnostic Display & Status LEDs (RUN, FORCE, SD, OK) | DIAG-DISP | C1S0-DISP/DIAG | DIAG/C1S0-DISP | CA1 (Main Control Room) | CPU_Status_Display | DIAG-LED | System Controller Status & Fault Diagnostic Indicators | Process Field Device | - | - | - | Industrial Process Equipment | Standard Process Field Device | CVV 2Cx1.5 / LiY-CY 1Px1.0 General Control | ACTIVE | -
6 | C1 | C1S1 | 1756-EN4TR | COMM (EtherNet/IP) | RJ45-1 | EtherNet/IP Port 1 (DLR Ring Node 1 / Primary Adapter Link) | ETH-DLR-P1 | C1S1-/- | -/C1S1- | CA1 | C1S1_ETH_Port1 | ETH-01 | 10/100/1000 Mbps RJ45 Device Level Ring Port 1 | Process Field Device | - | - | - | Industrial Process Equipment | Standard Process Field Device | CVV 2Cx1.5 / LiY-CY 1Px1.0 General Control | ACTIVE | -
7 | C1 | C1S1 | 1756-EN4TR | COMM (EtherNet/IP) | RJ45-2 | EtherNet/IP Port 2 (DLR Ring Node 2 / Redundant Loop) | ETH-DLR-P2 | C1S1-P2/ETH | ETH/C1S1-P2 | CA1 | C1S1_ETH_Port2 | ETH-02 | 10/100/1000 Mbps RJ45 Device Level Ring Port 2 | Process Field Device | - | - | - | Industrial Process Equipment | Standard Process Field Device | CVV 2Cx1.5 / LiY-CY 1Px1.0 General Control | ACTIVE | -
8 | C1 | C1S1 | 1756-EN4TR | COMM (EtherNet/IP) | USB-1 | USB 2.0 Type-B Device Port (Local Configuration & Diagnostics) | USB-CONSOLE | C1S1-USB/CONSOLE | CONSOLE/C1S1-USB | CA1 | C1S1_USB_Config | USB-CFG | Local IP Configuration and Firmware Flashing Port | Process Field Device | - | - | - | Industrial Process Equipment | Standard Process Field Device | CVV 2Cx1.5 / LiY-CY 1Px1.0 General Control | ACTIVE | -
9 | C1 | C1S1 | 1756-EN4TR | COMM (EtherNet/IP) | DISP-1 | 4-Character Diagnostic Display & Status LEDs (OK, NET A/B, LINK 1/2) | DIAG-DISP | C1S1-DISP/DIAG | DIAG/C1S1-DISP | CA1 | C1S1_Status_Display | DIAG-LED | Hardware Status & Network Link Diagnostic Indicators | Process Field Device | - | - | - | Industrial Process Equipment | Standard Process Field Device | CVV 2Cx1.5 / LiY-CY 1Px1.0 General Control | ACTIVE | -
10 | C1 | C1S2 | 1756-EN4TR | COMM (EtherNet/IP) | RJ45-1 | EtherNet/IP Port 1 (DLR Ring Node 1 / Primary Adapter Link) | ETH-DLR-P1 | C1S2-/- | -/C1S2- | CA1 | C1S2_ETH_Port1 | ETH-01 | 10/100/1000 Mbps RJ45 Device Level Ring Port 1 | Process Field Device | - | - | - | Industrial Process Equipment | Standard Process Field Device | CVV 2Cx1.5 / LiY-CY 1Px1.0 General Control | ACTIVE | -
11 | C1 | C1S2 | 1756-EN4TR | COMM (EtherNet/IP) | RJ45-2 | EtherNet/IP Port 2 (DLR Ring Node 2 / Redundant Loop) | ETH-DLR-P2 | C1S2-P2/ETH | ETH/C1S2-P2 | CA1 | C1S2_ETH_Port2 | ETH-02 | 10/100/1000 Mbps RJ45 Device Level Ring Port 2 | Process Field Device | - | - | - | Industrial Process Equipment | Standard Process Field Device | CVV 2Cx1.5 / LiY-CY 1Px1.0 General Control | ACTIVE | -
12 | C1 | C1S2 | 1756-EN4TR | COMM (EtherNet/IP) | USB-1 | USB 2.0 Type-B Device Port (Local Configuration & Diagnostics) | USB-CONSOLE | C1S2-USB/CONSOLE | CONSOLE/C1S2-USB | CA1 | C1S2_USB_Config | USB-CFG | Local IP Configuration and Firmware Flashing Port | Process Field Device | - | - | - | Industrial Process Equipment | Standard Process Field Device | CVV 2Cx1.5 / LiY-CY 1Px1.0 General Control | ACTIVE | -
13 | C1 | C1S2 | 1756-EN4TR | COMM (EtherNet/IP) | DISP-1 | 4-Character Diagnostic Display & Status LEDs (OK, NET A/B, LINK 1/2) | DIAG-DISP | C1S2-DISP/DIAG | DIAG/C1S2-DISP | CA1 | C1S2_Status_Display | DIAG-LED | Hardware Status & Network Link Diagnostic Indicators | Process Field Device | - | - | - | Industrial Process Equipment | Standard Process Field Device | CVV 2Cx1.5 / LiY-CY 1Px1.0 General Control | ACTIVE | -
14 | C1 | C1S3 | 1756-EN4TR | COMM (EtherNet/IP) | RJ45-1 | EtherNet/IP Port 1 (DLR Ring Node 1 / Primary Adapter Link) | ETH-DLR-P1 | C1S3-/- | -/C1S3- | CA1 | C1S3_ETH_Port1 | ETH-01 | 10/100/1000 Mbps RJ45 Device Level Ring Port 1 | Process Field Device | - | - | - | Industrial Process Equipment | Standard Process Field Device | CVV 2Cx1.5 / LiY-CY 1Px1.0 General Control | ACTIVE | -
15 | C1 | C1S3 | 1756-EN4TR | COMM (EtherNet/IP) | RJ45-2 | EtherNet/IP Port 2 (DLR Ring Node 2 / Redundant Loop) | ETH-DLR-P2 | C1S3-P2/ETH | ETH/C1S3-P2 | CA1 | C1S3_ETH_Port2 | ETH-02 | 10/100/1000 Mbps RJ45 Device Level Ring Port 2 | Process Field Device | - | - | - | Industrial Process Equipment | Standard Process Field Device | CVV 2Cx1.5 / LiY-CY 1Px1.0 General Control | ACTIVE | -
16 | C1 | C1S3 | 1756-EN4TR | COMM (EtherNet/IP) | USB-1 | USB 2.0 Type-B Device Port (Local Configuration & Diagnostics) | USB-CONSOLE | C1S3-USB/CONSOLE | CONSOLE/C1S3-USB | CA1 | C1S3_USB_Config | USB-CFG | Local IP Configuration and Firmware Flashing Port | Process Field Device | - | - | - | Industrial Process Equipment | Standard Process Field Device | CVV 2Cx1.5 / LiY-CY 1Px1.0 General Control | ACTIVE | -
17 | C1 | C1S3 | 1756-EN4TR | COMM (EtherNet/IP) | DISP-1 | 4-Character Diagnostic Display & Status LEDs (OK, NET A/B, LINK 1/2) | DIAG-DISP | C1S3-DISP/DIAG | DIAG/C1S3-DISP | CA1 | C1S3_Status_Display | DIAG-LED | Hardware Status & Network Link Diagnostic Indicators | Process Field Device | - | - | - | Industrial Process Equipment | Standard Process Field Device | CVV 2Cx1.5 / LiY-CY 1Px1.0 General Control | ACTIVE | -
18 | C1 | C1S4 | 1756-IB32 | DI (24VDC Digital Input) | 1 | IN-0 | P1-TBDI1-1 | C1S4-1/P1-TBDI1-1 | P1-TBDI1-1/C1S4-1 | CA1 | Spare_DI_0 | Spare | Spare Reserve Channel | - | - | 24VDC Discrete | - | - | - | Reserved for Future Loop | SPARE | Spare Reserve Channel
19 | C1 | C1S4 | 1756-IB32 | DI (24VDC Digital Input) | 2 | IN-1 | P1-TBDI1-2 | C1S4-2/P1-TBDI1-2 | P1-TBDI1-2/C1S4-2 | CA1 | Spare_DI_0 | Spare | Spare Reserve Channel | - | - | 24VDC Discrete | - | - | - | Reserved for Future Loop | SPARE | Spare Reserve Channel
20 | C1 | C1S4 | 1756-IB32 | DI (24VDC Digital Input) | 3 | IN-2 | P1-TBDI1-3 | C1S4-3/P1-TBDI1-3 | P1-TBDI1-3/C1S4-3 | CA1 | Spare_DI_0 | Spare | Spare Reserve Channel | - | - | 24VDC Discrete | - | - | - | Reserved for Future Loop | SPARE | Spare Reserve Channel
21 | C1 | C1S4 | 1756-IB32 | DI (24VDC Digital Input) | 4 | IN-3 | P1-TBDI1-4 | C1S4-4/P1-TBDI1-4 | P1-TBDI1-4/C1S4-4 | CA1 | Spare_DI_0 | Spare | Spare Reserve Channel | - | - | 24VDC Discrete | - | - | - | Reserved for Future Loop | SPARE | Spare Reserve Channel
22 | C1 | C1S4 | 1756-IB32 | DI (24VDC Digital Input) | 5 | IN-4 | P1-TBDI1-5 | C1S4-5/P1-TBDI1-5 | P1-TBDI1-5/C1S4-5 | CA1 | Spare_DI_0 | Spare | Spare Reserve Channel | - | - | 24VDC Discrete | - | - | - | Reserved for Future Loop | SPARE | Spare Reserve Channel
23 | C1 | C1S4 | 1756-IB32 | DI (24VDC Digital Input) | 6 | IN-5 | P1-TBDI1-6 | C1S4-6/P1-TBDI1-6 | P1-TBDI1-6/C1S4-6 | CA1 | Spare_DI_0 | Spare | Spare Reserve Channel | - | - | 24VDC Discrete | - | - | - | Reserved for Future Loop | SPARE | Spare Reserve Channel
24 | C1 | C1S4 | 1756-IB32 | DI (24VDC Digital Input) | 7 | IN-6 | P1-TBDI1-7 | C1S4-7/P1-TBDI1-7 | P1-TBDI1-7/C1S4-7 | CA1 | Spare_DI_0 | Spare | Spare Reserve Channel | - | - | 24VDC Discrete | - | - | - | Reserved for Future Loop | SPARE | Spare Reserve Channel
25 | C1 | C1S4 | 1756-IB32 | DI (24VDC Digital Input) | 8 | IN-7 | P1-TBDI1-8 | C1S4-8/P1-TBDI1-8 | P1-TBDI1-8/C1S4-8 | CA1 | Spare_DI_0 | Spare | Spare Reserve Channel | - | - | 24VDC Discrete | - | - | - | Reserved for Future Loop | SPARE | Spare Reserve Channel
26 | C1 | C1S4 | 1756-IB32 | DI (24VDC Digital Input) | 9 | IN-8 | P1-TBDI1-9 | C1S4-9/P1-TBDI1-9 | P1-TBDI1-9/C1S4-9 | CA1 | Spare_DI_0 | Spare | Spare Reserve Channel | - | - | 24VDC Discrete | - | - | - | Reserved for Future Loop | SPARE | Spare Reserve Channel
27 | C1 | C1S4 | 1756-IB32 | DI (24VDC Digital Input) | 10 | IN-9 | P1-TBDI1-10 | C1S4-10/P1-TBDI1-10 | P1-TBDI1-10/C1S4-10 | CA1 | Spare_DI_0 | Spare | Spare Reserve Channel | - | - | 24VDC Discrete | - | - | - | Reserved for Future Loop | SPARE | Spare Reserve Channel
28 | C1 | C1S4 | 1756-IB32 | DI (24VDC Digital Input) | 11 | IN-10 | P1-TBDI1-11 | C1S4-11/P1-TBDI1-11 | P1-TBDI1-11/C1S4-11 | CA1 | Spare_DI_0 | Spare | Spare Reserve Channel | - | - | 24VDC Discrete | - | - | - | Reserved for Future Loop | SPARE | Spare Reserve Channel
29 | C1 | C1S4 | 1756-IB32 | DI (24VDC Digital Input) | 12 | IN-11 | P1-TBDI1-12 | C1S4-12/P1-TBDI1-12 | P1-TBDI1-12/C1S4-12 | CA1 | Spare_DI_0 | Spare | Spare Reserve Channel | - | - | 24VDC Discrete | - | - | - | Reserved for Future Loop | SPARE | Spare Reserve Channel
30 | C1 | C1S4 | 1756-IB32 | DI (24VDC Digital Input) | 13 | IN-12 | P1-TBDI1-13 | C1S4-13/P1-TBDI1-13 | P1-TBDI1-13/C1S4-13 | CA1 | Spare_DI_0 | Spare | Spare Reserve Channel | - | - | 24VDC Discrete | - | - | - | Reserved for Future Loop | SPARE | Spare Reserve Channel
31 | C1 | C1S4 | 1756-IB32 | DI (24VDC Digital Input) | 14 | IN-13 | P1-TBDI1-14 | C1S4-14/P1-TBDI1-14 | P1-TBDI1-14/C1S4-14 | CA1 | Spare_DI_0 | Spare | Spare Reserve Channel | - | - | 24VDC Discrete | - | - | - | Reserved for Future Loop | SPARE | Spare Reserve Channel
32 | C1 | C1S4 | 1756-IB32 | DI (24VDC Digital Input) | 15 | IN-14 | P1-TBDI1-15 | C1S4-15/P1-TBDI1-15 | P1-TBDI1-15/C1S4-15 | CA1 | Spare_DI_0 | Spare | Spare Reserve Channel | - | - | 24VDC Discrete | - | - | - | Reserved for Future Loop | SPARE | Spare Reserve Channel
33 | C1 | C1S4 | 1756-IB32 | DI (24VDC Digital Input) | 16 | IN-15 | P1-TBDI1-16 | C1S4-16/P1-TBDI1-16 | P1-TBDI1-16/C1S4-16 | CA1 | Spare_DI_0 | Spare | Spare Reserve Channel | - | - | 24VDC Discrete | - | - | - | Reserved for Future Loop | SPARE | Spare Reserve Channel
34 | C1 | C1S4 | 1756-IB32 | DI (24VDC Digital Input) | 17 | GND-0 | 0VDC | 0VDC | 0VDC | CA1 | Internal Power Common | - | Module Power / Common Return Terminal | - | - | 24VDC Discrete | - | - | - | - | COMMON | -
35 | C1 | C1S4 | 1756-IB32 | DI (24VDC Digital Input) | 18 | GND-0 | 0VDC | 0VDC | 0VDC | CA1 | Internal Power Common | - | Module Power / Common Return Terminal | - | - | 24VDC Discrete | - | - | - | - | COMMON | -
36 | C1 | C1S4 | 1756-IB32 | DI (24VDC Digital Input) | 19 | IN-16 | P1-TBDI1-17 | C1S4-19/P1-TBDI1-17 | P1-TBDI1-17/C1S4-19 | JB-401 | FSL-40201_DI_1 | FSL-40201 | Flow Switch | Flow Switch | 325-01-402-PD-01 | Dry Contact |  | Industrial Process Equipment | Standard Process Field Device | CVV 2Cx1.5 / LiY-CY 1Px1.0 General Control | ACTIVE | Jet Cooker
37 | C1 | C1S4 | 1756-IB32 | DI (24VDC Digital Input) | 20 | IN-17 | P1-TBDI1-18 | C1S4-20/P1-TBDI1-18 | P1-TBDI1-18/C1S4-20 | JB-401 | FSL-40202_DI_1 | FSL-40202 | Flow Switch | Flow Switch | 325-01-402-PD-01 | Dry Contact |  | Industrial Process Equipment | Standard Process Field Device | CVV 2Cx1.5 / LiY-CY 1Px1.0 General Control | ACTIVE | Jet Cooker
38 | C1 | C1S4 | 1756-IB32 | DI (24VDC Digital Input) | 21 | IN-18 | P1-TBDI1-19 | C1S4-21/P1-TBDI1-19 | P1-TBDI1-19/C1S4-21 | JB-401 | FT-40201_DI_1 | FT-40201 | Coriolis Flow Transmitter | Coriolis Flow Transmitter | 325-01-402-PD-02 | 4 - 20 mA,Pulse | 0-15 m³/hr | Endress+Hauser | Promass F 300 / 83F (Coriolis Mass Flow) | LiY-CY TP 1Px1.0 (Shielded Pair) | ACTIVE | -
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

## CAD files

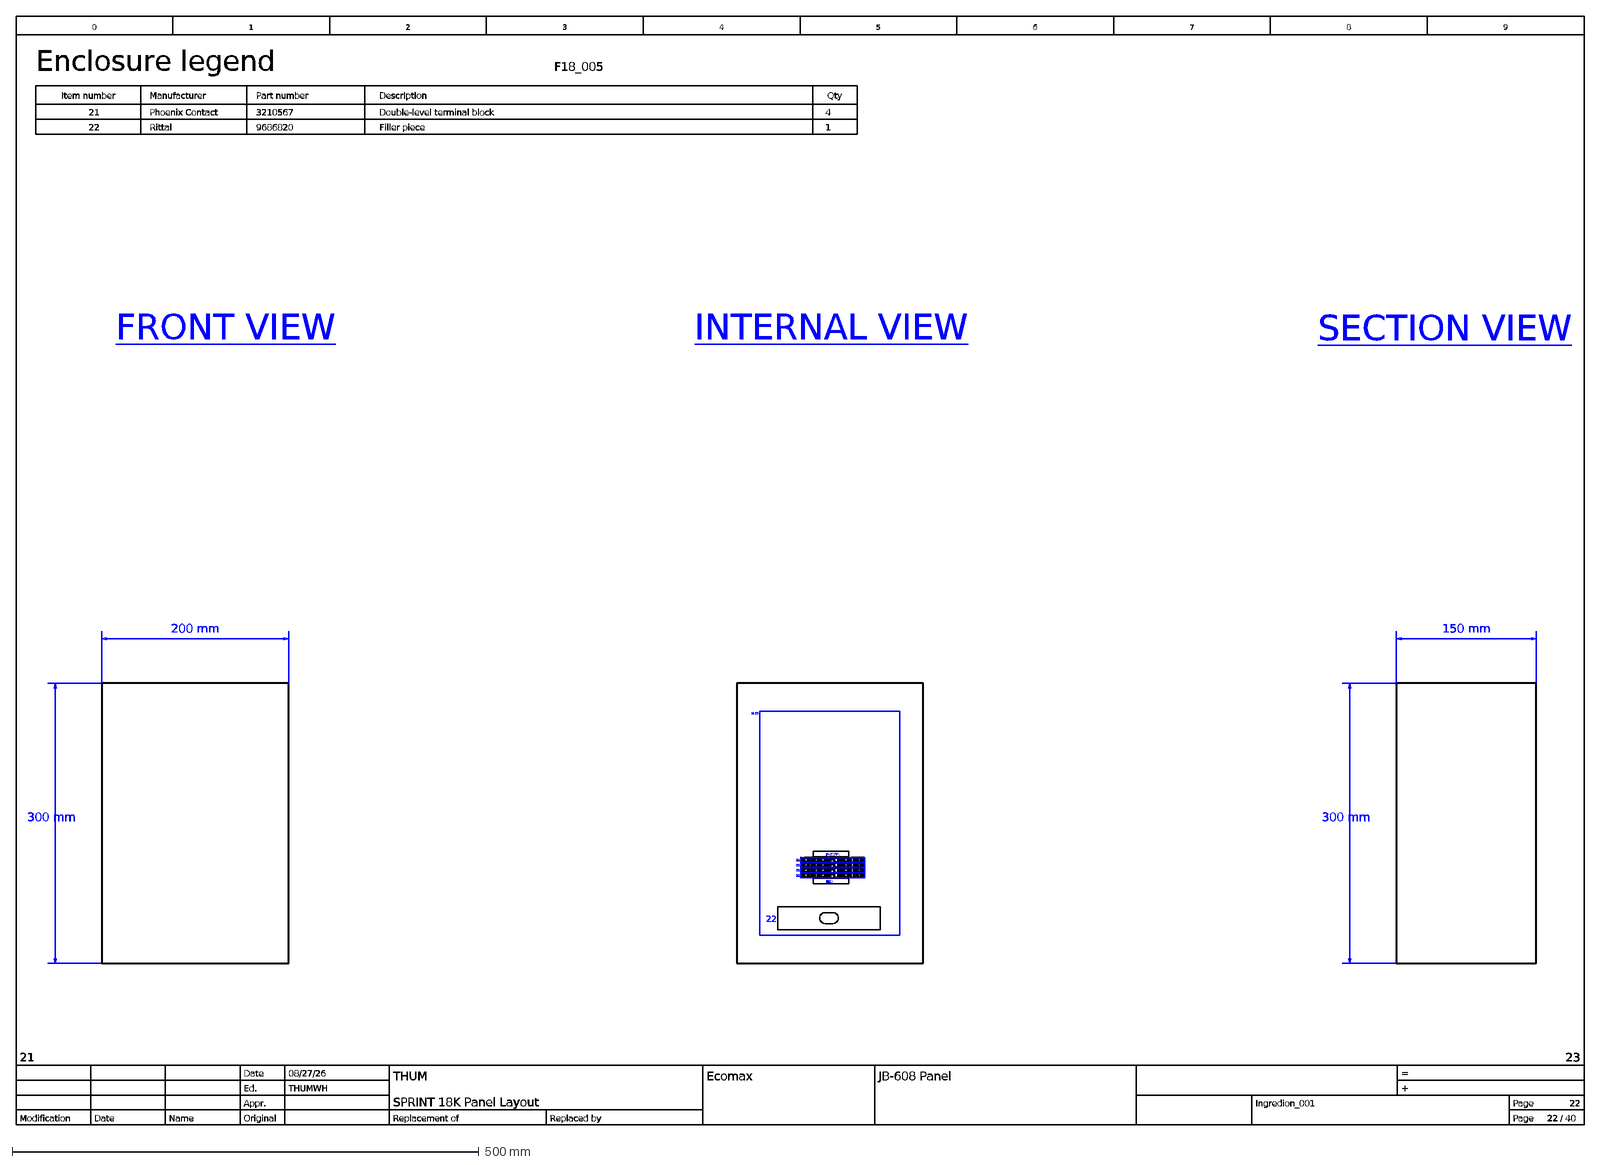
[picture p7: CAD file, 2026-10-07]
02_Electrical_and_eDrawing/02_ePlan_Exports/SPRINT 18K SPRAY DRYER/22.dxf
SPRINT 18K Panel Layout
21
Ingredion_001
THUM
THUMWH
JB-608 Panel
1
0
7
6
8
9
3
40
23
4
08/27/26
Ecomax
22
2
5
Page
Ed.
Original
+
Date
Replaced by
Modification
Appr.
Replacement of
=
Name
/
Enclosure legend
F18_005
Part number
Manufacturer
Item number
Qty
Description
Phoenix Contact
3210567
Double-level terminal block
Rittal
9686820
Filler piece
JB-608TB
END
FRONT VIEW
INTERNAL VIEW
SECTION VIEW
200 mm
300 mm
150 mm
M.22

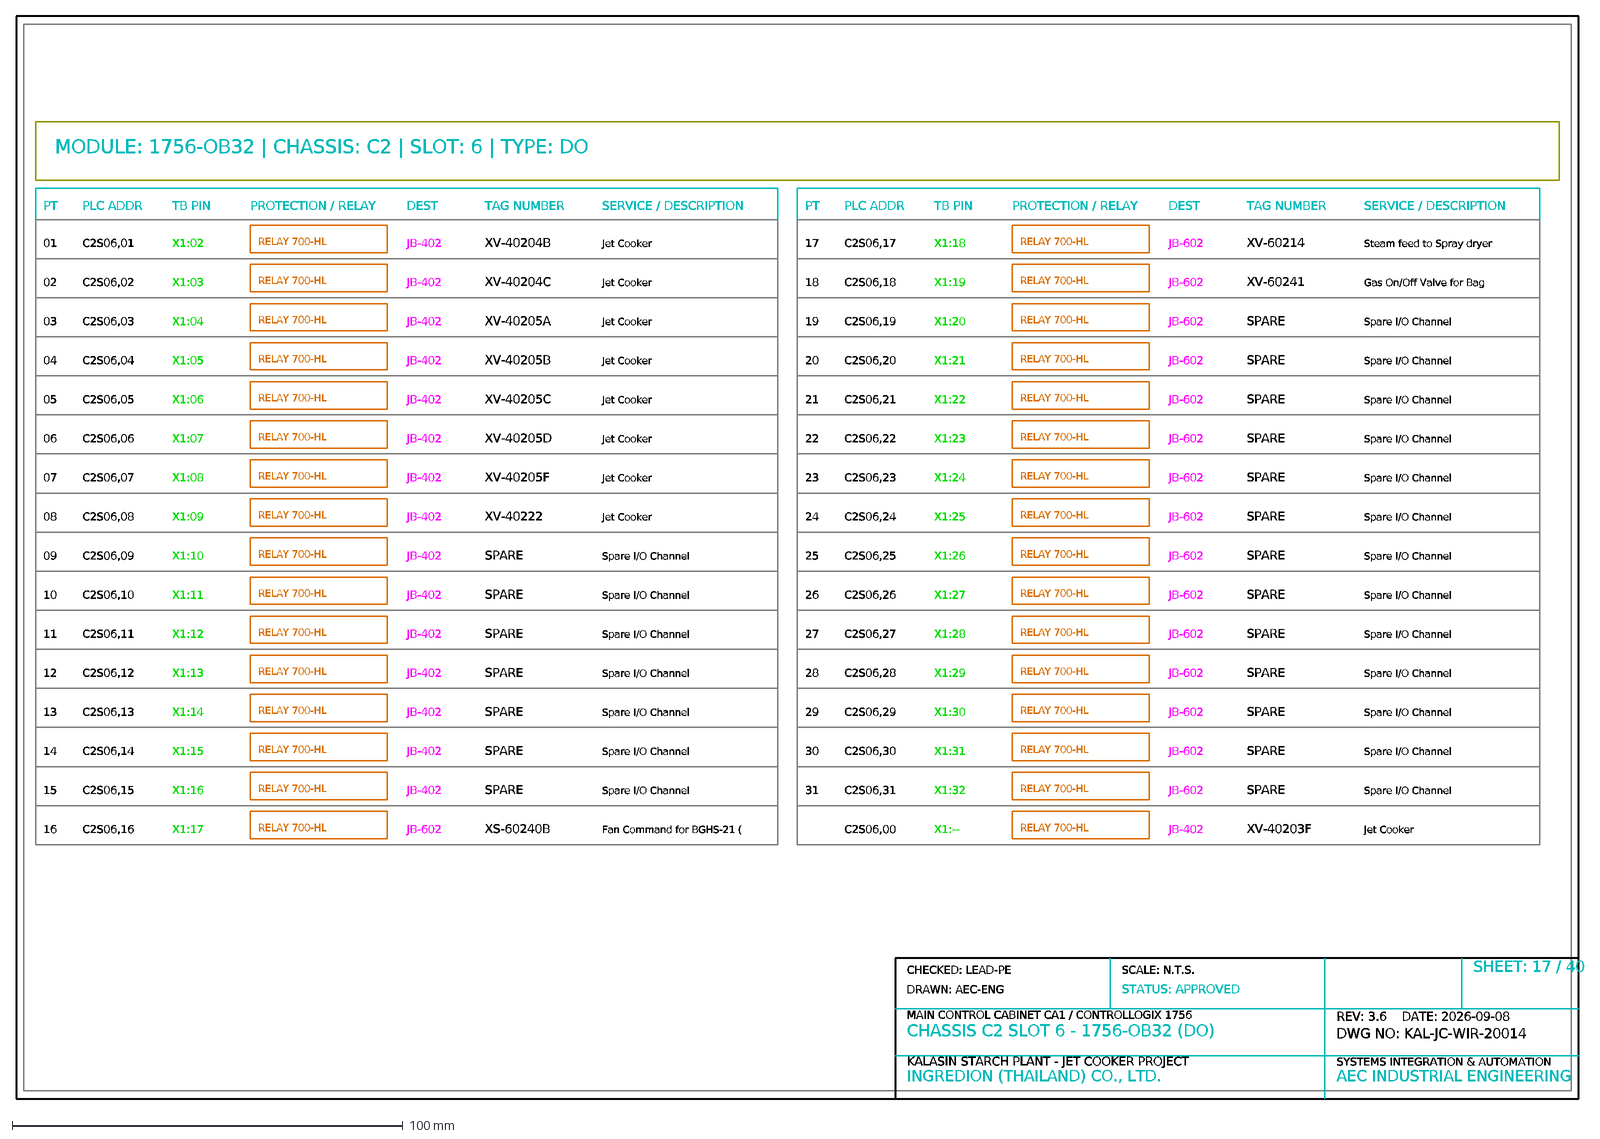
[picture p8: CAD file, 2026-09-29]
02_Electrical_and_eDrawing/03_CAD_Exports_DXF_SVG/01_PLC_IO_Wiring_DXF/KAL-JC-WIR-20014_Sheet17_Chassis_C2_Slot_6_DO.dxf
INGREDION (THAILAND) CO., LTD.
KALASIN STARCH PLANT - JET COOKER PROJECT
AEC INDUSTRIAL ENGINEERING
SYSTEMS INTEGRATION & AUTOMATION
CHASSIS C2 SLOT 6 - 1756-OB32 (DO)
MAIN CONTROL CABINET CA1 / CONTROLLOGIX 1756
DWG NO: KAL-JC-WIR-20014
REV: 3.6 DATE: 2026-09-08
DRAWN: AEC-ENG
CHECKED: LEAD-PE
STATUS: APPROVED
SCALE: N.T.S.
SHEET: 17 / 40
MODULE: 1756-OB32 | CHASSIS: C2 | SLOT: 6 | TYPE: DO
PT
PLC ADDR
TB PIN
PROTECTION / RELAY
DEST
TAG NUMBER
SERVICE / DESCRIPTION
01
C2S06,01
X1:02
RELAY 700-HL
JB-402
XV-40204B
Jet Cooker
02
C2S06,02
X1:03
XV-40204C
03
C2S06,03
X1:04
XV-40205A
04
C2S06,04
X1:05
XV-40205B
05
C2S06,05
X1:06
XV-40205C
06
C2S06,06
X1:07
XV-40205D
07
C2S06,07
X1:08
XV-40205F
08
C2S06,08
X1:09
XV-40222
09
C2S06,09
X1:10
SPARE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

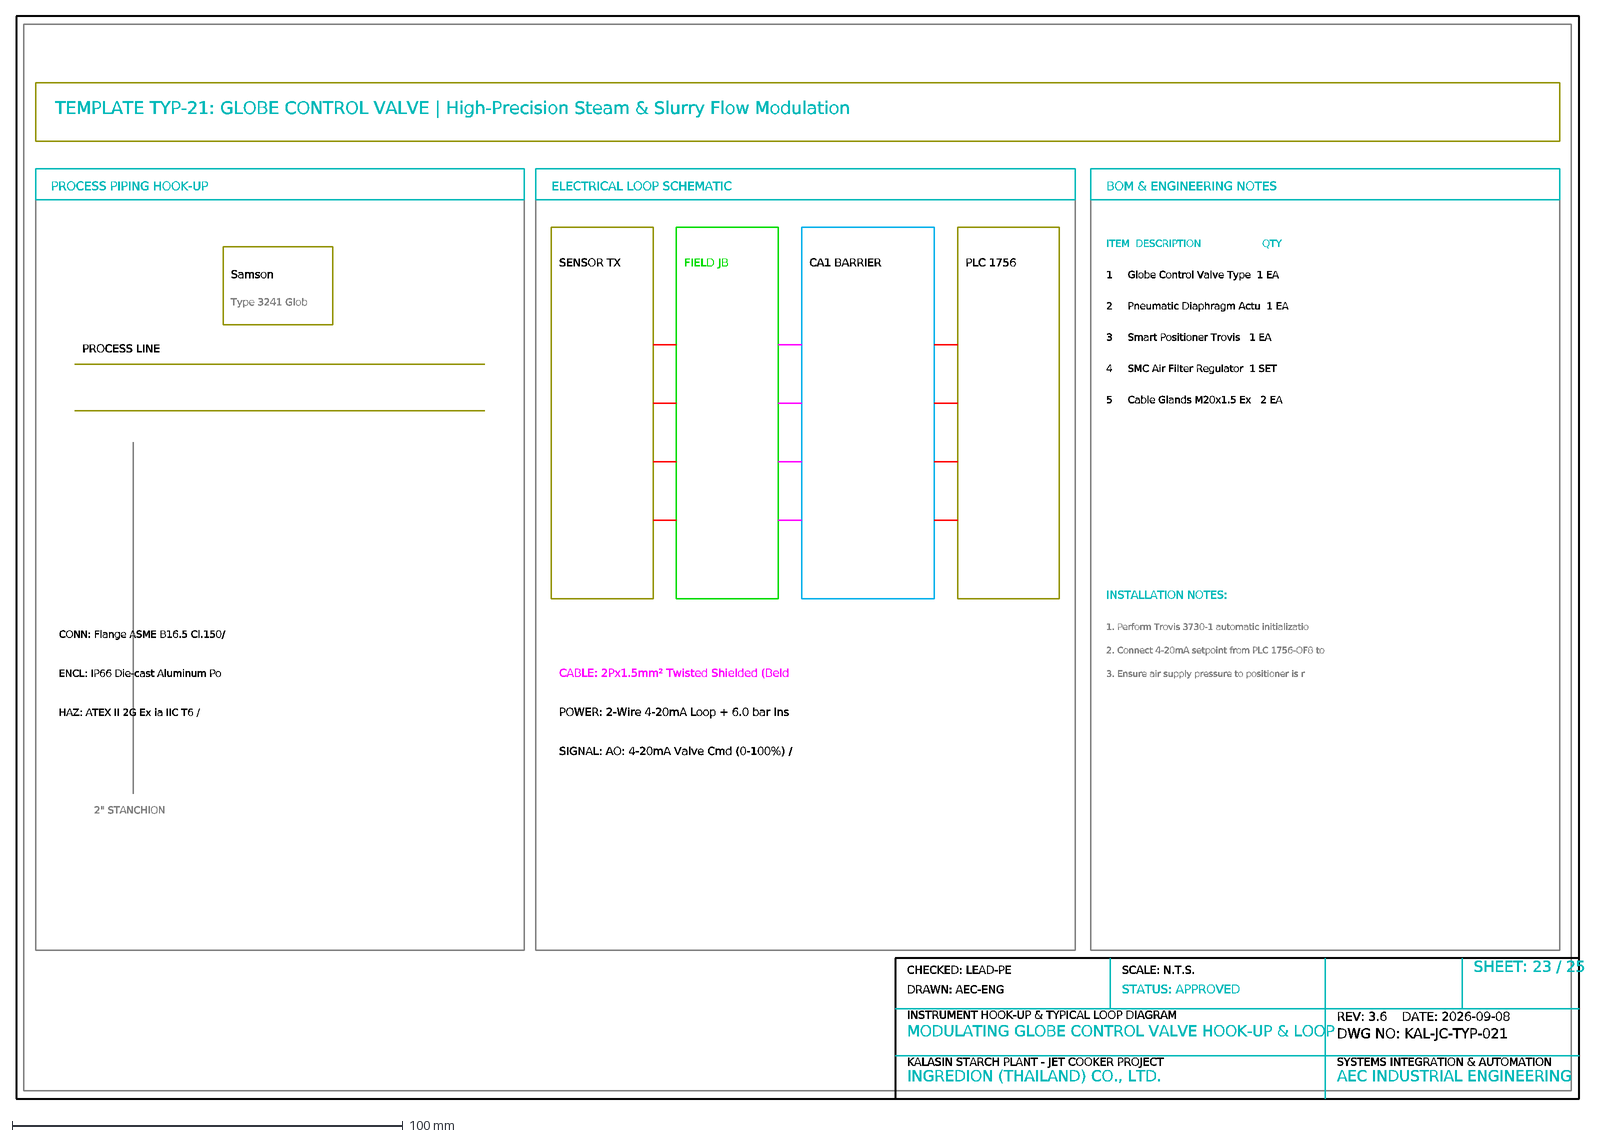
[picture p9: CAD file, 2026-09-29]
02_Electrical_and_eDrawing/03_CAD_Exports_DXF_SVG/02_Instrument_Typical_DXF/KAL-JC-TYP-021_Sheet23_TYP-21_Globe_Control_Valve.dxf
INGREDION (THAILAND) CO., LTD.
KALASIN STARCH PLANT - JET COOKER PROJECT
AEC INDUSTRIAL ENGINEERING
SYSTEMS INTEGRATION & AUTOMATION
MODULATING GLOBE CONTROL VALVE HOOK-UP & LOOP
INSTRUMENT HOOK-UP & TYPICAL LOOP DIAGRAM
DWG NO: KAL-JC-TYP-021
REV: 3.6 DATE: 2026-09-08
DRAWN: AEC-ENG
CHECKED: LEAD-PE
STATUS: APPROVED
SCALE: N.T.S.
SHEET: 23 / 25
TEMPLATE TYP-21: GLOBE CONTROL VALVE | High-Precision Steam & Slurry Flow Modulation
PROCESS PIPING HOOK-UP
PROCESS LINE
Samson
Type 3241 Glob
2" STANCHION
CONN: Flange ASME B16.5 Cl.150/
ENCL: IP66 Die-cast Aluminum Po
HAZ: ATEX II 2G Ex ia IIC T6 /
ELECTRICAL LOOP SCHEMATIC
SENSOR TX
FIELD JB
CA1 BARRIER
PLC 1756
CABLE: 2Px1.5mm² Twisted Shielded (Beld
POWER: 2-Wire 4-20mA Loop + 6.0 bar Ins
SIGNAL: AO: 4-20mA Valve Cmd (0-100%) /
BOM & ENGINEERING NOTES
ITEM DESCRIPTION QTY
1 Globe Control Valve Type 1 EA
2 Pneumatic Diaphragm Actu 1 EA
3 Smart Positioner Trovis 1 EA
4 SMC Air Filter Regulator 1 SET
5 Cable Glands M20x1.5 Ex 2 EA
INSTALLATION NOTES:
1. Perform Trovis 3730-1 automatic initializatio
2. Connect 4-20mA setpoint from PLC 1756-OF8 to
3. Ensure air supply pressure to positioner is r

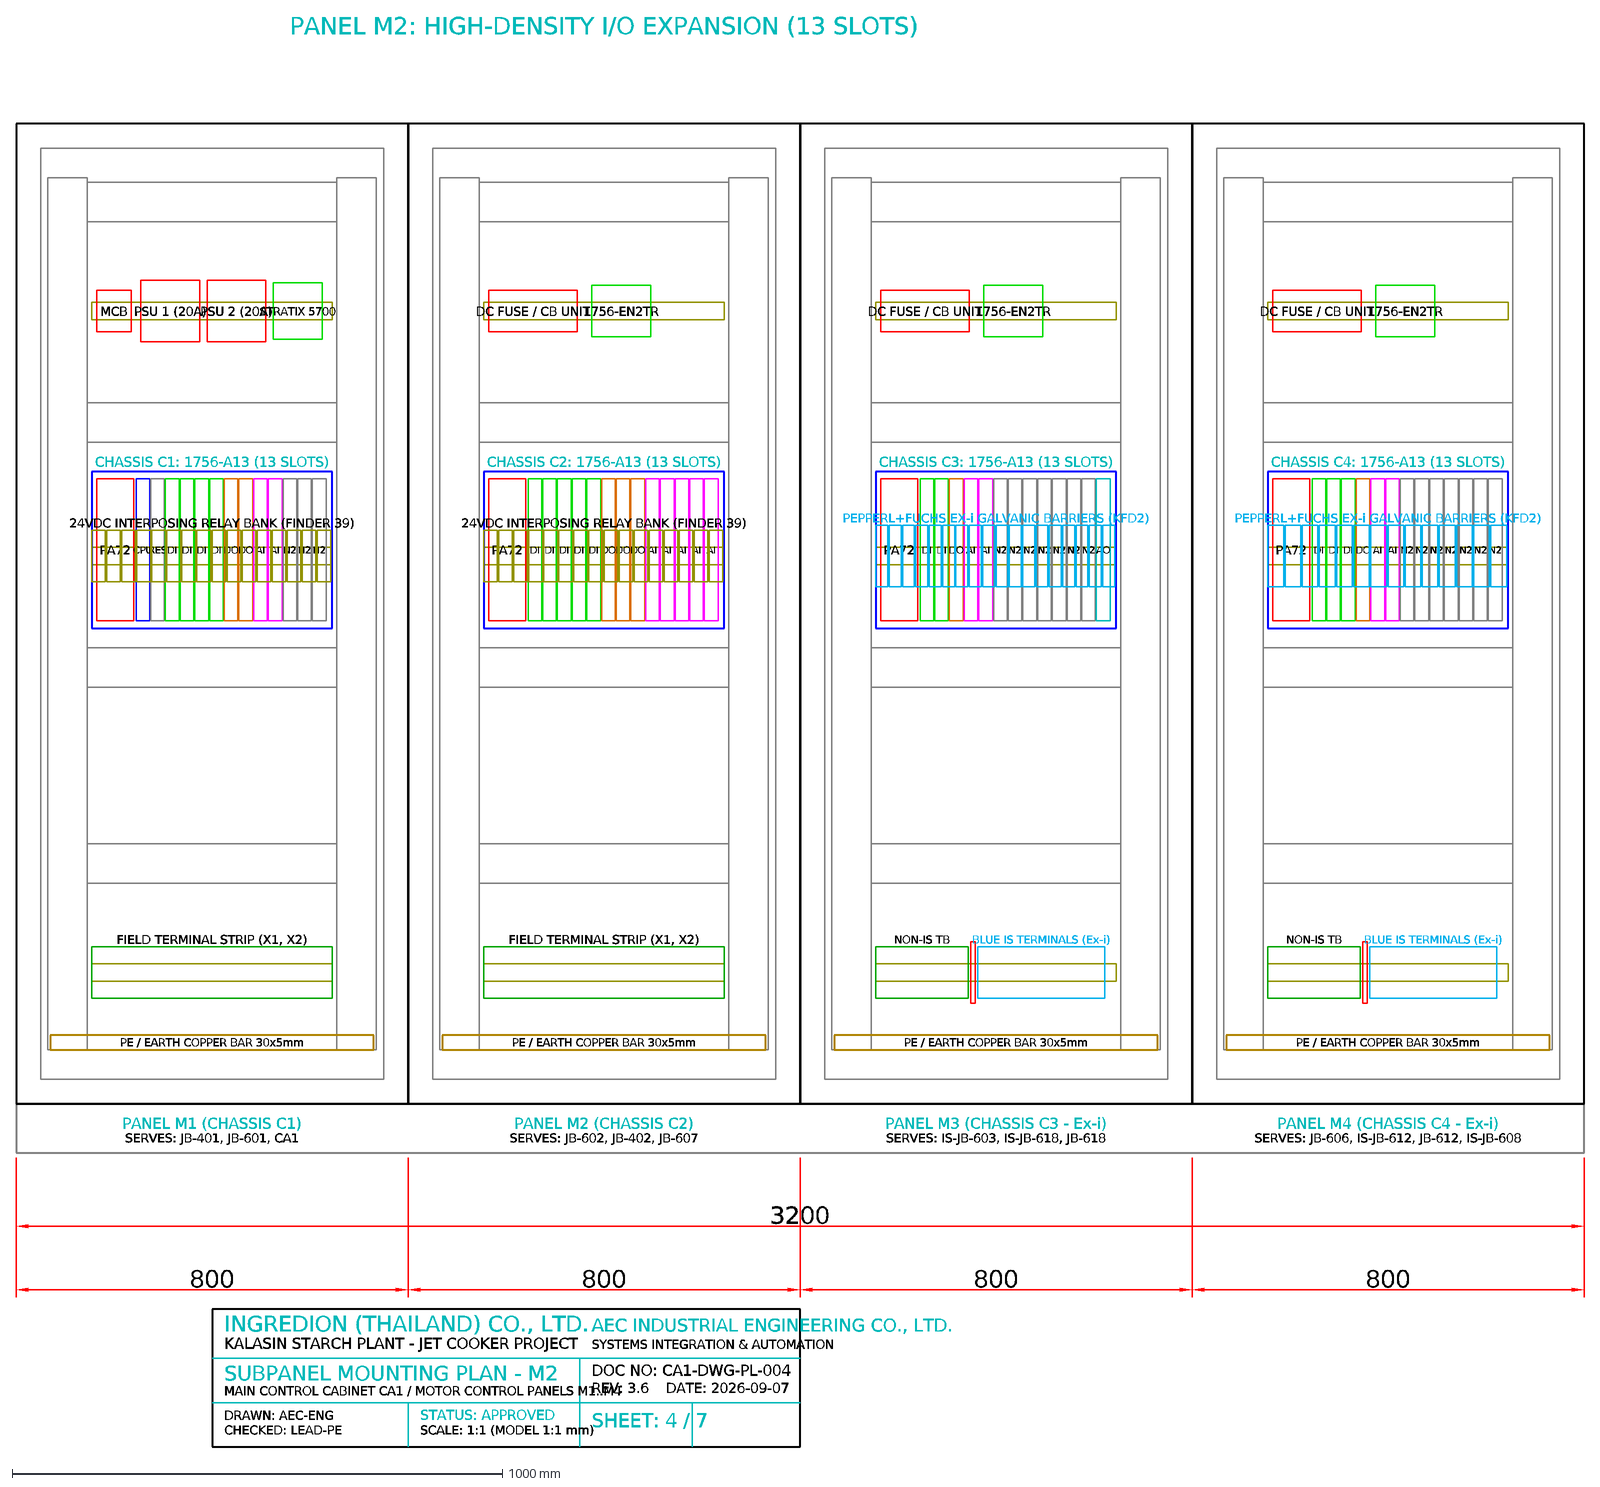
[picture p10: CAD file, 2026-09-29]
02_Electrical_and_eDrawing/03_CAD_Exports_DXF_SVG/03_MCC_Panel_Layout/MCC_Panel_Layout_Sheet4_Panel_M2.dxf
PE / EARTH COPPER BAR 30x5mm
MCB
PSU 1 (20A)
PSU 2 (20A)
STRATIX 5700
PA72
CPU
RES
DI
DO
AI
N2
CHASSIS C1: 1756-A13 (13 SLOTS)
24VDC INTERPOSING RELAY BANK (FINDER 39)
FIELD TERMINAL STRIP (X1, X2)
PANEL M1 (CHASSIS C1)
SERVES: JB-401, JB-601, CA1
DC FUSE / CB UNIT
1756-EN2TR
CHASSIS C2: 1756-A13 (13 SLOTS)
PANEL M2 (CHASSIS C2)
SERVES: JB-602, JB-402, JB-607
AO
CHASSIS C3: 1756-A13 (13 SLOTS)
PEPPERL+FUCHS EX-i GALVANIC BARRIERS (KFD2)
NON-IS TB
BLUE IS TERMINALS (Ex-i)
PANEL M3 (CHASSIS C3 - Ex-i)
SERVES: IS-JB-603, IS-JB-618, JB-618
CHASSIS C4: 1756-A13 (13 SLOTS)
PANEL M4 (CHASSIS C4 - Ex-i)
SERVES: JB-606, IS-JB-612, JB-612, IS-JB-608
3200
800
PANEL M2: HIGH-DENSITY I/O EXPANSION (13 SLOTS)
INGREDION (THAILAND) CO., LTD.
KALASIN STARCH PLANT - JET COOKER PROJECT
AEC INDUSTRIAL ENGINEERING CO., LTD.
SYSTEMS INTEGRATION & AUTOMATION
SUBPANEL MOUNTING PLAN - M2
MAIN CONTROL CABINET CA1 / MOTOR CONTROL PANELS M1..M4
DOC NO: CA1-DWG-PL-004
REV: 3.6 DATE: 2026-09-07
DRAWN: AEC-ENG
CHECKED: LEAD-PE
STATUS: APPROVED
SCALE: 1:1 (MODEL 1:1 mm)
SHEET: 4 / 7

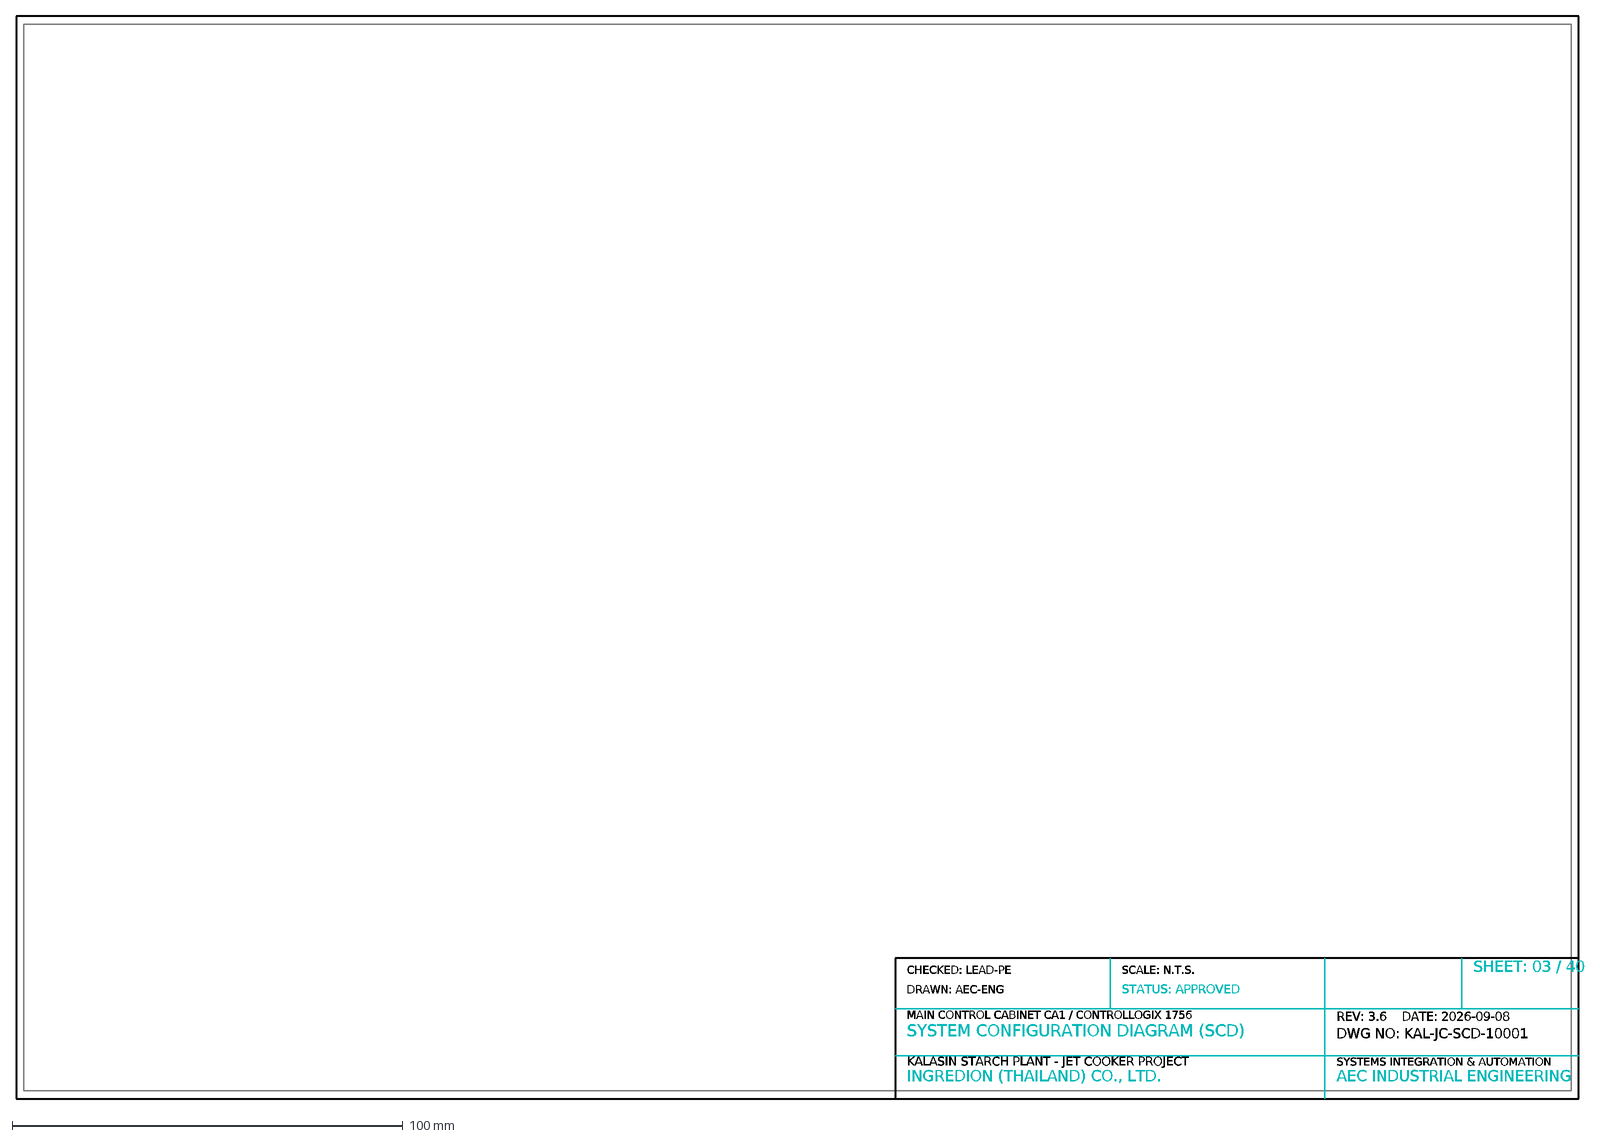
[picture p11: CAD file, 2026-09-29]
02_Electrical_and_eDrawing/03_CAD_Exports_DXF_SVG/04_System_Architecture_CAD/KAL-JC-SCD-10001_System_Configuration.dxf
INGREDION (THAILAND) CO., LTD.
KALASIN STARCH PLANT - JET COOKER PROJECT
AEC INDUSTRIAL ENGINEERING
SYSTEMS INTEGRATION & AUTOMATION
SYSTEM CONFIGURATION DIAGRAM (SCD)
MAIN CONTROL CABINET CA1 / CONTROLLOGIX 1756
DWG NO: KAL-JC-SCD-10001
REV: 3.6 DATE: 2026-09-08
DRAWN: AEC-ENG
CHECKED: LEAD-PE
STATUS: APPROVED
SCALE: N.T.S.
SHEET: 03 / 40

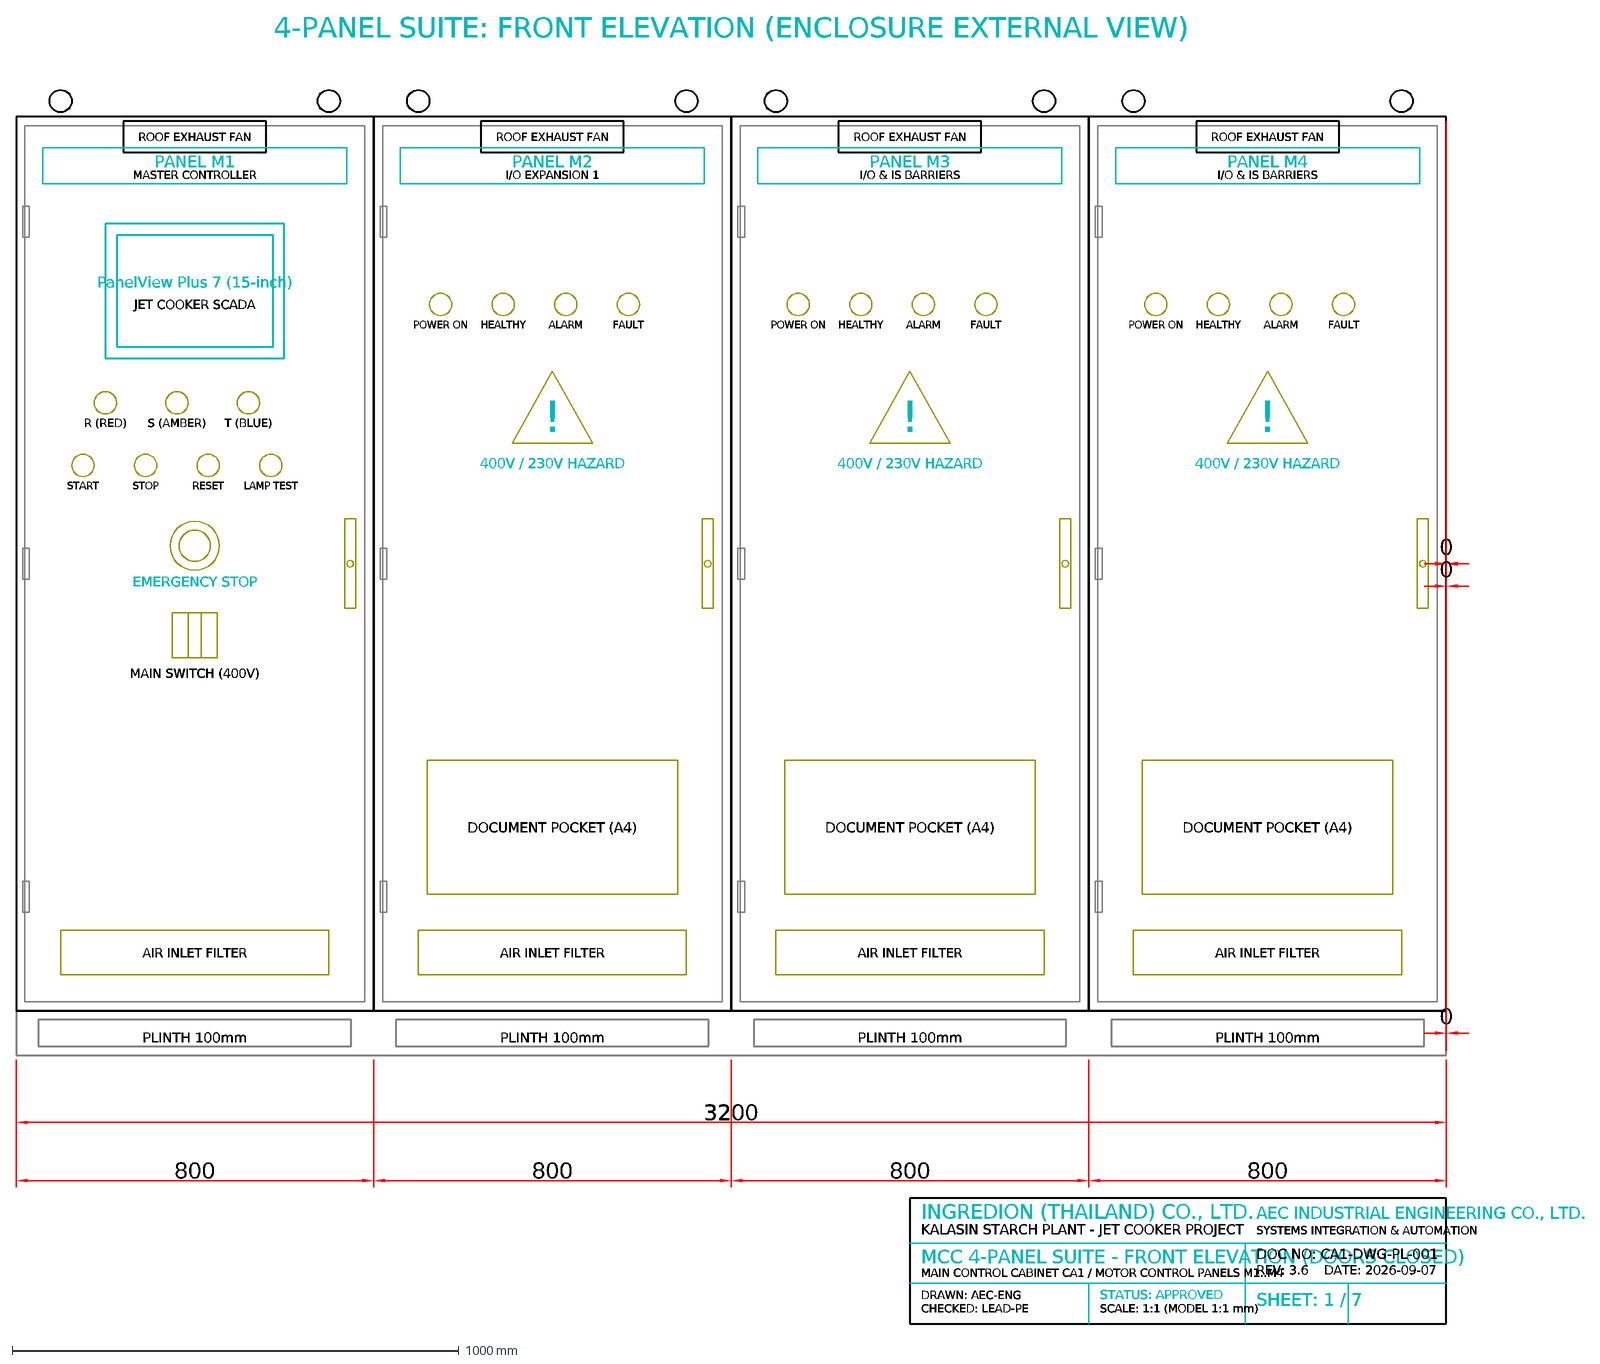
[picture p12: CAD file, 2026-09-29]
02_Electrical_and_eDrawing/04_PDF_Reports_and_Drawings/MCC_Panel_Layout_Sheet1_Front_Elevation.dxf
PLINTH 100mm
ROOF EXHAUST FAN
PANEL M1
MASTER CONTROLLER
AIR INLET FILTER
PanelView Plus 7 (15-inch)
JET COOKER SCADA
R (RED)
S (AMBER)
T (BLUE)
START
STOP
RESET
LAMP TEST
EMERGENCY STOP
MAIN SWITCH (400V)
PANEL M2
I/O EXPANSION 1
POWER ON
HEALTHY
ALARM
FAULT
!
400V / 230V HAZARD
DOCUMENT POCKET (A4)
PANEL M3
I/O & IS BARRIERS
PANEL M4
3200
800
0
4-PANEL SUITE: FRONT ELEVATION (ENCLOSURE EXTERNAL VIEW)
INGREDION (THAILAND) CO., LTD.
KALASIN STARCH PLANT - JET COOKER PROJECT
AEC INDUSTRIAL ENGINEERING CO., LTD.
SYSTEMS INTEGRATION & AUTOMATION
MCC 4-PANEL SUITE - FRONT ELEVATION (DOORS CLOSED)
MAIN CONTROL CABINET CA1 / MOTOR CONTROL PANELS M1..M4
DOC NO: CA1-DWG-PL-001
REV: 3.6 DATE: 2026-09-07
DRAWN: AEC-ENG
CHECKED: LEAD-PE
STATUS: APPROVED
SCALE: 1:1 (MODEL 1:1 mm)
SHEET: 1 / 7

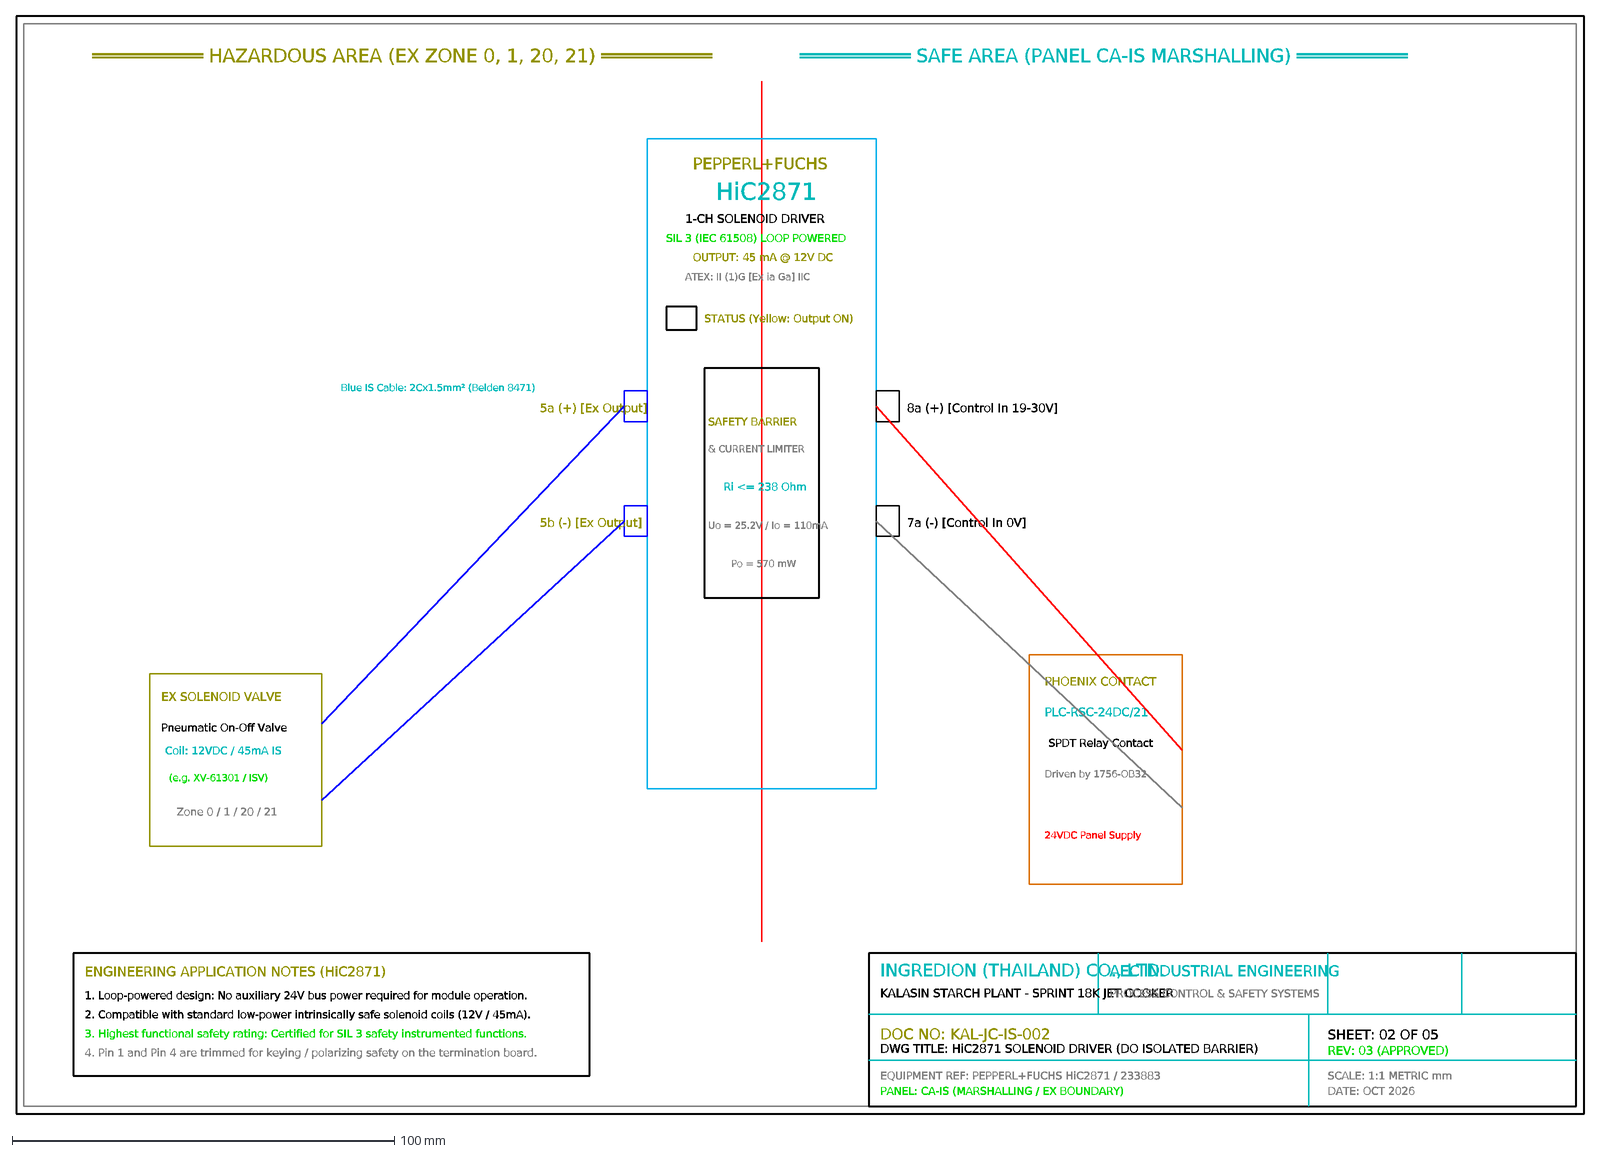
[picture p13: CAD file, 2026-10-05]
02_Electrical_and_eDrawing/05_Instrument_Manuals/Pepperl+Fuchs IS Barriers/KAL-JC-IS-002_HiC2871_Solenoid_Driver_DO.dxf
INGREDION (THAILAND) CO., LTD.
KALASIN STARCH PLANT - SPRINT 18K JET COOKER
AEC INDUSTRIAL ENGINEERING
PROCESS CONTROL & SAFETY SYSTEMS
DOC NO: KAL-JC-IS-002
DWG TITLE: HiC2871 SOLENOID DRIVER (DO ISOLATED BARRIER)
EQUIPMENT REF: PEPPERL+FUCHS HiC2871 / 233883
PANEL: CA-IS (MARSHALLING / EX BOUNDARY)
SHEET: 02 OF 05
REV: 03 (APPROVED)
SCALE: 1:1 METRIC mm
DATE: OCT 2026
══════════ HAZARDOUS AREA (EX ZONE 0, 1, 20, 21) ══════════
══════════ SAFE AREA (PANEL CA-IS MARSHALLING) ══════════
PEPPERL+FUCHS
HiC2871
1-CH SOLENOID DRIVER
SIL 3 (IEC 61508) LOOP POWERED
OUTPUT: 45 mA @ 12V DC
ATEX: II (1)G [Ex ia Ga] IIC
SAFETY BARRIER
& CURRENT LIMITER
Ri <= 238 Ohm
Uo = 25.2V / Io = 110mA
Po = 570 mW
STATUS (Yellow: Output ON)
5a (+) [Ex Output]
5b (-) [Ex Output]
8a (+) [Control In 19-30V]
7a (-) [Control In 0V]
EX SOLENOID VALVE
Pneumatic On-Off Valve
Coil: 12VDC / 45mA IS
(e.g. XV-61301 / ISV)
Zone 0 / 1 / 20 / 21
Blue IS Cable: 2Cx1.5mm² (Belden 8471)
PHOENIX CONTACT
PLC-RSC-24DC/21
SPDT Relay Contact
Driven by 1756-OB32
24VDC Panel Supply
ENGINEERING APPLICATION NOTES (HiC2871)
1. Loop-powered design: No auxiliary 24V bus power required for module operation.
2. Compatible with standard low-power intrinsically safe solenoid coils (12V / 45mA).
3. Highest functional safety rating: Certified for SIL 3 safety instrumented functions.
4. Pin 1 and Pin 4 are trimmed for keying / polarizing safety on the termination board.

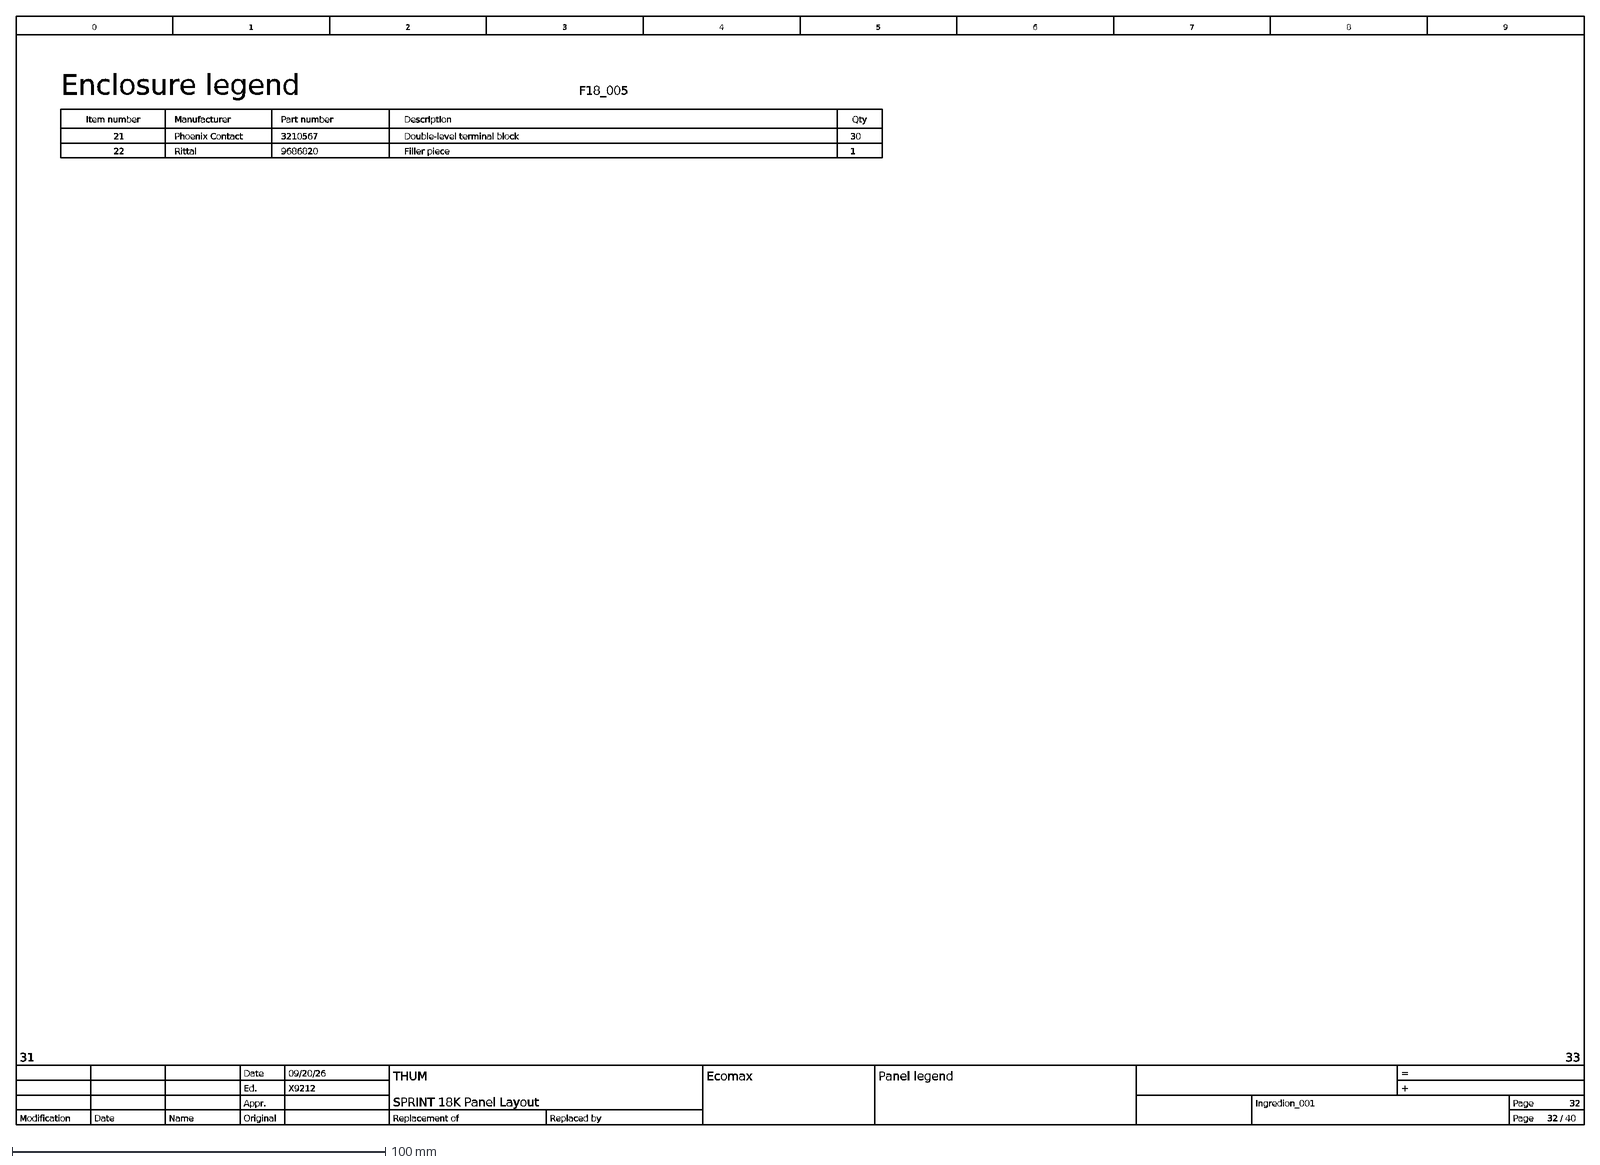
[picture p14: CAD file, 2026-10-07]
02_Electrical_and_eDrawing/ePlanExport/SPRINT 18K SPRAY DRYER/32.dxf
SPRINT 18K Panel Layout
31
Ingredion_001
THUM
X9212
Panel legend
1
0
7
6
8
9
3
40
33
4
09/20/26
Ecomax
32
2
5
Page
Ed.
Original
+
Date
Replaced by
Modification
Appr.
Replacement of
=
Name
/
Enclosure legend
F18_005
Part number
Manufacturer
Item number
Qty
Description
Phoenix Contact
3210567
21
30
Double-level terminal block
Rittal
9686820
22
Filler piece

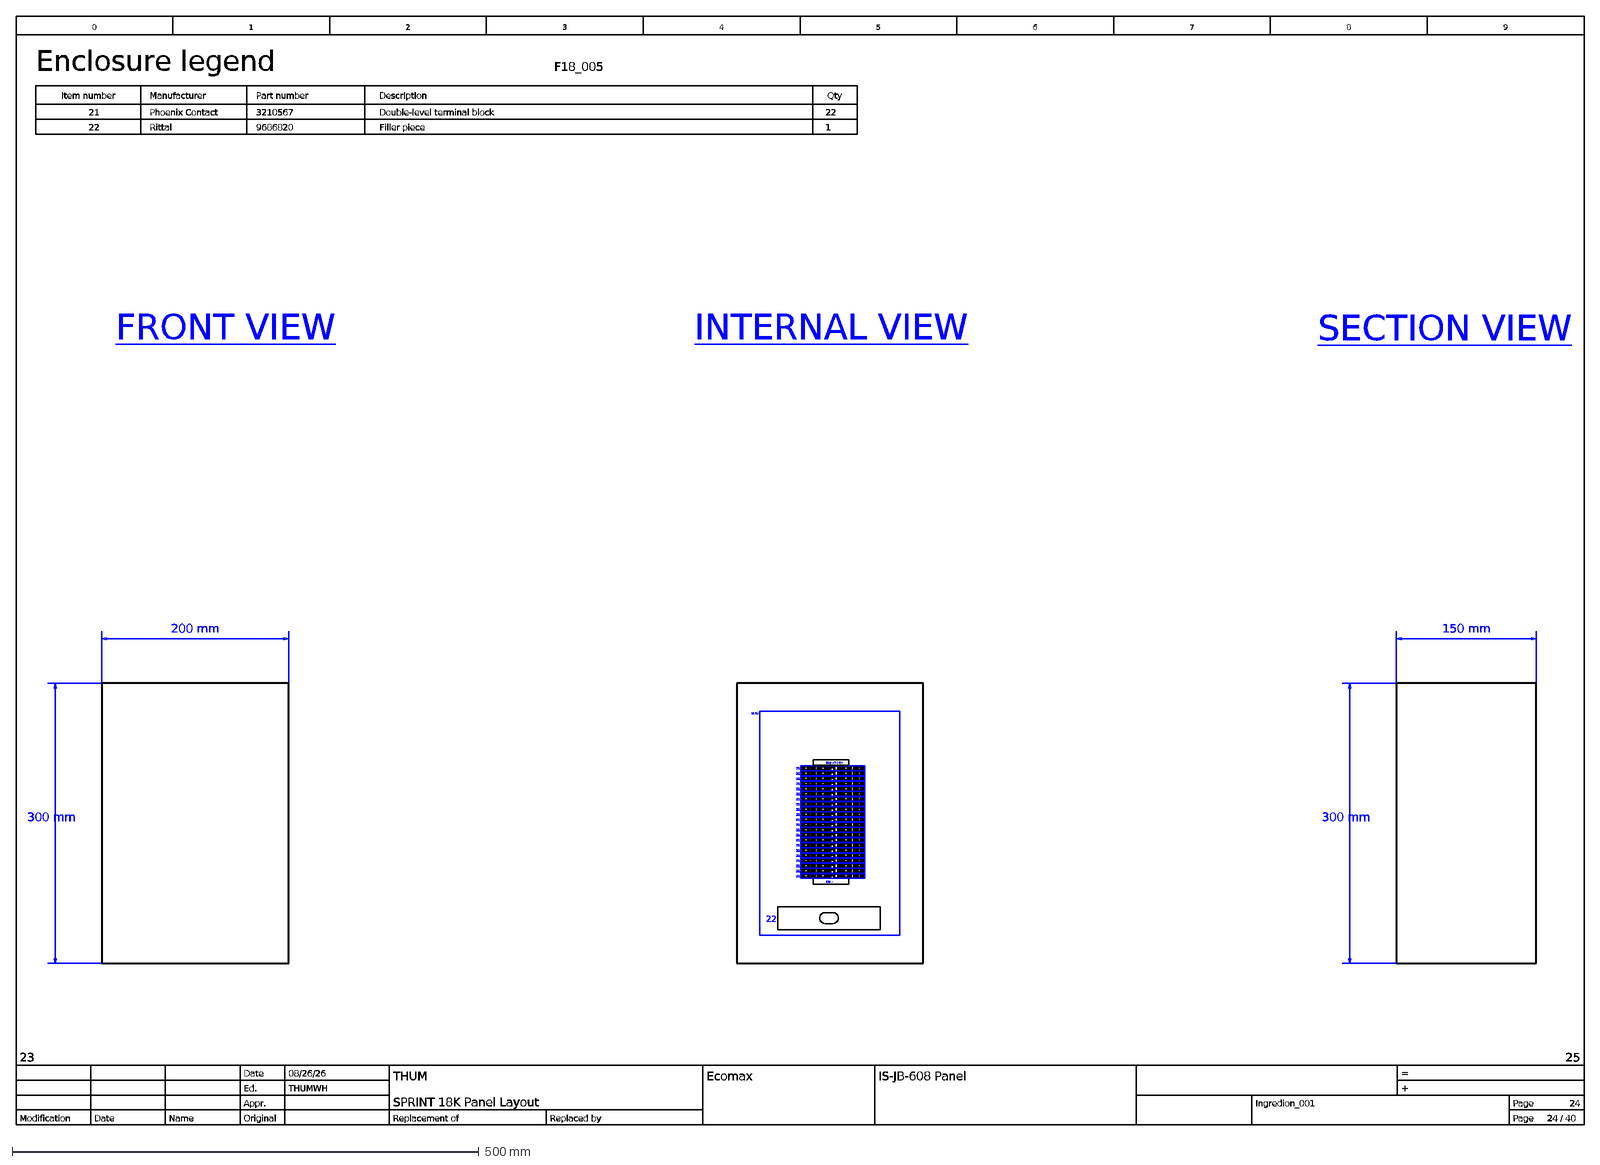
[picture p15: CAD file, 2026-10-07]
02_Electrical_and_eDrawing/Panel_Layout/Sheet_24_IS-JB-608_Panel_Layout.dxf
SPRINT 18K Panel Layout
23
Ingredion_001
THUM
THUMWH
IS-JB-608 Panel
1
0
7
6
8
9
3
40
25
4
08/26/26
Ecomax
24
2
5
Page
Ed.
Original
+
Date
Replaced by
Modification
Appr.
Replacement of
=
Name
/
Enclosure legend
F18_005
Part number
Manufacturer
Item number
Qty
Description
Phoenix Contact
3210567
21
22
Double-level terminal block
Rittal
9686820
Filler piece
END
FRONT VIEW
INTERNAL VIEW
SECTION VIEW
200 mm
300 mm
150 mm
IS-JB-608TB
M.29

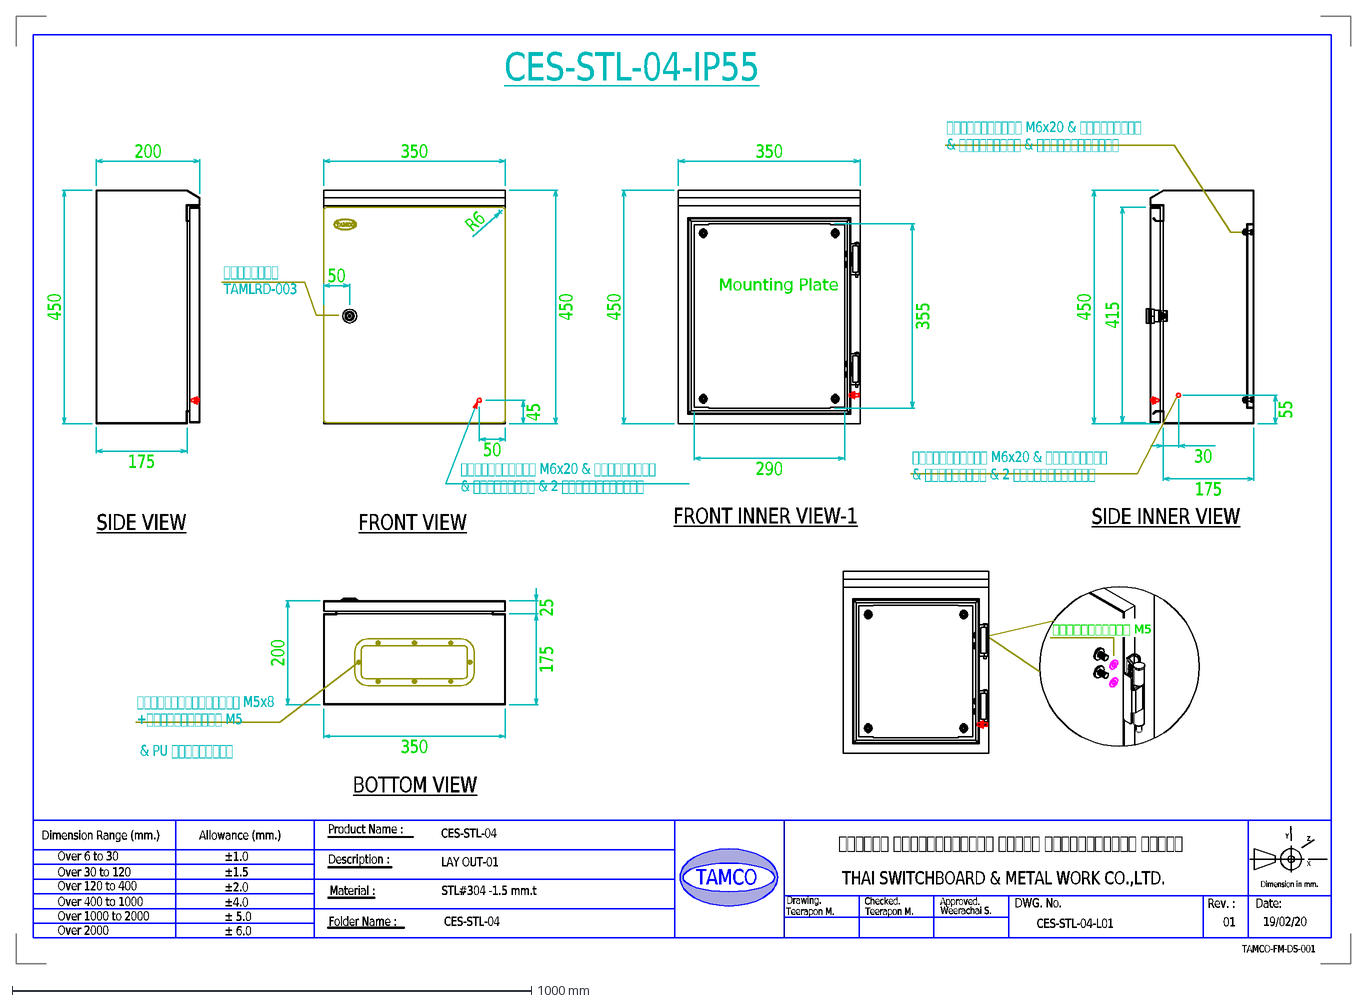
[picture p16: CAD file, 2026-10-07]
02_Electrical_and_eDrawing/Panel_Layout/TAMCO_CES_Stainless_Series/Drawings_DXF/CES-STL-04-Layout.dxf
DWG. No.
THAI SWITCHBOARD & METAL WORK CO.,LTD.
Checked.
Approved.
Date:
Drawing.
Product Name :
Description :
Material :
Folder Name :
Rev. :
TAMCO-FM-DS-001
CES-STL-04
Weerachai S.
LAY OUT-01
Dimension Range (mm.)
Over 6 to 30
Over 30 to 120
Over 120 to 400
Over 400 to 1000
Over 1000 to 2000
Over 2000
Allowance (mm.)
±1.5
±1.0
±2.0
±4.0
± 5.0
± 6.0
TAMCO
Teerapon M.
Z
X
Y
Dimension in mm.
19/02/20
01
CES-STL-04-L01
STL#304 -1.5 mm.t
CES-STL-04-IP55
450
200
175
25
350
415
SIDE VIEW
FRONT VIEW
FRONT INNER VIEW-1
SIDE INNER VIEW
BOTTOM VIEW
55
30
50
Mounting Plate
290
355
R6
45

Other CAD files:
01_Network_Design/05_Drawings_and_Schematics/#SPRINT_18K_Control_Layout_System_Architecture.dxf
02_Electrical_and_eDrawing/01_Source_Drawings_DWG/R5THS00138-FBR-WIR-20001_3.dwg
02_Electrical_and_eDrawing/02_ePlan_Exports/SPRINT 18K SPRAY DRYER ELECTRICAL/38.dxf
02_Electrical_and_eDrawing/03_CAD_Exports_DXF_SVG/DI_Slot_Drawings/C3S3_DI_Wiring_Diagram.dxf
02_Electrical_and_eDrawing/03_CAD_Exports_DXF_SVG/DO_Slot_Drawings/C4S4_DO_Wiring_Diagram.dxf
02_Electrical_and_eDrawing/03_CAD_Exports_DXF_SVG/IS_Barriers_CAD/C4S1-IB32-HiC2821_IS_Wiring_Diagram.dxf
02_Electrical_and_eDrawing/ePlanExport/SPRINT 18K SPRAY DRYER ELECTRICAL/36.dxf
01_Network_Design/05_Drawings_and_Schematics/SPRINT_18K_Control_Layout_System_Architecture.dxf
02_Electrical_and_eDrawing/01_Source_Drawings_DWG/R5THS00138-000-SCD-10001_0.dwg
02_Electrical_and_eDrawing/01_Source_Drawings_DWG/R5THS00138-FBR-LAY-20001_1.dwg
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

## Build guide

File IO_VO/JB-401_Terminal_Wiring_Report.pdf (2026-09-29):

INGREDION (THAILAND) CO., LTD. | PROJECT JET COOKER | AEC INDUSTRIAL ENGINEERING | REV. 3.6
ENCLOSURE: JB-401 | TYPE: Field Junction Box (Standard) | LOCATION: Infeed 2nd Floor | SIZE: 800-600-250 mm
SUMMARY: Total Channels: 112 | Active: 85 | Spare: 27 (24.1%) | DI: 64 | DO: 32 | AI: 16 | AO: 0 | BUS: 0
No. | Terminal | Rack/Slot | Channel | I/O Module | Type Signal Characteristic Instrument Tag | | | PLC Tag Name | P&ID No. | Service / Equipment Description | Zone / Floor
1 | C1S03-X2 | C1/S3 | C1S03,16 | 1756-IB32-16 | DI | Dry Contact | FSL-40201 | FSL-40201_DI_1 | 3-25-01-402-PD-01 | Flow Switch | PH Adjustment / ...
2 | C1S03-X2 | C1/S3 | C1S03,17 | 1756-IB32-17 | DI | Dry Contact | FSL-40202 | FSL-40202_DI_1 | 3-25-01-402-PD-01 | Flow Switch | PH Adjustment / ...
3 | C1S09-X1 | C1/S9 | C1S09,00 | 1756-IF16-0 | AI | 4 - 20 mA,Pulse | FT-40201 | FT-40201_AI_1 | 3-25-01-402-PD-02 | Coriolis Flow Transmitter | Infeed Tank / 1st
4 | C1S09-X1 | C1/S9 | C1S09,01 | 1756-IF16-1 | AI | 4 - 20 mA,Pulse | FT-40201 | FT-40201_AI_2 | 3-25-01-402-PD-02 | Coriolis Flow Transmitter | Infeed Tank / 1st
5 | C1S03-X2 | C1/S3 | C1S03,18 | 1756-IB32-18 | DI | 4 - 20 mA,Pulse | FT-40201 | FT-40201_DI_1 | 3-25-01-402-PD-02 | Coriolis Flow Transmitter | Infeed Tank / 1st
6 | C1S09-X1 | C1/S9 | C1S09,02 | 1756-IF16-2 | AI | 4 - 20 mA,Pulse | FT-40202 | FT-40202_AI_1 | 3-25-01-402-PD-02 | Magnetic Flow Transmitter | Infeed Tank / 1st
7 | C1S03-X2 | C1/S3 | C1S03,19 | 1756-IB32-19 | DI | 4 - 20 mA,Pulse | FT-40202 | FT-40202_DI_1 | 3-25-01-402-PD-02 | Magnetic Flow Transmitter | Infeed Tank / 1st
8 | C1S03-X2 | C1/S3 | C1S03,20 | 1756-IB32-20 | DI | Dry Contact | HV-40201 | HV-40201_DI_1 | 3-25-01-402-PD-01 | Manual Valve With Position Switch | PH Adjustment / ...
9 | C1S03-X2 | C1/S3 | C1S03,21 | 1756-IB32-21 | DI | Dry Contact | HV-40202 | HV-40202_DI_1 | 3-25-01-402-PD-01 | Manual Valve With Position Switch | PH Adjustment / ...
10 | C1S03-X2 | C1/S3 | C1S03,22 | 1756-IB32-22 | DI | Dry Contact | HV-40203 | HV-40203_DI_1 | 3-25-01-402-PD-01 | Manual Valve With Position Switch | PH Adjustment / ...
11 | C1S03-X2 | C1/S3 | C1S03,23 | 1756-IB32-23 | DI | Dry Contact | HV-40204 | HV-40204_DI_1 | 3-25-01-402-PD-01 | Manual Valve With Position Switch | PH Adjustment / ...
12 | C1S03-X2 | C1/S3 | C1S03,24 | 1756-IB32-24 | DI | Dry Contact | HV-40205 | HV-40205_DI_1 | 3-25-01-402-PD-02 | Manual Valve With Position Switch | Infeed Tank / 1st
13 | C1S03-X2 | C1/S3 | C1S03,25 | 1756-IB32-25 | DI | Dry Contact | HV-40206 | HV-40206_DI_1 | 3-25-01-402-PD-02 | Manual Valve With Position Switch | Infeed Tank / 1st
14 | C1S09-X1 | C1/S9 | C1S09,04 | 1756-IF16-4 | AI | 4 - 20 mA | LT-40201 | LT-40201_AI_1 | 3-25-01-402-PD-01 | Level Transmitter | PH Adjustment / ...
15 | C1S09-X1 | C1/S9 | C1S09,05 | 1756-IF16-5 | AI | 4 - 20 mA | LT-40202 | LT-40202_AI_1 | 3-25-01-402-PD-01 | Level Transmitter | PH Adjustment / ...
16 | C1S09-X1 | C1/S9 | C1S09,03 | 1756-IF16-3 | AI | 4 - 20 mA | LT-40203 | LT-40203_AI_1 | 3-25-01-402-PD-02 | Level Transmitter | Infeed Tank / 1st
17 | C1S09-X1 | C1/S9 | C1S09,06 | 1756-IF16-6 | AI | 4 - 20 mA | pHT-40201 | pHT-40201_AI_1 | 3-25-01-402-PD-01 | PH Transmitter | PH Adjustment / ...
18 | C1S09-X1 | C1/S9 | C1S09,07 | 1756-IF16-7 | AI | 4 - 20 mA | pHT-40202 | pHT-40202_AI_1 | 3-25-01-402-PD-01 | PH Transmitter | PH Adjustment / ...
19 | C1S09-X1 | C1/S9 | C1S09,08 | 1756-IF16-8 | AI | 4 - 20 mA | PT-40201 | PT-40201_AI_1 | 3-25-01-402-PD-02 | Pressure Transmitter | Infeed Tank / 1st
20 | C1S09-X1 | C1/S9 | C1S09,09 | 1756-IF16-9 | AI | 4 - 20 mA | PT-40202 | PT-40202_AI_1 | 3-25-01-402-PD-02 | Pressure Transmitter | Infeed Tank / 1st
21 | C1S09-X1 | C1/S9 | C1S09,10 | 1756-IF16-10 | AI | 4 - 20 mA | PT-60202 | PT-60202_AI_1 | 3-25-01-602-PD-01 | Pressure Transmitter | Infeed Tank / 1st
22 | C1S09-X1 | C1/S9 | C1S09,11 | 1756-IF16-11 | AI | - | Spare | Spare_AI_0 | - | Spare I/O Point | -
23 | C1S09-X1 | C1/S9 | C1S09,12 | 1756-IF16-12 | AI | - | Spare | Spare_AI_0 | - | Spare I/O Point | -
24 | C1S09-X1 | C1/S9 | C1S09,13 | 1756-IF16-13 | AI | - | Spare | Spare_AI_0 | - | Spare I/O Point | -
25 | C1S09-X1 | C1/S9 | C1S09,14 | 1756-IF16-14 | AI | - | Spare | Spare_AI_0 | - | Spare I/O Point | -
26 | C1S09-X1 | C1/S9 | C1S09,15 | 1756-IF16-15 | AI | - | Spare | Spare_AI_0 | - | Spare I/O Point | -
27 | C1S05-X1 | C1/S5 | C1S05,02 | 1756-IB32-2 | DI | - | Spare | Spare_DI_0 | - | Spare I/O Point | -
28 | C1S05-X1 | C1/S5 | C1S05,03 | 1756-IB32-3 | DI | - | Spare | Spare_DI_0 | - | Spare I/O Point | -
29 | C1S05-X1 | C1/S5 | C1S05,04 | 1756-IB32-4 | DI | - | Spare | Spare_DI_0 | - | Spare I/O Point | -
30 | C1S05-X1 | C1/S5 | C1S05,05 | 1756-IB32-5 | DI | - | Spare | Spare_DI_0 | - | Spare I/O Point | -
31 | C1S05-X1 | C1/S5 | C1S05,06 | 1756-IB32-6 | DI | - | Spare | Spare_DI_0 | - | Spare I/O Point | -
Doc No.: Instrument I/O List (Kalasin) - JB-401 | Page 1 of 4 | CONFIDENTIAL | Generated: 2026-09-07

ENCLOSURE: JB-401 | TYPE: Field Junction Box (Standard) | LOCATION: Infeed 2nd Floor | SIZE: 800-600-250 mm
SUMMARY: Total Channels: 112 | Active: 85 | Spare: 27 (24.1%) | DI: 64 | DO: 32 | AI: 16 | AO: 0 | BUS: 0
No. | Terminal | Rack/Slot | Channel | I/O Module | Type Signal Characteristic Instrument Tag | | | PLC Tag Name | P&ID No. | Service / Equipment Description | Zone / Floor
32 | C1S05-X1 | C1/S5 | C1S05,07 | 1756-IB32-7 | DI | - | Spare | Spare_DI_0 | - | Spare I/O Point | -
33 | C1S05-X1 | C1/S5 | C1S05,08 | 1756-IB32-8 | DI | - | Spare | Spare_DI_0 | - | Spare I/O Point | -
34 | C1S05-X1 | C1/S5 | C1S05,09 | 1756-IB32-9 | DI | - | Spare | Spare_DI_0 | - | Spare I/O Point | -
35 | C1S05-X1 | C1/S5 | C1S05,10 | 1756-IB32-10 | DI | - | Spare | Spare_DI_0 | - | Spare I/O Point | -
36 | C1S05-X1 | C1/S5 | C1S05,11 | 1756-IB32-11 | DI | - | Spare | Spare_DI_0 | - | Spare I/O Point | -
37 | C1S05-X1 | C1/S5 | C1S05,12 | 1756-IB32-12 | DI | - | Spare | Spare_DI_0 | - | Spare I/O Point | -
38 | C1S05-X1 | C1/S5 | C1S05,13 | 1756-IB32-13 | DI | - | Spare | Spare_DI_0 | - | Spare I/O Point | -
39 | C1S05-X1 | C1/S5 | C1S05,14 | 1756-IB32-14 | DI | - | Spare | Spare_DI_0 | - | Spare I/O Point | -
40 | C1S05-X1 | C1/S5 | C1S05,15 | 1756-IB32-15 | DI | - | Spare | Spare_DI_0 | - | Spare I/O Point | -
41 | C1S08-X1 | C1/S8 | C1S08,08 | 1756-OB32-8 | DO | - | Spare | Spare_DO_0 | - | Spare I/O Point | -
42 | C1S08-X1 | C1/S8 | C1S08,09 | 1756-OB32-9 | DO | - | Spare | Spare_DO_0 | - | Spare I/O Point | -
43 | C1S08-X1 | C1/S8 | C1S08,10 | 1756-OB32-10 | DO | - | Spare | Spare_DO_0 | - | Spare I/O Point | -
44 | C1S08-X1 | C1/S8 | C1S08,11 | 1756-OB32-11 | DO | - | Spare | Spare_DO_0 | - | Spare I/O Point | -
45 | C1S08-X1 | C1/S8 | C1S08,12 | 1756-OB32-12 | DO | - | Spare | Spare_DO_0 | - | Spare I/O Point | -
46 | C1S08-X1 | C1/S8 | C1S08,13 | 1756-OB32-13 | DO | - | Spare | Spare_DO_0 | - | Spare I/O Point | -
47 | C1S08-X1 | C1/S8 | C1S08,14 | 1756-OB32-14 | DO | - | Spare | Spare_DO_0 | - | Spare I/O Point | -
48 | C1S08-X1 | C1/S8 | C1S08,15 | 1756-OB32-15 | DO | - | Spare | Spare_DO_0 | - | Spare I/O Point | -
49 | C1S07-X2 | C1/S7 | C1S07,24 | 1756-OB32-24 | DO | 24 VDC energized | SV-40201 | SV-40201_DO_1 | 3-25-01-402-PD-01 | 0 | PH Adjustment / ...
50 | C1S07-X2 | C1/S7 | C1S07,25 | 1756-OB32-25 | DO | 24 VDC energized | SV-40202 | SV-40202_DO_1 | 3-25-01-402-PD-01 | 0 | PH Adjustment / ...
51 | C1S07-X2 | C1/S7 | C1S07,26 | 1756-OB32-26 | DO | 24 VDC energized | SV-40203 | SV-40203_DO_1 | 3-25-01-402-PD-01 | 0 | PH Adjustment / ...
52 | C1S07-X2 | C1/S7 | C1S07,27 | 1756-OB32-27 | DO | 24 VDC energized | SV-40204 | SV-40204_DO_1 | 3-25-01-402-PD-01 | 0 | PH Adjustment / ...
53 | C1S03-X2 | C1/S3 | C1S03,26 | 1756-IB32-26 | DI | 24 VDC energized | XV-40201A | XV-40201A_DI_1 | 3-25-01-402-PD-01 | 0 | PH Adjustment / ...
54 | C1S03-X2 | C1/S3 | C1S03,27 | 1756-IB32-27 | DI | 24 VDC energized | XV-40201A | XV-40201A_DI_2 | 3-25-01-402-PD-01 | 0 | PH Adjustment / ...
55 | C1S07-X2 | C1/S7 | C1S07,28 | 1756-OB32-28 | DO | 24 VDC energized | XV-40201A | XV-40201A_DO_1 | 3-25-01-402-PD-01 | 0 | PH Adjustment / ...
56 | C1S03-X2 | C1/S3 | C1S03,28 | 1756-IB32-28 | DI | 24 VDC energized | XV-40201B | XV-40201B_DI_1 | 3-25-01-402-PD-01 | 0 | PH Adjustment / ...
57 | C1S03-X2 | C1/S3 | C1S03,29 | 1756-IB32-29 | DI | 24 VDC energized | XV-40201B | XV-40201B_DI_2 | 3-25-01-402-PD-01 | 0 | PH Adjustment / ...
58 | C1S07-X2 | C1/S7 | C1S07,29 | 1756-OB32-29 | DO | 24 VDC energized | XV-40201B | XV-40201B_DO_1 | 3-25-01-402-PD-01 | 0 | PH Adjustment / ...
59 | C1S03-X2 | C1/S3 | C1S03,30 | 1756-IB32-30 | DI | 24 VDC energized | XV-40201C | XV-40201C_DI_1 | 3-25-01-402-PD-01 | 0 | PH Adjustment / ...
60 | C1S03-X2 | C1/S3 | C1S03,31 | 1756-IB32-31 | DI | 24 VDC energized | XV-40201C | XV-40201C_DI_2 | 3-25-01-402-PD-01 | 0 | PH Adjustment / ...
61 | C1S07-X2 | C1/S7 | C1S07,30 | 1756-OB32-30 | DO | 24 VDC energized | XV-40201C | XV-40201C_DO_1 | 3-25-01-402-PD-01 | 0 | PH Adjustment / ...
62 | C1S04-X1 | C1/S4 | C1S04,00 | 1756-IB32-0 | DI | 24 VDC energized | XV-40201D | XV-40201D_DI_1 | 3-25-01-402-PD-01 | 0 | PH Adjustment / ...
Doc No.: Instrument I/O List (Kalasin) - JB-401 | Page 2 of 4 | CONFIDENTIAL | Generated: 2026-09-07

ENCLOSURE: JB-401 | TYPE: Field Junction Box (Standard) | LOCATION: Infeed 2nd Floor | SIZE: 800-600-250 mm
SUMMARY: Total Channels: 112 | Active: 85 | Spare: 27 (24.1%) | DI: 64 | DO: 32 | AI: 16 | AO: 0 | BUS: 0
No. | Terminal | Rack/Slot | Channel | I/O Module | Type Signal Characteristic Instrument Tag | | | PLC Tag Name | P&ID No. | Service / Equipment Description | Zone / Floor
63 | C1S04-X1 | C1/S4 | C1S04,01 | 1756-IB32-1 | DI | 24 VDC energized | XV-40201D | XV-40201D_DI_2 | 3-25-01-402-PD-01 | 0 | PH Adjustment / ...
64 | C1S07-X2 | C1/S7 | C1S07,31 | 1756-OB32-31 | DO | 24 VDC energized | XV-40201D | XV-40201D_DO_1 | 3-25-01-402-PD-01 | 0 | PH Adjustment / ...
65 | C1S04-X1 | C1/S4 | C1S04,02 | 1756-IB32-2 | DI | 24 VDC energized | XV-40201E | XV-40201E_DI_1 | 3-25-01-402-PD-01 | 0 | PH Adjustment / ...
66 | C1S04-X1 | C1/S4 | C1S04,03 | 1756-IB32-3 | DI | 24 VDC energized | XV-40201E | XV-40201E_DI_2 | 3-25-01-402-PD-01 | 0 | PH Adjustment / ...
67 | C1S08-X1 | C1/S8 | C1S08,00 | 1756-OB32-0 | DO | 24 VDC energized | XV-40201E | XV-40201E_DO_1 | 3-25-01-402-PD-01 | 0 | PH Adjustment / ...
68 | C1S04-X1 | C1/S4 | C1S04,04 | 1756-IB32-4 | DI | 24 VDC energized | XV-40201F | XV-40201F_DI_1 | 3-25-01-402-PD-01 | 0 | PH Adjustment / ...
69 | C1S04-X1 | C1/S4 | C1S04,05 | 1756-IB32-5 | DI | 24 VDC energized | XV-40201F | XV-40201F_DI_2 | 3-25-01-402-PD-01 | 0 | PH Adjustment / ...
70 | C1S08-X1 | C1/S8 | C1S08,01 | 1756-OB32-1 | DO | 24 VDC energized | XV-40201F | XV-40201F_DO_1 | 3-25-01-402-PD-01 | 0 | PH Adjustment / ...
71 | C1S04-X1 | C1/S4 | C1S04,06 | 1756-IB32-6 | DI | 24 VDC energized | XV-40201G | XV-40201G_DI_1 | 3-25-01-402-PD-01 | 0 | PH Adjustment / ...
72 | C1S04-X1 | C1/S4 | C1S04,07 | 1756-IB32-7 | DI | 24 VDC energized | XV-40201G | XV-40201G_DI_2 | 3-25-01-402-PD-01 | 0 | PH Adjustment / ...
73 | C1S08-X1 | C1/S8 | C1S08,02 | 1756-OB32-2 | DO | 24 VDC energized | XV-40201G | XV-40201G_DO_1 | 3-25-01-402-PD-01 | 0 | PH Adjustment / ...
74 | C1S04-X1 | C1/S4 | C1S04,08 | 1756-IB32-8 | DI | 24 VDC energized | XV-40201H | XV-40201H_DI_1 | 3-25-01-402-PD-01 | 0 | PH Adjustment / ...
75 | C1S04-X1 | C1/S4 | C1S04,09 | 1756-IB32-9 | DI | 24 VDC energized | XV-40201H | XV-40201H_DI_2 | 3-25-01-402-PD-01 | 0 | PH Adjustment / ...
76 | C1S08-X1 | C1/S8 | C1S08,03 | 1756-OB32-3 | DO | 24 VDC energized | XV-40201H | XV-40201H_DO_1 | 3-25-01-402-PD-01 | 0 | PH Adjustment / ...
77 | C1S04-X2 | C1/S4 | C1S04,19 | 1756-IB32-19 | DI | 24 VDC energized | XV-40202A | XV-40202A_DI_1 | 3-25-01-402-PD-01 | 0 | PH Adjustment / ...
78 | C1S04-X1 | C1/S4 | C1S04,11 | 1756-IB32-11 | DI | 24 VDC energized | XV-40202A | XV-40202A_DI_2 | 3-25-01-402-PD-01 | 0 | PH Adjustment / ...
79 | C1S08-X1 | C1/S8 | C1S08,04 | 1756-OB32-4 | DO | 24 VDC energized | XV-40202A | XV-40202A_DO_1 | 3-25-01-402-PD-01 | 0 | PH Adjustment / ...
80 | C1S04-X1 | C1/S4 | C1S04,12 | 1756-IB32-12 | DI | 24 VDC energized | XV-40202B | XV-40202B_DI_1 | 3-25-01-402-PD-01 | 0 | PH Adjustment / ...
81 | C1S04-X1 | C1/S4 | C1S04,13 | 1756-IB32-13 | DI | 24 VDC energized | XV-40202B | XV-40202B_DI_2 | 3-25-01-402-PD-01 | 0 | PH Adjustment / ...
82 | C1S08-X1 | C1/S8 | C1S08,05 | 1756-OB32-5 | DO | 24 VDC energized | XV-40202B | XV-40202B_DO_1 | 3-25-01-402-PD-01 | 0 | PH Adjustment / ...
83 | C1S04-X1 | C1/S4 | C1S04,14 | 1756-IB32-14 | DI | 24 VDC energized | XV-40202C | XV-40202C_DI_1 | 3-25-01-402-PD-01 | 0 | PH Adjustment / ...
84 | C1S04-X1 | C1/S4 | C1S04,15 | 1756-IB32-15 | DI | 24 VDC energized | XV-40202C | XV-40202C_DI_2 | 3-25-01-402-PD-01 | 0 | PH Adjustment / ...
85 | C1S08-X1 | C1/S8 | C1S08,06 | 1756-OB32-6 | DO | 24 VDC energized | XV-40202C | XV-40202C_DO_1 | 3-25-01-402-PD-01 | 0 | PH Adjustment / ...
86 | C1S04-X2 | C1/S4 | C1S04,16 | 1756-IB32-16 | DI | 24 VDC energized | XV-40202D | XV-40202D_DI_1 | 3-25-01-402-PD-01 | 0 | PH Adjustment / ...
87 | C1S04-X2 | C1/S4 | C1S04,17 | 1756-IB32-17 | DI | 24 VDC energized | XV-40202D | XV-40202D_DI_2 | 3-25-01-402-PD-01 | 0 | PH Adjustment / ...
88 | C1S08-X1 | C1/S8 | C1S08,07 | 1756-OB32-7 | DO | 24 VDC energized | XV-40202D | XV-40202D_DO_1 | 3-25-01-402-PD-01 | 0 | PH Adjustment / ...
89 | C1S04-X2 | C1/S4 | C1S04,18 | 1756-IB32-18 | DI | 24 VDC energized | XV-40202E | XV-40202E_DI_1 | 3-25-01-402-PD-01 | 0 | PH Adjustment / ...
90 | C1S04-X2 | C1/S4 | C1S04,19 | 1756-IB32-19 | DI | 24 VDC energized | XV-40202E | XV-40202E_DI_2 | 3-25-01-402-PD-01 | 0 | PH Adjustment / ...
91 | C1S07-X2 | C1/S7 | C1S07,16 | 1756-OB32-16 | DO | 24 VDC energized | XV-40202E | XV-40202E_DO_1 | 3-25-01-402-PD-01 | 0 | PH Adjustment / ...
92 | C1S04-X2 | C1/S4 | C1S04,20 | 1756-IB32-20 | DI | 24 VDC energized | XV-40202F | XV-40202F_DI_1 | 3-25-01-402-PD-01 | 0 | PH Adjustment / ...
93 | C1S04-X2 | C1/S4 | C1S04,21 | 1756-IB32-21 | DI | 24 VDC energized | XV-40202F | XV-40202F_DI_2 | 3-25-01-402-PD-01 | 0 | PH Adjustment / ...
Doc No.: Instrument I/O List (Kalasin) - JB-401 | Page 3 of 4 | CONFIDENTIAL | Generated: 2026-09-07

ENCLOSURE: JB-401 | TYPE: Field Junction Box (Standard) | LOCATION: Infeed 2nd Floor | SIZE: 800-600-250 mm
SUMMARY: Total Channels: 112 | Active: 85 | Spare: 27 (24.1%) | DI: 64 | DO: 32 | AI: 16 | AO: 0 | BUS: 0
No. | Terminal | Rack/Slot | Channel | I/O Module | Type Signal Characteristic Instrument Tag | | | PLC Tag Name | P&ID No. | Service / Equipment Description | Zone / Floor
94 | C1S07-X2 | C1/S7 | C1S07,17 | 1756-OB32-17 | DO | 24 VDC energized | XV-40202F | XV-40202F_DO_1 | 3-25-01-402-PD-01 | 0 | PH Adjustment / ...
95 | C1S04-X2 | C1/S4 | C1S04,22 | 1756-IB32-22 | DI | 24 VDC energized | XV-40202G | XV-40202G_DI_1 | 3-25-01-402-PD-01 | 0 | PH Adjustment / ...
96 | C1S04-X2 | C1/S4 | C1S04,23 | 1756-IB32-23 | DI | 24 VDC energized | XV-40202G | XV-40202G_DI_2 | 3-25-01-402-PD-01 | 0 | PH Adjustment / ...
97 | C1S07-X2 | C1/S7 | C1S07,18 | 1756-OB32-18 | DO | 24 VDC energized | XV-40202G | XV-40202G_DO_1 | 3-25-01-402-PD-01 | 0 | PH Adjustment / ...
98 | C1S04-X2 | C1/S4 | C1S04,24 | 1756-IB32-24 | DI | 24 VDC energized | XV-40202H | XV-40202H_DI_1 | 3-25-01-402-PD-01 | 0 | PH Adjustment / ...
99 | C1S04-X2 | C1/S4 | C1S04,25 | 1756-IB32-25 | DI | 24 VDC energized | XV-40202H | XV-40202H_DI_2 | 3-25-01-402-PD-01 | 0 | PH Adjustment / ...
100 | C1S07-X2 | C1/S7 | C1S07,19 | 1756-OB32-19 | DO | 24 VDC energized | XV-40202H | XV-40202H_DO_1 | 3-25-01-402-PD-01 | 0 | PH Adjustment / ...
101 | C1S04-X2 | C1/S4 | C1S04,26 | 1756-IB32-26 | DI | 24 VDC energized | XV-40203B | XV-40203B_DI_1 | 3-25-01-402-PD-02 | 0 | Infeed Tank / 1st
102 | C1S04-X2 | C1/S4 | C1S04,27 | 1756-IB32-27 | DI | 24 VDC energized | XV-40203B | XV-40203B_DI_2 | 3-25-01-402-PD-02 | 0 | Infeed Tank / 1st
103 | C1S07-X2 | C1/S7 | C1S07,20 | 1756-OB32-20 | DO | 24 VDC energized | XV-40203B | XV-40203B_DO_1 | 3-25-01-402-PD-02 | 0 | Infeed Tank / 1st
104 | C1S04-X2 | C1/S4 | C1S04,28 | 1756-IB32-28 | DI | 24 VDC energized | XV-40203C | XV-40203C_DI_1 | 3-25-01-402-PD-02 | 0 | Infeed Tank / 1st
105 | C1S04-X2 | C1/S4 | C1S04,29 | 1756-IB32-29 | DI | 24 VDC energized | XV-40203C | XV-40203C_DI_2 | 3-25-01-402-PD-02 | 0 | Infeed Tank / 1st
106 | C1S07-X2 | C1/S7 | C1S07,21 | 1756-OB32-21 | DO | 24 VDC energized | XV-40203C | XV-40203C_DO_1 | 3-25-01-402-PD-02 | 0 | Infeed Tank / 1st
107 | C1S04-X2 | C1/S4 | C1S04,30 | 1756-IB32-30 | DI | 24 VDC energized | XV-40203D | XV-40203D_DI_1 | 3-25-01-402-PD-02 | 0 | Infeed Tank / 1st
108 | C1S04-X2 | C1/S4 | C1S04,31 | 1756-IB32-31 | DI | 24 VDC energized | XV-40203D | XV-40203D_DI_2 | 3-25-01-402-PD-02 | 0 | Infeed Tank / 1st
109 | C1S07-X2 | C1/S7 | C1S07,22 | 1756-OB32-22 | DO | 24 VDC energized | XV-40203D | XV-40203D_DO_1 | 3-25-01-402-PD-02 | 0 | Infeed Tank / 1st
110 | C1S05-X1 | C1/S5 | C1S05,00 | 1756-IB32-0 | DI | 24 VDC energized | XV-40203E | XV-40203E_DI_1 | 3-25-01-402-PD-02 | 0 | Infeed Tank / 1st
111 | C1S05-X1 | C1/S5 | C1S05,01 | 1756-IB32-1 | DI | 24 VDC energized | XV-40203E | XV-40203E_DI_2 | 3-25-01-402-PD-02 | 0 | Infeed Tank / 1st
112 | C1S07-X2 | C1/S7 | C1S07,23 | 1756-OB32-23 | DO | 24 VDC energized | XV-40203E | XV-40203E_DO_1 | 3-25-01-402-PD-02 | 0 | Infeed Tank / 1st
Doc No.: Instrument I/O List (Kalasin) - JB-401 | Page 4 of 4 | CONFIDENTIAL | Generated: 2026-09-07

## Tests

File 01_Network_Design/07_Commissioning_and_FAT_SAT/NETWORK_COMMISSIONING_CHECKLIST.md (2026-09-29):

# Industrial Network FAT / SAT Commissioning Checklist
**Facility**: Ingredion Kalasin Spray Dryer Plant  
**Testing Protocols**: Physical Layer Verification, Ping Sweep, DLR Failover Timing, Multicast IGMP Verification  

---

## 1. Physical Layer Testing & Inspection
- [ ] **Fiber Optic Tier 1 Testing**: Optical Loss Test Set (OLTS) certification for all strands (`FO-TRK-01..03`). Loss < 3.0 dB end-to-end.
- [ ] **Copper Testing**: Fluke DSX Cat6A Channel Test (Wiremap, NEXT, Return Loss, Length).
- [ ] **Shielding & Grounding**: Single-point termination of shield drains verified against ground loop currents.

---

## 2. Layer 2 / Layer 3 Protocol Validation
- [ ] **VLAN Routing**: Verified ping between VLAN 10 (SCADA) and VLAN 30 (PLC) across Core Gateway.
- [ ] **VLAN Isolation**: Verified access restriction between VLAN 40 (Area 202 Field I/O) and untrusted networks.
- [ ] **IGMP Snooping**: Verified with Wireshark that CIP implicit multicast traffic does not flood non-subscriber switch ports.

---

## 3. DLR Ring Redundancy Failover Testing
- [ ] **Ring Break Test (Cable Disconnect)**:
  - Disconnect Port 1 on `PLC-01-EN4T`.
  - Record failover time (target < 3ms).
  - Verify zero I/O module fault flags on ControlLogix chassis.
- [ ] **Ring Restore Test (Cable Reconnect)**:
  - Reconnect cable.
  - Verify Ring Supervisor automatically transitions back to "Ring Normal" without communication glitch.

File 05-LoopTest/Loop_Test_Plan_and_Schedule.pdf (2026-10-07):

TOTAL INSTRUMENT LOOPS | COLD LOOP INSPECTION
560 Loops | 100% Verified
Master Client Schedule Rev 3.6a | Continuity, Megger 500VDC, Polarity

### 1. LOOP TESTING SCOPE & SUBSYSTEM WORK BREAKDOWN

Subsystem / Plant Area | Target Field Enclosures | Associated PLC Rack
Jet Cooker Infeed & Pre-Treatment | JB-401 (Floor 2F) | Chassis C1 (Panel P1)
Jet Cooker Thermal Cooking Skid | JB-402 (Floor 2F) | Chassis C2 (Panel P2)
Spray Dryer Base & Powder Discharge | JB-601 (Floor 1F) | Chassis C1 (Panel P1)
Spray Dryer Cyclone & Exhaust Section | JB-602 (Floor 3F) | Chassis C2 (Panel P2)
Spray Dryer Direct Burner & Air Heater | JB-606 (Floor 6F) | Chassis C3 (Panel P3)
Spray Dryer Main Mid-Tower Section | JB-607, JB-608 (4F) | Chassis C2 & C3 (P2/P3)
Spray Dryer Upper Tower & Atomizer | JB-612 (Floor 6/8F) | Chassis C4 (Panel P4)
Packing Tower Feed & Silo Discharge JB-618 (Packing) | | Chassis C3 (Panel P3)
Hazardous Area Intrinsically Safe Loops | IS-JB-603/608/612/618 | Chassis C4 (P4 IS)
Slurry Preparation Outbuilding | RIO-200 (Slurry 2F) | Chassis C5 (RIO-200)
Integrated Interlocks & Handover | CA1 Central MCP | Master Chassis C1-C5

### 2. REQUIRED TEST INSTRUMENTS, CALIBRATORS & COMMISSIONING TOOL SPECIFICATIONS

Item # | Equipment Description | Manufacturer & Model
1 | Precision Documenting Process Calibrator | Fluke 754
2 | Precision Digital Pressure Calibrator | Druck DPI 611
3 | True RMS Digital Industrial Multimeter | Fluke 87V
4 | High-Voltage Insulation Resistance Tester | Megger MIT410/2
5 | Pneumatic Hand Test Pump w/ Vernier | Ralston Instruments AP-002
6 | Industrial 2-Way VHF/UHF Radios | Motorola Mototrbo DP4801e

## KALASIN ENGINEERING | xCIP-1545 AUTOMATION SYSTEM (Ref: x2608003)

MASTER INSTRUMENT LOOP TESTING PLAN, PROCEDURE & COMMISSIONING SCHEDULE — SPRINT 18K TPA SPRAY DRYER / JET COOKER

HOT LOOP CALIBRATION | COMMISSIONING SCHEDULE
5-Point Simulation | 4 Weeks (20 Days)
0%, 25%, 50%, 75%, 100% Range | Mobilization to Client Handover
Total Loops | Discrete DI/DO | Analog AI/AO | Hazardous Area Zone
96 | 74 | 22 | Safe Area
48 | 33 | 15 | Safe Area
61 | 45 | 16 | Safe Area
86 | 26 | 60 | Safe Area
9 | 5 | 4 | Classified / Burner
179 | 121 | 58 | Dust Zone 22 (Ext)
40 | 32 | 8 | Dust Zone 21/22
29 | 21 | 8 | Dust Zone 22
99 | 50 | 49 | ATEX Zone 1/21 (Ex ia)
66 | 48 | 18 | Safe Area
560 | 334 | 226 | Central Control
Calibration Parameter | Operating Range | Accuracy / Tolerance | Valid Calibration Certificate
4-20mA, Volts, RTD, TC, HART | -10 to 55 mA / 0-30V / Pt100 Gauge & | ±0.01% of Reading | ISO/IEC 17025 Certified
Differential Pressure | -1 to 20 bar (Hydraulic/Pneu) AC/DC Volts, | ±0.0185% FS | ISO/IEC 17025 Certified
Amps, Resistance, Continuity | 0 - 1000V DC / 0 -20A / 50MΩ Insulation | ±0.05% Accuracy | Factory Calibrated
Resistance @ 250V/500VDC Pneumatic Air | 10 kΩ to 100 GΩ | ±2% ±2 digits | Annual Certified
Pressure / Vacuum | 0 to 300 psi (20 bar) | Fine Vernier 0.01 psi | Traceable Reference
Intrinsically Safe ATEX Comms | 136 - 174 MHz | ATEX Gas/Dust Certified | Radio License Compliant

COMMISSIONING SCHEDULE | STANDARD COMPLIANCE
4 Weeks (20 Days) | IEC 62381 / ISA
Mobilization to Client Handover | Field Instrument Loop Check Standard
Primary Test Protocol | Estimated Duration | Scheduled Window
Cold + 4-20mA Flow/Press Sim | 3 Working Days | Week 1 (Day 3–5)
Temp RTD + Steam PRV Stroke | 2 Working Days | Week 2 (Day 6–7)
Rotary Valve + Pressure Trans | 2 Working Days | Week 2 (Day 8–9)
Diff Pressure DP + Temp RTDs | 3 Working Days | Week 2 (Day 9–10)
Combustible Gas + Thermal Flow | 1 Working Day | Week 3 (Day 11)
High-Density Transmitters & Valves | 4 Working Days | Week 3 (Day 12–14)
Atomizer Speed + Vent Pressure | 2 Working Days | Week 3 (Day 14–15)
Powder Silo Fork + Sieve DI | 2 Working Days | Week 4 (Day 16–17)
P&F IS Barrier Insulation & Loop Check | 3 Working Days | Week 4 (Day 17–18)
1Gbps DLR Ring + Slurry pH/Mass Flow | 2 Working Days | Week 4 (Day 18–19)
Full ESD Trip & SCADA Graphic Verification | 2 Working Days | Week 4 (Day 19–20)
Calibration Expiry Date | Dedicated Testing Purpose Analog 4-20mA 5-Point | Quantity Required
31-DEC-2026 | Loop Simulation & HART Config Pressure & Differential | 2 Units
15-NOV-2026 | Transmitter Calibration Check Cold continuity check, | 1 Unit
28-FEB-2027 | 24VDC loop power verification Pre-power cable insulation | 3 Units
15-JAN-2027 | & shield isolation (>20MΩ) | 2 Units
31-DEC-2026 | Field Pressure Transmitter 5-point mechanical test | 2 Units
Permanent | Direct Field-to-Control Room voice coordination | 6 Units

PUNCHLIST TRACKING

## Cat A & B System

100% Pre-commissioning Sign-off

Responsible Team Lead | Witness / QA/QC | Status
Lead Inst. Eng (Kalasin) | Ingredion QA/QC | READY FOR EXECUTION
Senior Comm. Eng | Ingredion QA/QC | READY FOR EXECUTION
Lead Inst. Eng (Kalasin) | Ingredion QA/QC | READY FOR EXECUTION
Senior Comm. Eng | Ingredion QA/QC | READY FOR EXECUTION
Lead Inst. Eng (Kalasin) | Burner Specialist | READY FOR EXECUTION
Lead Inst. Eng (Kalasin) | Ingredion QA/QC | READY FOR EXECUTION
Senior Comm. Eng | Ingredion QA/QC | READY FOR EXECUTION
Lead Inst. Eng (Kalasin) | Ingredion QA/QC | READY FOR EXECUTION
Ex-Certified Inspector | TUV / Client Safety | READY FOR EXECUTION
Senior Comm. Eng | Ingredion QA/QC | READY FOR EXECUTION
Project Commissioning Mgr | Ingredion Project Mgr | PLANNED
Serial Number | Certification Agency | Status
FLK-754-98421 | NIST / Thai Metrology | CERTIFIED ACTIVE
DRK-611-34901 | Baker Hughes Cal Lab | CERTIFIED ACTIVE
FLK-87V-11204 | Fluke Service Center | CERTIFIED ACTIVE
MEG-410-88319 | Megger Calibration Lab | CERTIFIED ACTIVE
RAL-AP-55201 | Ralston Metrology | CERTIFIED ACTIVE
MOT-DP-4801-SET | NBTC Thailand | INSPECTED ACTIVE

Stage # | Testing Activity / Protocol Step
STAGE 0 | Pre-Testing Prerequisite & Safety LOTO
STAGE 1 | Phase 1: Cold Loop Inspection & Cable Testing
STAGE 2 | Phase 2: Hot Loop Check & Power-Up
STAGE 3 | Phase 3: 5-Point Analog Loop Calibration Check (AI/AO)
STAGE 4 | Phase 4: Discrete Digital Loop (DI) & Limit Switch Check
STAGE 5 | Phase 5: Digital Output (DO) & Solenoid Valve Actuation
STAGE 6 | Phase 6: Control Valve (AO/AI) Modulation & Positioner Stroke
STAGE 7 | Phase 7: Alarm, Trip & Safety Interlock Verification
STAGE 8 | Phase 8: Punchlist Management & Final Acceptance Handover

## KALASIN ENGINEERING | STANDARD OPERATING PROCEDURE (SOP) — INSTRUMENT LOOP TESTING

Standardized Loop Check Protocol in Accordance with IEC 62381 (Factory & Site Acceptance Testing of Automation Systems)

Detailed Standard Operating Procedure (SOP)

mechanical terminations are complete.
2. Obtain valid Work Permit (Hot/Cold Work) and apply Lockout/Tagout (LOTO) on pneumatic headers and high-voltage power feeds.
3. Verify calibration validity of Fluke 754 calibrators and Megger instruments.
4. Establish dedicated radio communication between Field Lead and
2. Verify cable core identification against marshaling wiring drawings (C1S4-19/P1-TBDI1-17).
3. Disconnect transmitter and I/O card terminals before insulation testing to prevent card damage.
4. Perform Megger test @ 500VDC: Core-to-Core and Core-to-Shield/Ground for minimum 60 seconds.
1. Reconnect field wiring to marshaling terminals and transmitter terminals.
2. Energize 24VDC power supply circuit breaker in Control Cabinet CA1.
3. Measure DC voltage across instrument terminals using Fluke 87V.
4. Measure quiescent current draw and confirm proper polarity (positive to + / return to -).
5. In intrinsically safe (IS) loops, verify Pepperl+Fuchs IS barrier output voltage and barrier grounding.
2. Inject current ascending: 0% (4.00 mA), 25% (8.00 mA), 50% (12.00 mA), 75% (16.00 mA), 100% (20.00 mA).
3. Record Raw PLC counts (0..32767 for 1756-IF16) and SCADA HMI graphical display reading in engineering units.
4. Repeat descending check: 100% -> 75% -> 50% -> 25% -> 0% to evaluate hysteresis.
2. For level forks (FTM51 / FTL51B): simulate tuning fork immersion / vibration damping.
3. For pressure switches (PTC31B) and flow switches (FSL): simulate trip pressure / paddle movement.
4. Observe LED status indicator on 1756-IB32 card and verify tag status change (0 -> 1) on SCADA screen.
2. Issue Manual DO command (Force or HMI manual toggle) from SCADA workstation.
3. Verify 1756-OB32 channel output energizes 24VDC interposing relay / solenoid valve coil.
4. Confirm physical actuator stroke movement and measure open/close stroke travel time with stopwatch.
Trovis 3730-1 positioner.
2. Command AO from SCADA at 0%, 25%, 50%, 75%, 100% and descending.
3. Measure physical valve travel scale indicator and compare against 4-20mA position transmitter feedback.
4. Test fail-safe action: simulate power loss and air supply disconnection; confirm valve drives to fail position (Fail-Closed FC or Fail-Open FO).
(H), Low-Low (LL), High-High (HH).
2. Confirm audible horn annunciator, alarm banner flashing, and historical alarm log timestamp.
3. Verify automated safety shutdown interlocks (e.g. Cyclone High Temp -> Trip Burner Gas Solenoid).
4. Confirm that latched emergency shutdown (ESD) alarms require manual operator reset.
2. Record punchlist item with clear tag ID, responsible contractor, and target completion date.
3. Affix tamper-evident waterproof green 'LOOP CHECK PASSED' calibration tag onto field instrument.
4. Compile signed loop test sheets, calibration records, and ITP documentation into Master Handover Binder.

Pass / Acceptance Criteria | Responsible Personnel
Approved Work Permit, zero residual hazardous energy, test calibrator valid certificates on file. | Commissioning Lead & Safety Officer
Insulation resistance > 20 MΩ @ 500VDC. Shield grounded at Cabinet side ONLY (no double-grounding). Continuity resistance < 2 Ω. | Instrument Technician & QC Inspector
Terminal voltage within 21.6V to 26.4VDC. Quiescent current: 3.8 to 4.2 mA for analog 2-wire. No tripped fuses or circuit breaker faults. | Senior Commissioning Engineer
Max error ≤ ±0.5% of calibrated span across all 5 test points. Zero and span linearity verified. SCADA matches field simulation exactly. | Lead Instrument Engineer & SCADA Engineer
100% state change fidelity (Open=1, Close=0 or fail-safe logic). Card LED and SCADA display update within <100ms. No contact chatter. | Instrument Technician & SCADA Operator
Full valve travel stroke without sticking or pneumatic leakage. Stroke time within vendor datasheet specs (<3 sec for ball valves). SCADA graphic updates from Red to Green. | Commissioning Lead & Mechanical Tech
Travel error ≤ ±1.0% of full stroke. Hysteresis ≤ 0.5%. Fail-safe spring return drives to fail-safe position in <2.0 seconds. | Valve Specialist & Lead Inst Engineer
100% interlock trip action verified. ESD valve de-energization confirmed. Correct alarm priority colors (Red=Emergency, Yellow=Warning). | Lead Process Automation Engineer & Client Rep
Zero Category A punchlist items remaining. All Category B items agreed with sign-off. Green Loop Pass tag affixed to instrument. | Project Commissioning Manager & Client PM

Verifying Document / Record | QA/QC Hold Point
Work Permit + Equipment Cal Certs | HOLD POINT (Mandatory Sign-off)
Cold Loop Check Sheet (Sheet 03) | WITNESS POINT
Hot Loop Power-Up Record | REVIEW POINT
5-Point Calibration Record (Sheet 03) | HOLD POINT (Client Witness)
Discrete Test Log Sheet | WITNESS POINT
Valve Actuation Test Protocol | WITNESS POINT
Control Valve Calibration Certificate | HOLD POINT (Client Witness)
Safety Interlock Matrix Sign-off | HOLD POINT (Mandatory Sign-off)
Master Handover Certificate | FINAL ACCEPTANCE MILESTONE

## KALASIN ENGINEERING | MASTER COMMISSIONING & LOOP TESTING EXECUTION SCHEDULE

4-Week Comprehensive Day-by-Day (Days 1 to 20) Gantt Timeline Across All Plant Subsystems & Field Junction Boxes

TASK IDENTIFICATION & WORK BREAKDOWN

Task ID | Activity / Loop Testing Scope Description | Target Area / JB | Duration
T-01 | Mobilization, Safety Induction, LOTO & Calibrator Certification | Site-wide | 2 Days
T-02 | Control Cabinet CA1 Power-up & DLR Network Health Check | CA1 MCP | 1 Day
T-03 | JB-401 Jet Cooker Infeed Cold Loop Check & Megger Testing | JB-401 (2F) | 2 Days
T-04 | JB-401 Jet Cooker Hot Loop 5-Pt Calibration & Discrete Check | JB-401 (2F) | 2 Days
T-05 | JB-402 Jet Cooker Skid Cold Loop & Hot Loop Testing | JB-402 (2F) | 2 Days
T-06 | Jet Cooker Steam PRV & Samson Control Valve Stroke Check | Jet Cooker | 1 Day
T-07 | MILESTONE 1: Jet Cooker Skid Loop Test Handover Sign-off | Skid 2F | Milestone
T-08 | JB-601 Spray Dryer Base Floor 1F Cold & Hot Loop Tests | JB-601 (1F) | 2 Days
T-09 | JB-602 Cyclone & Exhaust Floor 3F Cold & Hot Loop Tests | JB-602 (3F) | 2 Days
T-10 | JB-606 Direct Air Heater Burner Loop Checking | JB-606 (6F) | 1 Day
T-11 | JB-607 Mid-Tower Main Deck High-Density Loop Testing (Part 1) | JB-607 (4F) | 2 Days
T-12 | JB-607 Mid-Tower Main Deck High-Density Loop Testing (Part 2) | JB-607 (4F) | 2 Days
T-13 | JB-608 Auxiliary Deck Sight Glass & Level Testing | JB-608 (4F) | 1 Day
T-14 | JB-612 Upper Tower & Atomizer 6F/8F Loop Check | JB-612 (6/8F) | 2 Days
T-15 | MILESTONE 2: Spray Dryer Tower Loop Test Handover Sign-off | Dryer Tower | Milestone
T-16 | JB-618 Packing Tower & Silos Cold & Hot Loop Tests | JB-618 | 2 Days
T-17 | IS-JB-603 & IS-JB-608 Intrinsically Safe Ex ia Loop Check | IS JBs (Ex) | 2 Days
T-18 | IS-JB-612 & IS-JB-618 Intrinsically Safe Ex ia Loop Check | IS JBs (Ex) | 2 Days
T-19 | RIO-200 Slurry Outbuilding Remote Station Loop Check | RIO-200 (2F) | 2 Days
T-20 | Integrated System Safety Interlocks & ESD Trip Simulation | CA1 / Plant | 2 Days
T-21 | Category A & B Punchlist Clearance & Pre-start Rectification | Site-wide | 1 Day
T-22 | FINAL MILESTONE: Master Loop Check Protocol Tripartite Handover | Client MCP | Final

## KALASIN ENGINEERING | MASTER COMMISSIONING & LOOP TESTING EXECUTION SCHEDULE

4-Week Comprehensive Day-by-Day (Days 1 to 20) Gantt Timeline Across All Plant Subsystems & Field Junction Boxes

WEEK 3: UPPER TOWER & IS ZONES

WEEK 1: MOBILIZATION & JET COOKER | WEEK 2: SPRAY DRYER LOWER & MID
Lead | D1 | D2 | D3 | D4 | D5 | D6 | D7 | D8 | D9 | D10 | D11 | D12 | D13
Lead | █ | █
Comm | | █
Inst-1 | | | █ | █
Inst-1 | | | | █ | █
Inst-2 | | | | | | █ | █
Valve | | | | | | | █
PM/QC | | | | | | | ★
Inst-1 | | | | | | | | █ | █
Inst-2 | | | | | | | | | █ | █
Inst-1 | | | | | | | | | | | █
Inst-1 | | | | | | | | | | | █ | █
Inst-2 | | | | | | | | | | | | | █

Inst-1

Inst-2

PM/QC

Inst-1

Ex-Lead

Ex-Lead

Inst-2

Auto

Team

Tripartite

D14 | D15 | D16 | D17 | D18 | D19 | D20

█
█
█ | █
| ★
| | █ | █
| | █ | █
| | | █ | █
| | | | █ | █
| | | | | █ | █
| | | | | | █
| | | | | | ★

WEEK 4: SLURRY RIO & SYSTEM HANDOVER

Item # | Active Tag No. | Legacy Tag | P&ID No.
1 | AT-60241 | - | 325-01-602-PD-05
2 | DPT-60201 | DPT-60901 | 325-01-602-PD-09
3 | DPT-61301 | - | 325-01-613-PD-01
4 | DPT-61302 | - | 325-01-613-PD-01
5 | DPT-61310 | - | 325-01-613-PD-03
6 | DPT-61312 | - | 325-01-613-PD-05
7 | DPT-60202 | - | 325-01-602-PD-08
8 | DPT-60203 | - | 325-01-602-PD-03
9 | FSL-20201 | | 325-01-202-PD-01
10 | FSL-40201 | | 325-01-402-PD-01
11 | FSL-40202 | | 325-01-402-PD-01
12 | FS-40204 | | 325-01-402-PD-01
13 | FS-40205 | | 325-01-402-PD-02
14 | FT-40201 | - | 325-01-402-PD-02
15 | FT-40202 | - | 325-01-402-PD-02
16 | FT-40221 | | 325-01-402-PD-02
17 | FT-40222 | | 325-01-402-PD-02
18 | FT-60221 | - | 325-01-602-PD-04
19 | FT-60201 | - | 325-01-602-PD-08
20 | FT-60210 | - | 325-01-602-PD-03
21 | FT-60211 | - | 325-01-602-PD-03
22 | FT-60261FA | - | 325-01-602-PD-02
23 | FT-60261FB | - | 325-01-602-PD-02
24 | FT-60261FC | - | 325-01-602-PD-02
25 | FT-60261FD | - | 325-01-602-PD-02
26 | FT-60262FE | - | 325-01-602-PD-02
27 | FT-60262FF | - | 325-01-602-PD-02
28 | FT-60262FG | - | 325-01-602-PD-02
29 | FT-60262FH | - | 325-01-602-PD-02
30 | FT-60263FJ | - | 325-01-602-PD-02
31 | FT-60263FK | - | 325-01-602-PD-02

32 | FT-60263FL | - | 325-01-602-PD-02
33 | FT-60263FM | - | 325-01-602-PD-02
34 | FT-60264FN | - | 325-01-602-PD-02
35 | FT-60264FP | - | 325-01-602-PD-02
36 | FT-60264FQ | - | 325-01-602-PD-02
37 | FT-60264FR | - | 325-01-602-PD-02
38 | FT-61307 | - | 325-01-613-PD-04
39 | FT-60203 | FT-60901 | 325-01-602-PD-09
40 | FT-60202 | FT-60902 | 325-01-602-PD-09
41 | FT-60204 | FT-61101 | 325-01-602-PD-10
42 | FT-936201 | FT-90301 | 325-01-930-PD-01
43 | FT-936202 | FT-93001 | 325-01-930-PD-02
44 | HS-61307A | - | 325-01-613-PD-03
45 | HS-61307B | - | 325-01-613-PD-03
46 | HS-61307C | - | 325-01-613-PD-03
47 | HS-61307D | - | 325-01-613-PD-03
48 | HS-61307E | - | 325-01-613-PD-03
49 | HS-61307F | - | 325-01-613-PD-03
50 | HS-61307G | - | 325-01-613-PD-03
51 | HS-61307H | - | 325-01-613-PD-03
52 | HS-61307I | - | 325-01-613-PD-03
53 | HS-61307J | - | 325-01-613-PD-03
54 | HS-61307K | - | 325-01-613-PD-03
55 | HS-61307L | - | 325-01-613-PD-03
56 | HS-61307M | - | 325-01-613-PD-03
57 | HS-61307N | - | 325-01-613-PD-03
58 | HS-61307O | - | 325-01-613-PD-03
59 | HS-61307P | - | 325-01-613-PD-03
60 | HS-61307Q | - | 325-01-613-PD-03
61 | HS-61307R | - | 325-01-613-PD-03
62 | HV-40203 | HV-4106 | 325-01-402-PD-01
63 | HV-40201 | HV-4108 | 325-01-402-PD-01
64 | HV-40204 | HV-4126 | 325-01-402-PD-01
65 | HV-40202 | HV-4128 | 325-01-402-PD-01
66 | HV-40206 | HV-4208 | 325-01-402-PD-01

67 | HV-40205 | HV-4210 | 325-01-402-PD-01
68 | HV-40207 | | 325-01-402-PD-01
69 | HV-40208 | | 325-01-402-PD-01
70 | LSH-60230 | - | 325-01-602-PD-04
71 | LSH-60231 | - | 325-01-602-PD-04
72 | LSH-60240 | - | 325-01-602-PD-05
73 | LSH-60250 | - | 325-01-602-PD-05
74 | LSH-60251 | - | 325-01-602-PD-04
75 | LSL-60201 | LSL-61101 | 325-01-602-PD-11
76 | LSH-61301 | - | 325-01-613-PD-01
77 | LSL-61302 | - | 325-01-613-PD-01
78 | LS-61303 | - | 325-01-613-PD-01
79 | LSH-61304 | - | 325-01-613-PD-03
80 | LSH-61305 | - | 325-01-613-PD-05
81 | LSH-61306 | - | 325-01-613-PD-01
82 | LSH-61307 | | 325-01-613-PD-01
83 | LSH-61308 | | 325-01-613-PD-01
84 | LSH-61312 | - | 325-01-613-PD-05
85 | LSL-814201 | LSL-81001 | 325-01-814-PD-01
86 | LT-40201 | LT-40101 | 325-01-402-PD-01
87 | LT-40202 | LT-40102 | 325-01-402-PD-01
88 | LT-40203 | LT-40201 | 325-01-402-PD-02
89 | LT-61301 | - | 325-01-613-PD-01
90 | pHT-40201 | pHT-40101 | 325-01-402-PD-01
91 | pHT-40202 | pHT-40102 | 325-01-402-PD-01
92 | PSL-60220 | - | 325-01-602-PD-04
93 | PSL-61301 | | 325-01-613-PD-01
94 | PSL-61302 | - | 325-01-613-PD-01
95 | PSL-61305 | - | 325-01-613-PD-03
96 | PSL-61306 | - | 325-01-613-PD-05
97 | PSL-61311 | - | 325-01-613-PD-04
98 | PT-40201 | - | 325-01-402-PD-02
99 | PT-40202 | - | 325-01-402-PD-02
100 | PT-40222 | | 325-01-402-PD-02
101 | PT-60201 | - | 325-01-602-PD-02

102 | PT-60202 | - | 325-01-602-PD-01
103 | PT-60203 | - | 325-01-602-PD-08
104 | PT-60210 | - | 325-01-602-PD-03
105 | PT-60215 | - | 325-01-602-PD-03
106 | PT-60216 | - | 325-01-602-PD-03
107 | PT-60220 | - | 325-01-602-PD-04
108 | PT-60221 | - | 325-01-602-PD-04
109 | PT-60230 | - | 325-01-602-PD-04
110 | PT-60231 | - | 325-01-602-PD-04
111 | PT-60240 | - | 325-01-602-PD-05
112 | PT-60241 | - | 325-01-602-PD-05
113 | PT-60204 | PT-61101 | 325-01-602-PD-10
114 | PT-61301 | - | 325-01-613-PD-01
115 | PT-61302 | - | 325-01-613-PD-03
116 | PT-61303 | - | 325-01-613-PD-01
117 | PT-61304 | - | 325-01-613-PD-01
118 | PT-61305 | - | 325-01-613-PD-01
119 | PT-61309 | - | 325-01-613-PD-04
120 | PCV-60201 | PV-60201 | 325-01-602-PD-02
121 | SV-40201 | SV-40101 | 325-01-402-PD-01
122 | SV-40202 | SV-40102 | 325-01-402-PD-01
123 | SV-40203 | SV-40103 | 325-01-402-PD-01
124 | SV-40204 | SV-40104 | 325-01-402-PD-01
125 | SV-60220 | - | 325-01-602-PD-04
126 | SV-60230 | - | 325-01-602-PD-04
127 | SV-60231 | - | 325-01-602-PD-04
128 | SV-60240A | - | 325-01-602-PD-05
129 | SV-60240B | - | 325-01-602-PD-05
130 | SV-60240C | - | 325-01-602-PD-05
131 | SV-61301 | - | 325-01-613-PD-01
132 | SV-61302 | - | 325-01-613-PD-01
132 | SV-61306 | | 325-01-613-PD-01
133 | SV-61303 | - | 325-01-613-PD-01
134 | SV-61305 | - | 325-01-613-PD-01
135 | SV-61308 | - | 325-01-613-PD-03

136 | SV-61309 | - | 325-01-613-PD-03
137 | SV-61310 | - | 325-01-613-PD-05
138 | SV-61311 | - | 325-01-613-PD-05
139 | TSH-60230 | - | 325-01-602-PD-04
140 | TSH-60240 | - | 325-01-602-PD-05
141 | TT-40221 | | 325-01-402-PD-02
142 | TT-40222 | | 325-01-402-PD-02
143 | TT-60201 | - | 325-01-602-PD-02
144 | TT-60210 | - | 325-01-602-PD-03
145 | TT-60210A | TT-60212A | 325-01-602-PD-03
146 | TT-60210B | TT-60212B | 325-01-602-PD-03
147 | TT-60211 | - | 325-01-602-PD-03
148 | TT-60214 | - | 325-01-602-PD-03
149 | TT-60215A | - | 325-01-602-PD-03
150 | TT-60215B | - | 325-01-602-PD-03
151 | TT-60216 | - | 325-01-602-PD-03
152 | TT-60220 | - | 325-01-602-PD-04
153 | TT-60221 | - | 325-01-602-PD-04
154 | TT-60222 | - | 325-01-602-PD-04
155 | TT-60223 | - | 325-01-602-PD-04
156 | TT-60224 | - | 325-01-602-PD-04
157 | TT-60225 | - | 325-01-602-PD-04
158 | TT-60226 | - | 325-01-602-PD-04
159 | TT-60227 | - | 325-01-602-PD-04
160 | TT-60230 | - | 325-01-602-PD-04
161 | TT-60240 | - | 325-01-602-PD-05
162 | TT-60241A | - | 325-01-602-PD-05
163 | TT-60241B | - | 325-01-602-PD-05
164 | TT-60245 | - | 325-01-602-PD-05
165 | TT-60202 | TT-60702 | 325-01-602-PD-07
166 | TT-61301 | - | 325-01-613-PD-01
167 | TT-61302 | - | 325-01-613-PD-01
168 | TCV-40222 | | 325-01-402-PD-02
169 | TCV-60214 | TV-60214 | 325-01-602-PD-03
170 | TCV-60202 | TV-60702 | 325-01-602-PD-07

171 | VT-60210A | - | 325-01-602-PD-03
172 | VT-60210B | - | 325-01-602-PD-03
173 | VT-60241A | - | 325-01-602-PD-05
174 | VT-60241B | - | 325-01-602-PD-05
175 | XT-60201 | XT-60301 | 325-01-402-PD-03
176 | XA-60201 | XA-60301 | 325-01-402-PD-03
177 | XT-92201 | - | 325-01-923-PD-03
178 | XA-92201 | - | 325-01-923-PD-03
179 | XV-40201A | XV-40101A | 325-01-402-PD-01
180 | XV-40201B | XV-40101B | 325-01-402-PD-01
181 | XV-40201C | XV-40101C | 325-01-402-PD-01
182 | XV-40201D | XV-40101D | 325-01-402-PD-01
183 | XV-40201E | XV-40101E | 325-01-402-PD-01
184 | XV-40201F | XV-40101F | 325-01-402-PD-01
185 | XV-40201G | XV-40101G | 325-01-402-PD-01
186 | XV-40201H | XV-40101H | 325-01-402-PD-01
187 | XV-40202A | XV-40102A | 325-01-402-PD-01
188 | XV-40202B | XV-40102B | 325-01-402-PD-01
189 | XV-40202C | XV-40102C | 325-01-402-PD-01
190 | XV-40202D | XV-40102D | 325-01-402-PD-01
191 | XV-40202E | XV-40102E | 325-01-402-PD-01
192 | XV-40202F | XV-40102F | 325-01-402-PD-01
193 | XV-40202G | XV-40102G | 325-01-402-PD-01
194 | XV-40202H | XV-40102H | 325-01-402-PD-01
195 | XV-40203B | XV-40201B | 325-01-402-PD-02
196 | XV-40203C | XV-40201C | 325-01-402-PD-02
197 | XV-40203D | XV-40201D | 325-01-402-PD-02
198 | XV-40203E | XV-40201E | 325-01-402-PD-02
199 | XV-40203F | | 325-01-402-PD-02
200 | XV-40204B | | 325-01-402-PD-01
201 | XV-40204C | | 325-01-402-PD-01
202 | XV-40205A | | 325-01-402-PD-02
203 | XV-40205B | | 325-01-402-PD-02
204 | XV-40205C | | 325-01-402-PD-02
205 | XV-40205D | | 325-01-402-PD-02
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

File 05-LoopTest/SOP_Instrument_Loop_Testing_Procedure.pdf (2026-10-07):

KALASIN ENGINEERING | PROJECT SPRINT 18K TPA SPRAY DRYER / JET COOKER | DOC: KAL-SOP-INS-0545 | REV 1.0

KALASIN ENGINEERING CO., LTD.

PROJECT SPRINT 18K TPA SPRAY DRYER / JET COOKER | REF: x2608003

### STANDARD OPERATING PROCEDURE (SOP)

INSTRUMENT LOOP TESTING & FIELD COMMISSIONING METHODOLOGY

Conforming to IEC 62381, ISA-RP60.8, and NFPA 79 Standards

Document Field | Specification | Document Field | Specification
Document Refer-ence: | KAL-SOP-INS-0545 | Issue Date: | 07-October-2026
Revision: | Rev. 1.0 (Approved for Execution) | Target Facility: | Ingredion Kalasin Facility
Lead C&I Contrac-tor: | Kalasin Engineering Co., Ltd. | Client Organiza-tion: | Ingredion (Thailand) Co., Ltd.
Applicable Enclo-sures: | 15 Junction Boxes (JB-401 to JB-618, IS-JBs) | Total Scope: | 395 Equipment / 620 Channels

### 1. PURPOSE & APPLICABLE STANDARDS

This Standard Operating Procedure (SOP) defines the mandatory technical requirements, safety precautions, test connection topologies, and acceptance criteria for performing instrument loop checks and pre-commissioning verification. All tests must strictly comply with:
- IEC 62381: Process Industry — Automation Systems — Activities during factory acceptance testing, site acceptance testing, and site integration.
- ISA-RP60.8: Hardware Guide for Control Centers & Instrument Loop Verification.
- IEC 60079-14: Explosive Atmospheres — Electrical installations design, selection, and erection (for Intrinsically Safe loops in IS-JB-603, 608, 612, 618).
- NFPA 79: Electrical Standard for Industrial Machinery.

### 2. PRE-COMMISSIONING COLD LOOP TEST METHODS

CRITICAL SAFETY PRECAUTION: SENSITIVE ELECTRONICS ISOLATION
High-voltage Megger insulation testing (500 VDC) WILL PERMANENTLY DESTROY solid-state instrument electronics, SMART positioners, and Allen-Bradley ControlLogix 1756 / 1794 FLEX I/O modules. Both cores (+ and -) MUST BE FULLY DISCON-NECTED at the transmitter terminal head and at the CA1 marshalling rack before pressing the Megger test button.

### 2.1 Cable Insulation Resistance Testing (Megger 500 VDC)

Objective: Verify the dielectric integrity of cable insulation to prove zero leakage paths exist between conductors, shields, and ground.
- Test Instrument: Calibrated 500 VDC Insulation Tester (e.g., Megger MIT410/2 or Fluke 1507). Calibration certificate must be valid within 12 months.
- Test Duration: 60 seconds continuous test per measurement point.
- Acceptance Criterion: ≥ 20 MΩ @ 500 VDC (Typical healthy new cabling reads > 100 MΩ).

Test Execution Matrix (4 Mandatory Test Points):
1. Core-to-Core (A B): Apply 500 VDC between Conductor A (+) and Conductor B (-). Minimum 20 MΩ.
2. Core-to-Shield (A SH & B SH): Apply 500 VDC between each signal conductor and the cable shield drain wire. Minimum 20 MΩ.
3. Core-to-Earth (A PE & B PE): Apply 500 VDC between each signal conductor and the plant Protective Earth (PE). Minimum 20 MΩ.
4. Shield-to-Earth (SH PE): Apply 500 VDC between the cable shield drain wire and Protective Earth. Minimum 20 MΩ (proves shield is floating at field/JB).
CONFIDENTIAL — INGREDION (THAILAND) CO., LTD. & KALASIN ENGINEERING | IEC 62381 / ISA-RP60.8 Standards

5. Post-Test Discharge: Allow the tester to automatically bleed off cable capacitive charge for at least 15 seconds before touching any conductor.

### 2.2 Loop Conductor Resistance Testing (Continuity Check)

Objective: Confirm complete end-to-end electrical path, verify that no high-resistance cold-solder or loose screw connections exist, and confirm correct polarity.
- Test Instrument: Digital Multimeter (Fluke 87V or Fluke 789 ProcessMeter) set to Low-Ohm resistance mode.
- Acceptance Criterion: ≤ 2.0 Ω total round-trip loop resistance (typical for 0.75 mm² to 1.5 mm² cable runs up to 150 meters).

Step-by-Step Test Procedure:
1. Lead Nulling: Touch meter test leads together and engage the REL / ZERO function to null out test lead internal resistance (0.00 Ω).
2. Field Shorting: At the field device terminal strip, attach an insulated temporary shorting bridge securely across Terminal 1 (+) and Terminal 2 (-).
3. Resistance Measurement: At the CA1 marshalling rack, measure resistance across the corresponding incoming trunk terminal pair. Record measured ohms.
4. Open-Circuit Check: Remove the field shorting bridge. The meter at CA1 must immediately transition to O.L (Open Loop / Infinite Ω). If any finite resistance is observed, an unwanted parallel path or short circuit exists and must be repaired.
5. Polarity Verification: Apply a known +9.0 VDC battery across Core A (+) and Core B (-) at CA1. Measure DC voltage at the field device. Verify positive polarity on Core A.

### 2.3 Single-Point Earth Shielding (“CUTBACK & TAPE” Rule)

Objective: Prevent low-frequency 50 Hz AC ground hum, radio-frequency interference (RFI), and circulating eddy currents caused by differences in earth potential across the facility.
- Acceptance Criteria:
- Shield-to-Ground resistance at Field Instrument: Infinite (O.L / > 20 MΩ) (Completely floating).
- Shield-to-Ground resistance at Junction Box: Infinite (O.L / > 20 MΩ) (Isolated from metallic chassis).
- Shield-to-IE Busbar at CA1 Marshalling: < 0.1 Ω (Bonded cleanly).
- Instrument Clean Earth (IE) to Ground Pit: < 1.0 Ω.

Execution Rules:
- At Field Device: Strip the outer cable jacket. Cut the aluminum foil shield and bare tinned copper drain wire flush with the sheath base. Encase the cut end in a heat-shrink insulating sleeve and wrap securely with self-amalgamating tape. The shield must never contact the metallic instrument enclosure.
- At Junction Box: Connect the incoming branch shield drain and the outgoing trunk multi-pair shield drain through an insulated feedthrough terminal (SH). Keep completely isolated from the mounting DIN rail and enclosure chassis.
- At CA1 Marshalling Cabinet: Land all trunk shield drain wires directly onto the dedicated, insulated copper Instrument Earth (IE) busbar. This represents the single, centralized earthing reference for the entire control loop.

### 2.4 Enclosure, Cable Gland & Tag Physical Inspection

Objective: Guarantee mechanical robustness, environmental sealing, and long-term operating reliability.

Inspection Item | Standard / Acceptance Spec | Verification Method
Ingress Protection (IP66/67) | Neoprene gasket intact, continu-ous, unpinched | Visual check; verify cover bolts torqued to 3.5 N·m
Cable Glands | Certified Ex-d / Ex-e nickel-plated brass or SS316 | Hand tightness check; verify elastomeric seal com-pressed
Breather / Drain Plug | SS316 certified drain plug at lowest enclosure point | Verify downward orientation for condensate drainage
Stainless Steel Tag Plate | SS316 engraved plate (Tag, P&ID, Service) | Cross-reference with P&ID; verify secured with SS wire
Wire Terminations | Insulated bootlace ferrules on all stranded wires | Pull test (gentle tug); check torque (0.5–0.6 N·m)

Inspection Item | Standard / Acceptance Spec | Verification Method
Spare Cable Cores | Fitted with insulated end ferrules, labeled ‘SPARE’ | Neatly coiled in lower duct; landed on spare termi-nals

### 3. LIVE HOT LOOP & CALIBRATION METHODOLOGY

### 3.1 Analog Input (AI) 2-Pin Differential Pair Calibration

In the Allen-Bradley 1756-IF16 current input architecture, each analog channel utilizes two physical pins:
- Pin A: IN-x (Signal current input positive, landed on terminal strip (A))
- Pin B: i RTN-x (Signal current return negative, landed on terminal strip (B))

5-Point Simulated Signal Injection Table: Inject calibrated current using a Fluke 789 / Fluke 754 process calibrator directly across Pin A and Pin B at the field junction box:

Test Point | Simulated In-put | PLC Raw Counts | SCADA Display Value | Max Error | Result
0% (Zero) | 4.000 mA | 0 counts | 0.0 % (LRV) | ± 0.20% | PASS
25% (Span 1/4) | 8.000 mA | 8192 counts | 25.0 % EU | ± 0.20% | PASS
50% (Mid) | 12.000 mA | 16384 counts | 50.0 % EU | ± 0.20% | PASS
75% (Span 3/4) | 16.000 mA | 24576 counts | 75.0 % EU | ± 0.20% | PASS
100% (Full Span) | 20.000 mA | 32767 counts | 100.0 % (URV) | ± 0.20% | PASS

### 3.2 Discrete Valve & Multi-Signal Equipment Testing

For actuated on-off valves (XV-40201A, HV, SOV) and flowmeters (FT-40201):
1. Solenoid Actuation (DO): Force DO bit in ControlLogix. Verify 24 VDC energizes the solenoid coil, pilot valve shifts cleanly, and valve strokes within specification (< 1.5 sec).
2. Open / Close Limit Switches (DI):
- When valve reaches 100% full open: Proximity target hit, Dry Contact closes, PLC DI_1 bit changes 0 -> 1, SCADA icon turns steady GREEN.
- When valve de-energizes to 0% full closed: Spring returns valve to fail-safe seat, PLC DI_2 bit changes 0 -> 1, SCADA icon turns steady RED.
3. Flowmeter Aux Power & Pulse Counters: Verify 24 VDC / 220 VAC auxiliary instrument power bus voltage. Inject 100 Hz pulse train into high-speed digital input (DI_1). Verify totalizer increments accurately on SCADA.

### 4. TRIPARTITE COMMISSIONING ACCEPTANCE SIGN-OFF

Upon completion of all cold and hot loop checks:
1. Green Loop Test Tag: Attach a weather-proof green inspection tag to the instrument cable gland marked with Date, Loop Pass Status, and Inspector Initials.
2. Certificate Archiving: Sign and date the individual equipment sheet inside the corresponding Junction Box Workbook
(Loop_Test_Report_JB-xxx.xlsx).
3. Tripartite Signatories:
- Tested By: Lead C&I Engineer, Kalasin Engineering Co., Ltd.
- Witnessed By: QA/QC Electrical & Instrumentation Inspector, Ingredion (Thailand) Co., Ltd.
- Approved By: Project Commissioning Manager, Joint Commissioning Team.

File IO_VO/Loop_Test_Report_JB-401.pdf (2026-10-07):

## KALASIN ENGINEERING | JUNCTION BOX LOOP TEST REGISTER: JB-401

Project Sprint 18K TPA Spray Dryer / Jet Cooker | Location: JB-401 | 1 Equipment = 1 Sheet
TOTAL EQUIPMENT | TOTAL ACTIVE CHANNELS
42 Units | 85 Channels
Item # | Equipment Tag | Equipment Service Description | P&ID Drawing No.
1 | FSL-40201 | Slurry low flow | 325-01-402-PD-01
2 | FSL-40202 | Slurry low flow | 325-01-402-PD-01
3 | FT-40201 | Slurry flowrate & density check transfer line | 325-01-402-PD-02
4 | FT-40202 | Feed Slurry Flow Transmitter for Pipe (PIPE) | 325-01-402-PD-02
5 | HV-40201 | Slurry Drain line | 325-01-402-PD-01
6 | HV-40202 | Slurry Drain line | 325-01-402-PD-01
7 | HV-40203 | Slurry Drain tank TS-40201 | 325-01-402-PD-01
8 | HV-40204 | Slurry Drain tank TS-40202 | 325-01-402-PD-01
9 | HV-40205 | Slurry Drain line | 325-01-402-PD-01
10 | HV-40206 | Slurry Drain tank TS-40203 | 325-01-402-PD-01
11 | LT-40201 | Level transmitter in Spray dryer infeed tank | 325-01-402-PD-02
12 | LT-40202 | Level transmitter in pH Adjustment tank 2 | 325-01-402-PD-01
13 | LT-40203 | Level transmitter in Spray dryer infeed tank | 325-01-402-PD-02
14 | PT-40201 | Pressure Transmitter for Inlet Filter Strainer (FSTR-11) | 325-01-402-PD-02
15 | PT-40202 | Feed Slurry Pressure Transmitter for Pipe (PIPE) | 325-01-402-PD-02
16 | PT-60202 | Feed Slurry Pressure Transmitter for High Pressure Pump Outlet (PUPD-11) | 325-01-602-PD-01
17 | SV-40201 | Water service pH analyzer in pH Adjustment tank 1 | 325-01-402-PD-01
18 | SV-40202 | Water service pH analyzer in pH Adjustment tank 2 | 325-01-402-PD-01
19 | SV-40203 | Air service pH analyzer in pH Adjustment tank 1 | 325-01-402-PD-01
20 | SV-40204 | Air service pH analyzer in pH Adjustment tank 2 | 325-01-402-PD-01
21 | XV-40201A | Slurry feed-in pH Adjustment tank 1 | 325-01-402-PD-01
22 | XV-40201B | Slurry feed-out Spray dryer infeed tank | 325-01-402-PD-02
23 | XV-40201C | Water washing line outlet Spray dryer infeed tank | 325-01-402-PD-02
24 | XV-40201D | CIP water washing Spray dryer infeed tank | 325-01-402-PD-02
25 | XV-40201E | CIP hight pressure water washing Spray dryer infeed tank | 325-01-402-PD-02
26 | XV-40201F | Slurry feed-to spray dry tank | 325-01-402-PD-01
27 | XV-40201G | CIP water washing pH Adjustment tank 1 | 325-01-402-PD-01
28 | XV-40201H | CIP Hight pressure water washing pH Adjustment tank 1 | 325-01-402-PD-01

29 | XV-40202A | Slurry feed-in pH Adjustment tank 2 | 325-01-402-PD-01
30 | XV-40202B | Slurry feed-out pH Adjustment tank 2 | 325-01-402-PD-01
31 | XV-40202C | Water washing line outlet pH Adjustment tank 2 | 325-01-402-PD-01
32 | XV-40202D | Slurry circulation pH Adjustment tank 2 | 325-01-402-PD-01
33 | XV-40202E | Slurry pH Adjustment tank 2 transfer to pH Adjustment tank 1 | 325-01-402-PD-01
34 | XV-40202F | Slurry feed-to spray dry tank | 325-01-402-PD-01
35 | XV-40202G | CIP water washing pH Adjustment tank 2 | 325-01-402-PD-01
36 | XV-40202H | CIP Hight pressure water washing pH Adjustment tank 2 | 325-01-402-PD-01
37 | XV-40203B | Slurry feed-out Spray dryer infeed tank | 325-01-402-PD-02
38 | XV-40203C | Water washing line outlet Spray dryer infeed tank | 325-01-402-PD-02
39 | XV-40203D | CIP water washing Spray dryer infeed tank | 325-01-402-PD-02
40 | XV-40203E | CIP hight pressure water washing Spray dryer infeed tank | 325-01-402-PD-02
41 | pHT-40201 | pH analyzer in pH Adjustment tank 1 | 325-01-402-PD-01
42 | pHT-40202 | pH analyzer in pH Adjustment tank 2 | 325-01-402-PD-01

## KALASIN ENGINEERING | JUNCTION BOX LOOP TEST REGISTER: JB-401

Project Sprint 18K TPA Spray Dryer / Jet Cooker | Location: JB-401 | 1 Equipment = 1 Sheet
DIGITAL INPUT (DI) | DIGITAL OUTPUT (DO)
50 Pts | 24 Pts
Primary Signal Breakdown | Total Channels | Primary JB Terminal | PLC Rack / Slot
1x DI | 1 | P1-TBDI1-17 | C1/C1S4
1x DI | 1 | P1-TBDI1-18 | C1/C1S4
2x AI, 1x DI (Flow + Pulse + Pwr) | 3 | P1-TBAI1-1(A/B) | C1/C1S10
1x AI, 1x DI (Flow + Pulse + Pwr) | 2 | P1-TBAI1-3(A/B) | C1/C1S10
1x DI (Solenoid + FB) | 1 | P1-TBDI1-21 | C1/C1S4
1x DI (Solenoid + FB) | 1 | P1-TBDI1-22 | C1/C1S4
1x DI (Solenoid + FB) | 1 | P1-TBDI1-23 | C1/C1S4
1x DI (Solenoid + FB) | 1 | P1-TBDI1-24 | C1/C1S4
1x DI (Solenoid + FB) | 1 | P1-TBDI1-25 | C1/C1S4
1x DI (Solenoid + FB) | 1 | P1-TBDI1-26 | C1/C1S4
1x AI | 1 | P1-TBAI1-5(A/B) | C1/C1S10
1x AI | 1 | P1-TBAI1-6(A/B) | C1/C1S10
1x AI | 1 | P1-TBAI1-4(A/B) | C1/C1S10
1x AI | 1 | P1-TBAI1-9(A/B) | C1/C1S10
1x AI | 1 | P1-TBAI1-10(A/B) | C1/C1S10
1x AI | 1 | P1-TBAI1-11(A/B) | C1/C1S10
1x DO (Solenoid + FB) | 1 | P1-TBRL1-25 | C1/C1S8
1x DO (Solenoid + FB) | 1 | P1-TBRL1-26 | C1/C1S8
1x DO (Solenoid + FB) | 1 | P1-TBRL1-27 | C1/C1S8
1x DO (Solenoid + FB) | 1 | P1-TBRL1-28 | C1/C1S8
2x DI, 1x DO (Solenoid + FB) | 3 | P1-TBDI1-27 | C1/C1S4
2x DI, 1x DO (Solenoid + FB) | 3 | P1-TBDI1-29 | C1/C1S4
2x DI, 1x DO (Solenoid + FB) | 3 | P1-TBDI1-31 | C1/C1S4
2x DI, 1x DO (Solenoid + FB) | 3 | P1-TBDI2-1 | C1/C1S5
2x DI, 1x DO (Solenoid + FB) | 3 | P1-TBDI2-3 | C1/C1S5
2x DI, 1x DO (Solenoid + FB) | 3 | P1-TBDI2-5 | C1/C1S5
2x DI, 1x DO (Solenoid + FB) | 3 | P1-TBDI2-7 | C1/C1S5
2x DI, 1x DO (Solenoid + FB) | 3 | P1-TBDI2-9 | C1/C1S5
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

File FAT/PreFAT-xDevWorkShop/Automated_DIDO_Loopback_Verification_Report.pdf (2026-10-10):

## AUTOMATED DI/DO CLOSED-LOOP CROSS-WIRING VERIFICATION REPORT

Project: SPRINT 18K Spray Dryer | Target: MCP-01 (C1, C2, C3, C4) | Test Method: Dry Contact Relay Loopback to DI Terminal
Loop # | DO Slot & Pin | Interposing Relay Coil Tag | Relay Dry Contact
LPB-001 | C1S8 - Pin 1 | TBRL-1 (A1/A2) | TBRL-1 (11/14)
LPB-002 | C1S8 - Pin 2 | TBRL-2 (A1/A2) | TBRL-2 (11/14)
LPB-003 | C1S8 - Pin 3 | TBRL-3 (A1/A2) | TBRL-3 (11/14)
LPB-004 | C1S8 - Pin 4 | TBRL-4 (A1/A2) | TBRL-4 (11/14)
LPB-005 | C1S8 - Pin 5 | TBRL-5 (A1/A2) | TBRL-5 (11/14)
LPB-006 | C1S8 - Pin 6 | TBRL-6 (A1/A2) | TBRL-6 (11/14)
LPB-007 | C1S8 - Pin 7 | TBRL-7 (A1/A2) | TBRL-7 (11/14)
LPB-008 | C1S8 - Pin 8 | TBRL-8 (A1/A2) | TBRL-8 (11/14)
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

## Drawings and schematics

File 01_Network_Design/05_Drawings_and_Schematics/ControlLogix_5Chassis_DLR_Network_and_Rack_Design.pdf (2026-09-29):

# INGREDION THAILAND — SPRINT 18K TPA SPRAY DRYER PLANT (KALASIN)

ROCKWELL CONTROLLOGIX 5580 (1756-L950TPSXT) — 5-CHASSIS DLR NETWORK CABLE & 13-SLOT REDESIGN

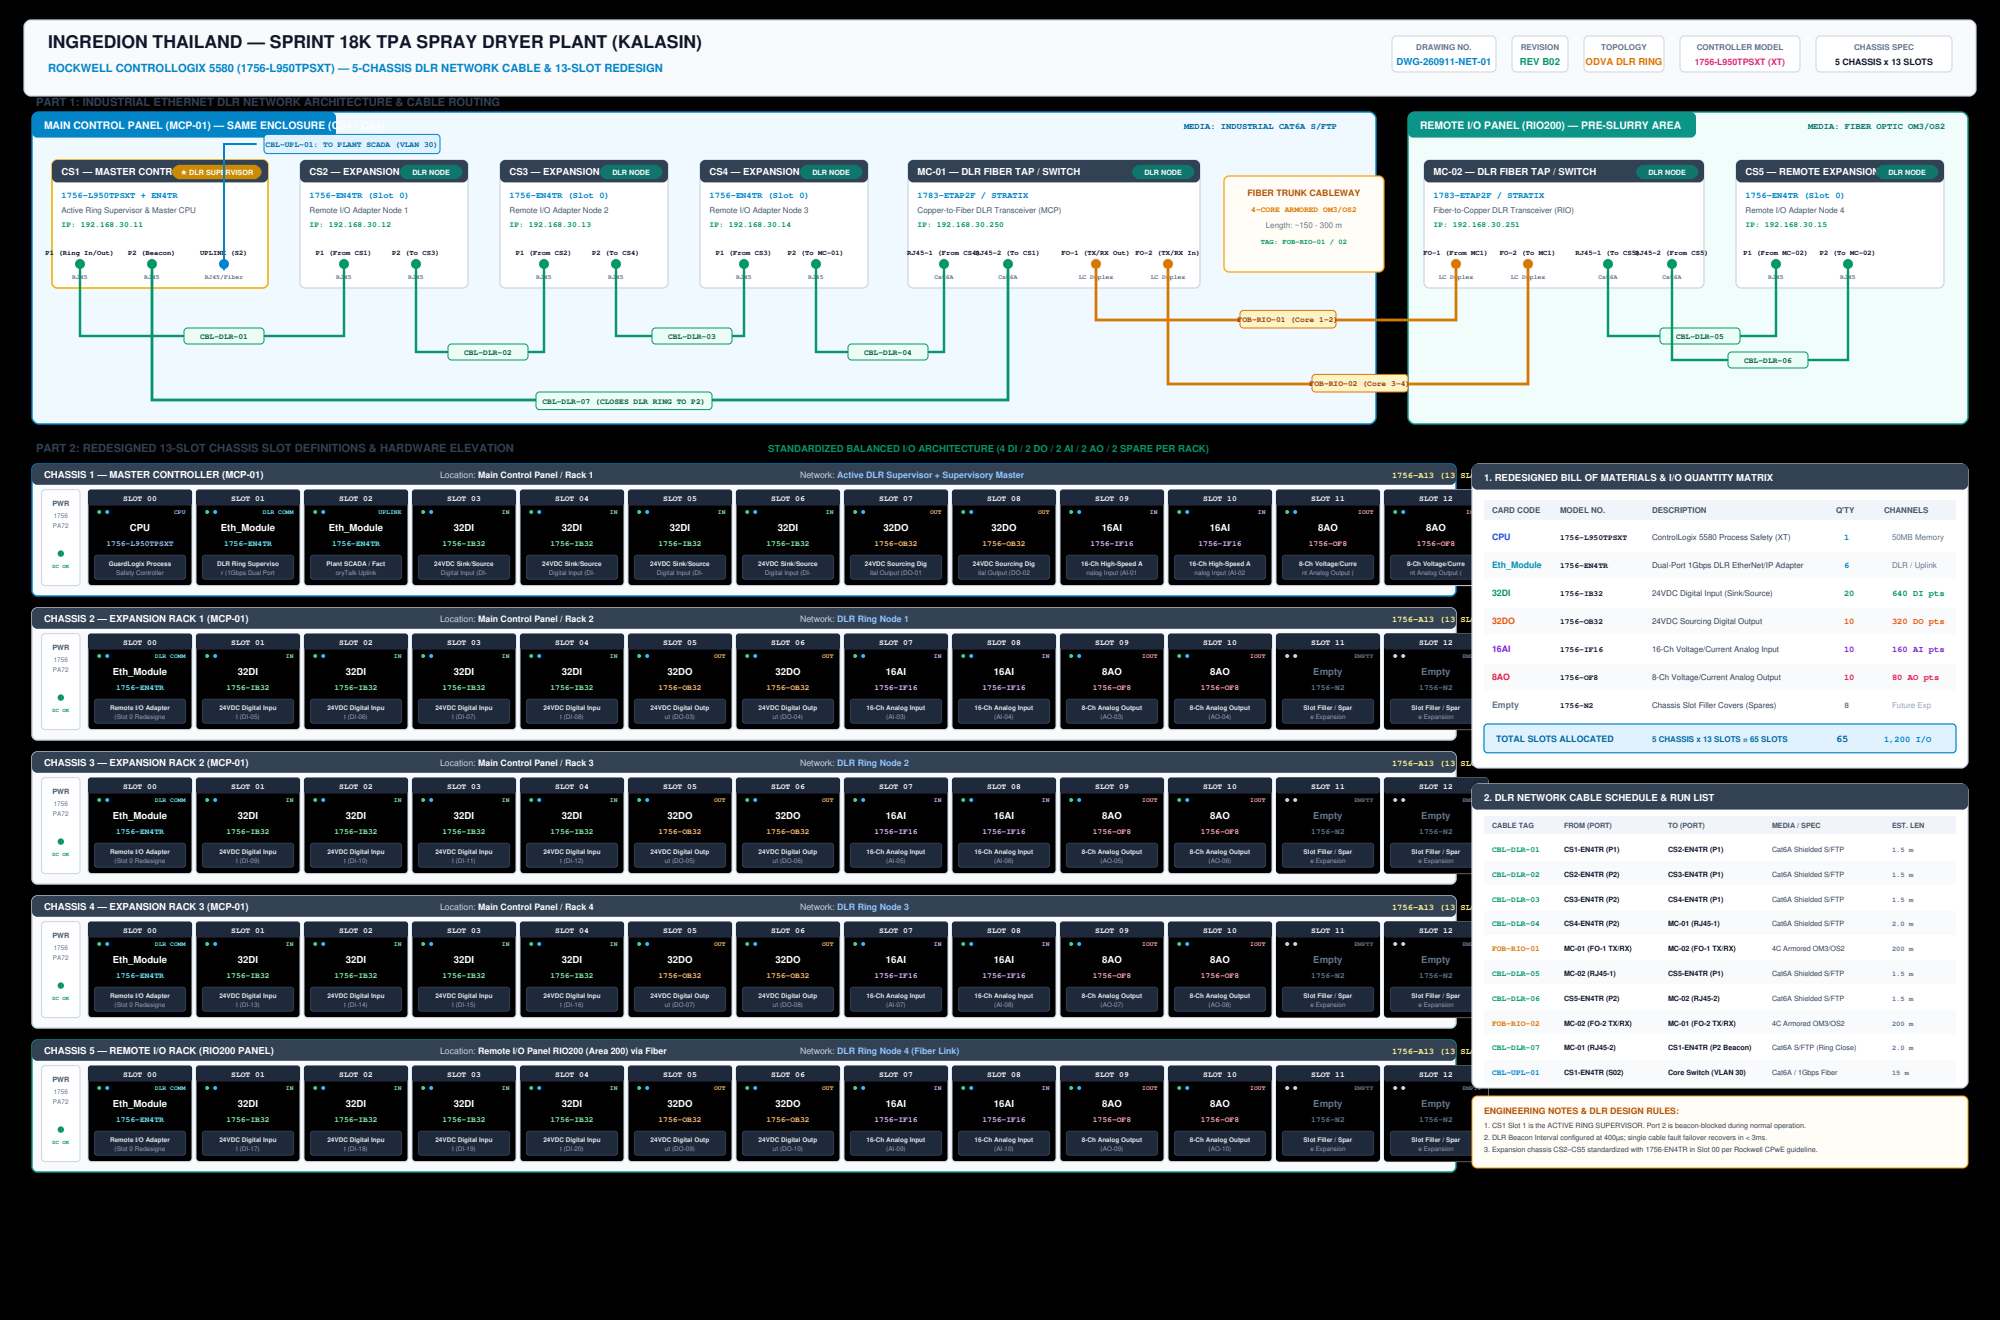
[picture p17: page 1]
DRAWING NO. DWG-260911-NET-01; REVISION REV B02; CONTROLLER MODEL 1756-L950TPSXT (XT); CHASSIS SPEC 5 CHASSIS x 13 SLOTS; MAIN CONTROL PANEL (MCP-01) — SAME ENCLOSURE (CS1 - CS4); MEDIA: INDUSTRIAL CAT6A S/FTP; REMOTE I/O PANEL (RIO200) — PRE-SLURRY AREA; MEDIA: FIBER OPTIC OM3/OS2; P2 (Beacon); UPLINK (S2); RJ45/Fiber; P1 (From CS1); P1 (From CS2); P1 (From CS3); MC-01 — DLR FIBER TAP / SWITCH; DLR NODE; RJ45-1 (From CS4); Cat6A; LC Duplex; MC-02 — DLR FIBER TAP / SWITCH; FO-1 (From MC1)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

TOPOLOGY
ODVA DLR RING

PART 1: INDUSTRIAL ETHERNET DLR NETWORK ARCHITECTURE & CABLE ROUTING

CBL-UPL-01: TO PLANT SCADA (VLAN 30)

CS1 — MASTER CONTROLLER ★ DLR SUPERVISOR

CS2 — EXPANSION RACK 1 DLR NODE

CS3 — EXPANSION RACK 2 DLR NODE

CS4 — EXPANSION RACK 3 DLR NODE

CS5 — REMOTE EXPANSION RACK DLR NODE

FIBER TRUNK CABLEWAY
4-CORE ARMORED OM3/OS2
Length: ~150 - 300 m
TAG: FOB-RIO-01 / 02

1756-L950TPSXT + EN4TR
Active Ring Supervisor & Master CPU

1756-EN4TR (Slot 0)
Remote I/O Adapter Node 1

Remote I/O Adapter Node 2

Remote I/O Adapter Node 3

1783-ETAP2F / STRATIX
Copper-to-Fiber DLR Transceiver (MCP)

Fiber-to-Copper DLR Transceiver (RIO)

Remote I/O Adapter Node 4

P1 (Ring In/Out)

FO-1 (TX/RX Out)

FOB-RIO-01 (Core 1-2)

FOB-RIO-02 (Core 3-4)

CBL-DLR-07 (CLOSES DLR RING TO P2)

1. REDESIGNED BILL OF MATERIALS & I/O QUANTITY MATRIX

DLR Ring Superviso
r (1Gbps Dual Port

Plant SCADA / Fact
oryTalk Uplink

24VDC Sink/Source
Digital Input (DI-

24VDC Sourcing Dig
ital Output (DO-01

ital Output (DO-02

16-Ch High-Speed A
nalog Input (AI-01

nalog Input (AI-02

8-Ch Voltage/Curre
nt Analog Output (

16-Ch Analog Input

8-Ch Analog Output

Slot Filler / Spar
e Expansion

2. DLR NETWORK CABLE SCHEDULE & RUN LIST
EMPTY

ENGINEERING NOTES & DLR DESIGN RULES:
1. CS1 Slot 1 is the ACTIVE RING SUPERVISOR. Port 2 is beacon-blocked during normal operation.
2. DLR Beacon Interval configured at 400µs; single cable fault failover recovers in < 3ms.
3. Expansion chassis CS2–CS5 standardized with 1756-EN4TR in Slot 00 per Rockwell CPwE guideline.

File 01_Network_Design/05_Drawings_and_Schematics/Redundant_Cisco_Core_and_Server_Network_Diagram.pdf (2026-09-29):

# INGREDION THAILAND — SPRINT 18K SPRAY DRYER PLANT (KALASIN)

## REDUNDANT CISCO CORE SWITCHES & REDUNDANT SERVER INFRASTRUCTURE CONFIGURATION

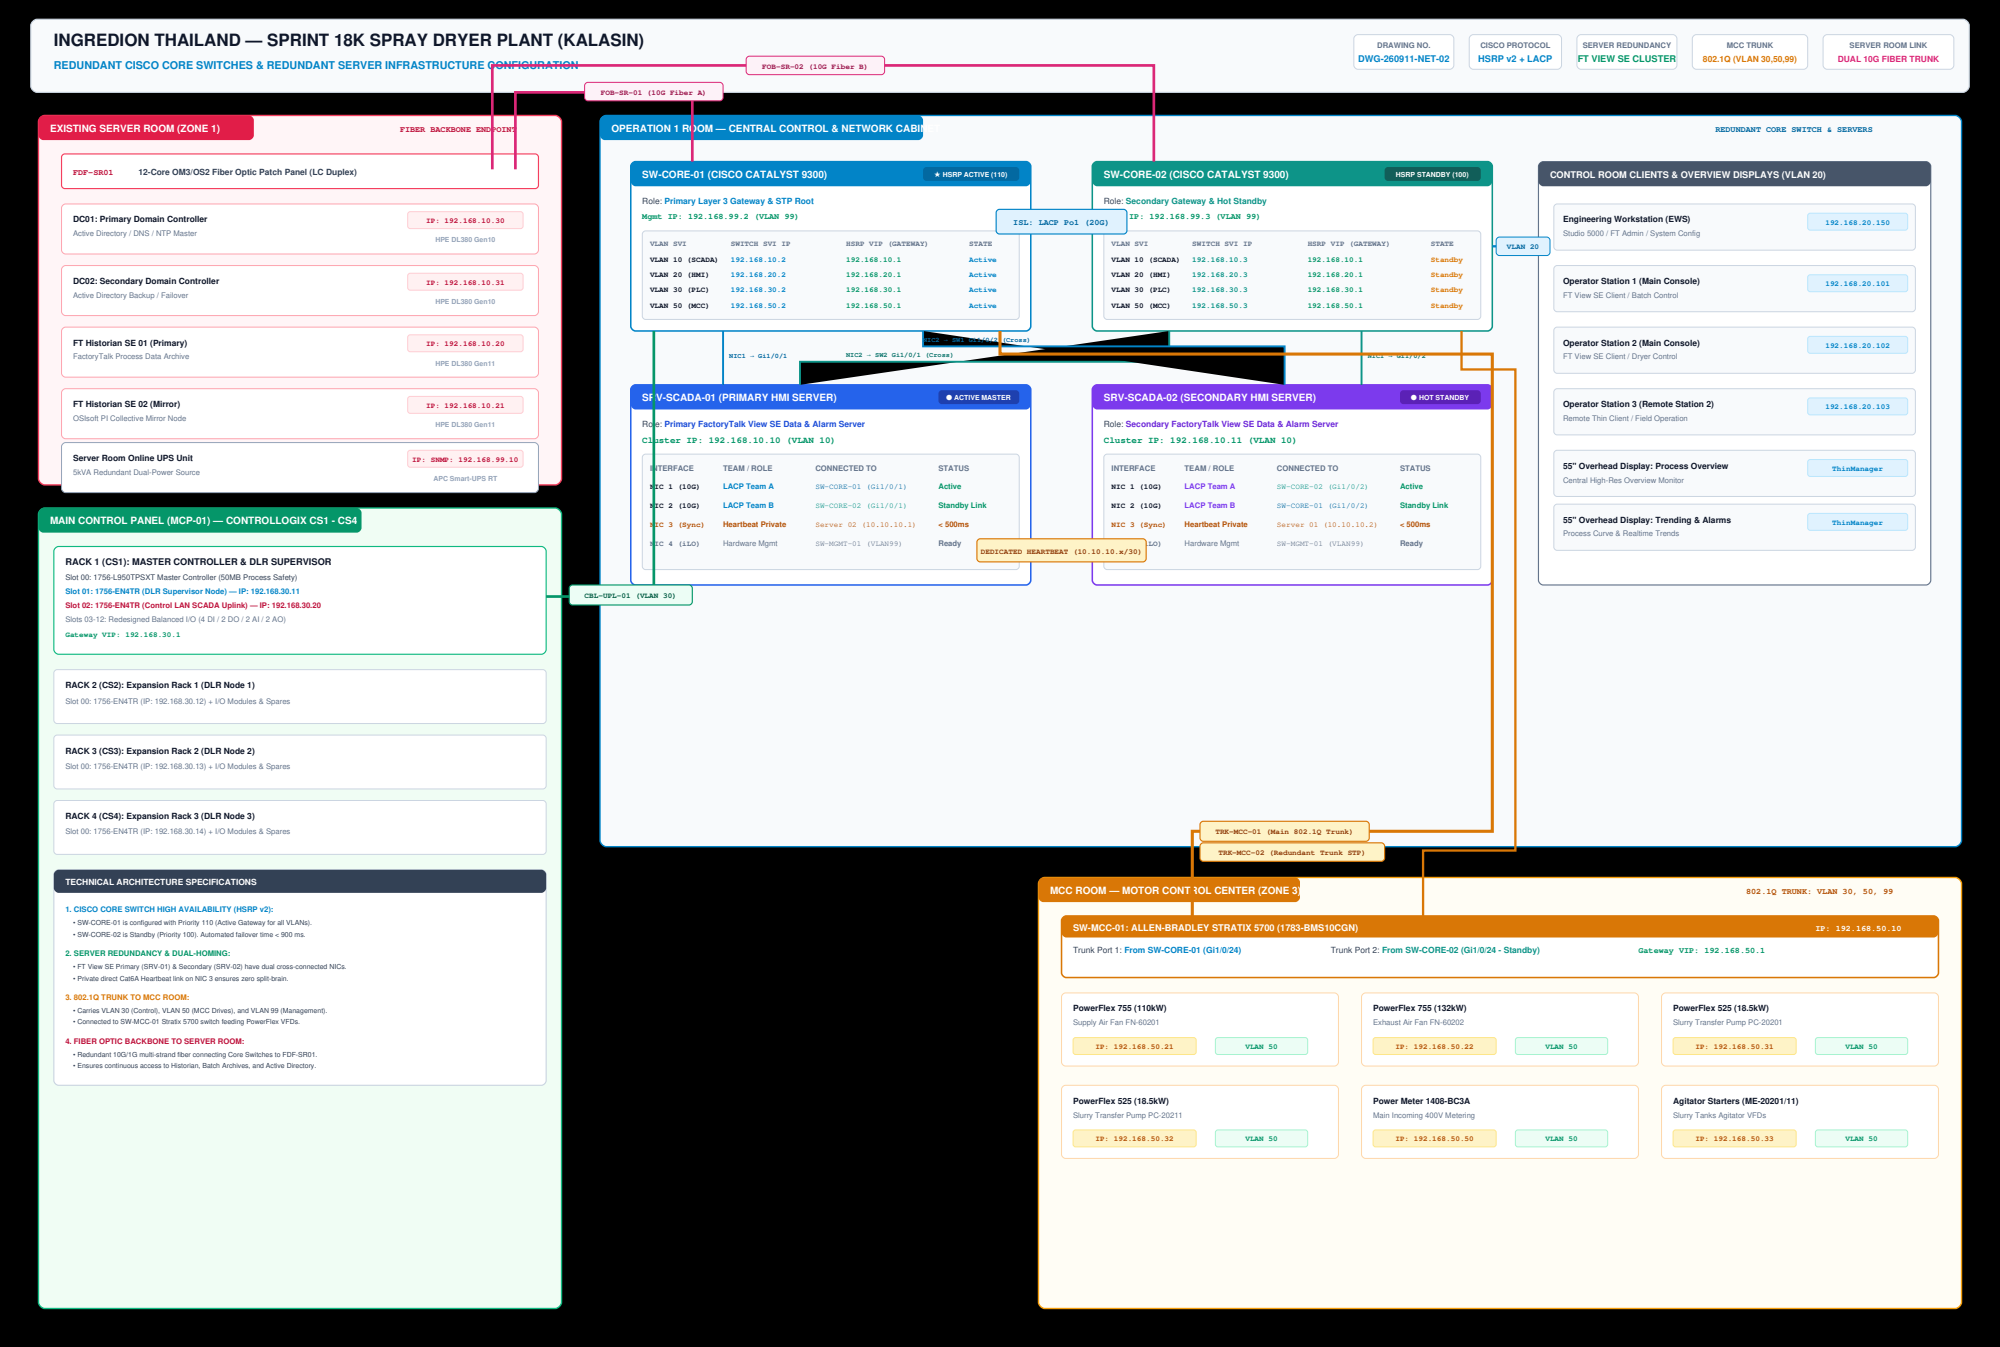
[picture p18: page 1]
DRAWING NO. DWG-260911-NET-02; CISCO PROTOCOL HSRP v2 + LACP; MCC TRUNK 802.1Q (VLAN 30,50,99); EXISTING SERVER ROOM (ZONE 1); FIBER BACKBONE ENDPOINT; FDF-SR01; 12-Core OM3/OS2 Fiber Optic Patch Panel (LC Duplex); HPE DL380 Gen10; HPE DL380 Gen11; IP: SNMP: 192.168.99.10; OPERATION 1 ROOM — CENTRAL CONTROL & NETWORK CABINET; REDUNDANT CORE SWITCH & SERVERS; SW-CORE-01 (CISCO CATALYST 9300); ★ HSRP ACTIVE (110); VLAN SVI; SWITCH SVI IP; HSRP VIP (GATEWAY); STATE; VLAN 10 (SCADA) 192.168.10.2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

SERVER REDUNDANCY
FT VIEW SE CLUSTER

SERVER ROOM LINK
DUAL 10G FIBER TRUNK

FOB-SR-02 (10G Fiber B)

FOB-SR-01 (10G Fiber A)

CONTROL ROOM CLIENTS & OVERVIEW DISPLAYS (VLAN 20)

Role: Primary Layer 3 Gateway & STP Root
Mgmt IP: 192.168.99.2 (VLAN 99)

Role: Secondary Gateway & Hot Standby
Mgmt IP: 192.168.99.3 (VLAN 99)

DC01: Primary Domain Controller
Active Directory / DNS / NTP Master

Engineering Workstation (EWS)
Studio 5000 / FT Admin / System Config

DC02: Secondary Domain Controller
Active Directory Backup / Failover

Operator Station 1 (Main Console)
FT View SE Client / Batch Control

FT Historian SE 01 (Primary)
FactoryTalk Process Data Archive

Operator Station 2 (Main Console)
FT View SE Client / Dryer Control

FT Historian SE 02 (Mirror)
OSIsoft PI Collective Mirror Node

Operator Station 3 (Remote Station 2)
Remote Thin Client / Field Operation

Role: Primary FactoryTalk View SE Data & Alarm Server
Cluster IP: 192.168.10.10 (VLAN 10)

Role: Secondary FactoryTalk View SE Data & Alarm Server
Cluster IP: 192.168.10.11 (VLAN 10)

Server Room Online UPS Unit
5kVA Redundant Dual-Power Source

55" Overhead Display: Process Overview
Central High-Res Overview Monitor

APC Smart-UPS RT

MAIN CONTROL PANEL (MCP-01) — CONTROLLOGIX CS1 - CS4

55" Overhead Display: Trending & Alarms
Process Curve & Realtime Trends

RACK 1 (CS1): MASTER CONTROLLER & DLR SUPERVISOR
Slot 00: 1756-L950TPSXT Master Controller (50MB Process Safety)
Slot 01: 1756-EN4TR (DLR Supervisor Node) — IP: 192.168.30.11
Slot 02: 1756-EN4TR (Control LAN SCADA Uplink) — IP: 192.168.30.20
Slots 03-12: Redesigned Balanced I/O (4 DI / 2 DO / 2 AI / 2 AO)
Gateway VIP: 192.168.30.1

CBL-UPL-01 (VLAN 30)

RACK 2 (CS2): Expansion Rack 1 (DLR Node 1)
Slot 00: 1756-EN4TR (IP: 192.168.30.12) + I/O Modules & Spares

RACK 3 (CS3): Expansion Rack 2 (DLR Node 2)
Slot 00: 1756-EN4TR (IP: 192.168.30.13) + I/O Modules & Spares

RACK 4 (CS4): Expansion Rack 3 (DLR Node 3)
Slot 00: 1756-EN4TR (IP: 192.168.30.14) + I/O Modules & Spares

TRK-MCC-01 (Main 802.1Q Trunk)

TRK-MCC-02 (Redundant Trunk STP)

TECHNICAL ARCHITECTURE SPECIFICATIONS

1. CISCO CORE SWITCH HIGH AVAILABILITY (HSRP v2):
• SW-CORE-01 is configured with Priority 110 (Active Gateway for all VLANs).
• SW-CORE-02 is Standby (Priority 100). Automated failover time < 900 ms.
2. SERVER REDUNDANCY & DUAL-HOMING:
• FT View SE Primary (SRV-01) & Secondary (SRV-02) have dual cross-connected NICs.
• Private direct Cat6A Heartbeat link on NIC 3 ensures zero split-brain.
3. 802.1Q TRUNK TO MCC ROOM:
• Carries VLAN 30 (Control), VLAN 50 (MCC Drives), and VLAN 99 (Management).
• Connected to SW-MCC-01 Stratix 5700 switch feeding PowerFlex VFDs.
4. FIBER OPTIC BACKBONE TO SERVER ROOM:
• Redundant 10G/1G multi-strand fiber connecting Core Switches to FDF-SR01.
• Ensures continuous access to Historian, Batch Archives, and Active Directory.

PowerFlex 755 (110kW)
Supply Air Fan FN-60201

PowerFlex 755 (132kW)
Exhaust Air Fan FN-60202

PowerFlex 525 (18.5kW)
Slurry Transfer Pump PC-20201

Slurry Transfer Pump PC-20211

Power Meter 1408-BC3A
Main Incoming 400V Metering

Agitator Starters (ME-20201/11)
Slurry Tanks Agitator VFDs

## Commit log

2026-09-29 feat: Initial commit of Kalasin Engineering xCIP system (all project files)
    [#SPRINT_18K_Control_Layout_System_Architecture.dxf, C1_C8_Chassis_Slot_to_Destination_JB_Report.xlsx, C1_C8_Slot_to_Destination_JB_Architecture_Diagram.dxf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]
2026-09-30 feat: update source drawings and add eDrawing templates
    [R5THS00138-FBR-WIR-20001_3.dwg, template_DI.dwg, template_DI.dxf]
2026-09-30 feat(io): Add IO_List_xDev-R01-Tag35-7 revisions 1 and 2 and update .gitignore
    [IO_List_xDev-R01-Tag35-7-1.xlsx, IO_List_xDev-R01-Tag35-7-2.xlsx]
2026-09-30 feat(io): Update IO_List_xDev-R01-Tag35-7-2.xlsx
    [IO_List_xDev-R01-Tag35-7-2.xlsx]
2026-09-30 feat(io-list): add IO_List-By_SlotConfig workbook with 13-slot chassis C1-C4 and slot schedule script
    [Copy of IO_List_xDev-R01-Tag35-7-3.xlsx, IO_List-By_SlotConfig.xlsx, IO_List_xDev-R02.xlsx]
2026-09-30 docs(io): add IO list report and update .gitignore for temporary office files
    [C1S1_DI.dxf]
2026-09-30 feat(cad): generate 15 DI wiring DXF drawings for Chassis C1-C4 from IO_List-By_SlotConfig.xlsx using template_DI.dxf
    [C1S4_DI_Wiring_Diagram.dxf, C1S5_DI_Wiring_Diagram.dxf, C1S6_DI_Wiring_Diagram.dxf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]
2026-09-30 feat(cad): add DI slot wiring DXF drawings and generation scripts
    [C1S1_DI.dxf, C1S4_DI_Wiring_Diagram.dxf, C1S5_DI_Wiring_Diagram.dxf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]
2026-09-30 feat(report): update IO_List_xDev-R01_Report.xlsx from IO_List_xDev-R01-Tag35-7-2.xlsx and add build script
    [IO_List_xDev-R01_Report.xlsx]
2026-10-01 refactor(cad): organize 03_CAD_Exports_DXF_SVG into categorized subfolders by drawing type
    [C1S4_DI_Wiring_Diagram.dxf, C1S5_DI_Wiring_Diagram.dxf, C1S6_DI_Wiring_Diagram.dxf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]
2026-10-01 feat(template): generate master Digital Output (1756-OB32) template_DO.dxf from template_DI.dxf
    [template_DO.dxf]
2026-10-01 feat(template): replace Fuse terminal with Phoenix Contact SPDT 24VDC Relay (PLC-RSC-24DC/21) in template_DO.dxf and generate DO drawings
    [C1S8_DO_Wiring_Diagram.dxf, C1S9_DO_Wiring_Diagram.dxf, C2S6_DO_Wiring_Diagram.dxf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]
2026-10-01 feat(template): add Drawing2.dxf and new eDrawing DWG templates (r02I)
    [Drawing2.dxf, R5THS00138-FBR-WIR-20001_3.dwg, template_D-r02I.dwg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]
2026-10-02 feat(power): add panel power supply calculation report and automation script for all panels
    [Panel_Power_Supply_Calculation_Report.xlsx]
2026-10-02 feat(power): incorporate Phoenix Contact TRIO 20A (2903151) from JW Tech quotation QJP-260901724-R0 into panel power design
    [Panel_Power_Supply_Calculation_Report.xlsx]
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2026-10-02 feat(cad): draft Pepperl+Fuchs IS equipment (HiC2821, HiC2871, HiC2025, HiCTB16) to AutoCAD DXF and vector SVG
    [C1S4_DI_Wiring_Diagram.dxf, C1S5_DI_Wiring_Diagram.dxf, C1S6_DI_Wiring_Diagram.dxf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]
2026-10-02 refactor(power): recalculate power consumption with true analog channel counts, pneumatic solenoid duty ratings, and P+F IS barrier loads
    [Panel_Power_Supply_Calculation_Report.xlsx]
2026-10-02 fix(io): standardize TagMarker and terminal numbering across all 14 analog modules
    [IO_List-By_SlotConfig.xlsx]
2026-10-02 feat(io): harmonize all 14 analog module sheets to match C1S10 architecture and standards
    [IO_List-By_SlotConfig.xlsx]
2026-10-02 docs(io): add standardized slot config revisions r02 and rev02
    [IO_List-By_SlotConfig-r02.xlsx, IO_List-By_SlotConfig_rev02.xlsx]
2026-10-05 feat(io): add junction I/O to panel P1-P4 allocation reports and update 1756-EN4TR adapters
    [Junction_IO_List_Panel_P1_P4_Allocation_Report.xlsx, Junction_to_Panel_P1_P4_Summary_Matrix.xlsx, RIO-200_Remote_IO_Report.xlsx]
2026-10-05 feat(drawings): update IS barrier CAD exports, eDrawing templates, and DXF conversion scripts
    [C1S10.dxf, C1S10_AI_Wiring_Diagram.dxf, C1S11.dxf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]
2026-10-05 docs & feat: update folder READMEs, group x9100-eDrawing by chassis (C1-C5) with slot tags, add C4S1 HiC2821 IS schematics, update master DXF generator
    [C1S0-L950TPSXT.dxf, C1S0-L950TPSXT_Wiring_Diagram.dxf, C1S1-EN4TR.dxf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]
2026-10-07 feat(panel-layout): add TAMCO CES and CRS enclosure libraries, update IS-JB-603 layout, and export loop test packages
    [00_Master_Loop_Test_JB_Register.xlsx, 1.dxf, 10.dxf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]
2026-10-09 feat(drawings): update title blocks, add IM-3-IGD-D25001 drawing package and DXF exports
    [.Deline_TitleBlock.dwg, .Deline_TitleBlock.dxf, A3-Title-Blox.dwg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]
2026-10-10 feat(ventilation & fat): add enclosure ventilation calculation package and pre-FAT testing documentation
    - Add 06_Enclosure_Ventilation_Calculation report (PDF, Typst, Python script, diagrams, MD)
    - Add Primus ventilation catalog in x9100-eDrawing/Supplier/
    - Add FAT and PreFAT-xDevWorkShop test packages, reports, and C1 FAT dashboard
    - Update 03-IO_List revisions, junction box schedules, and C4 slot configs
    [Automated_DIDO_Loopback_Verification_Report.xlsx, C1_DIDO_FAT_Test_Report.xlsx, C4S5_C4S6.xlsx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]
2026-10-10 feat(io): generate rev3.6-r01 IO lists by JB and slot config, audit missing IO, and update IO_Config with CxSx format
    [C1S0-L950TPSXT.dxf, C1S0-L950TPSXT_Wiring_Diagram.dxf, C1S1-EN4TR.dxf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]
2026-10-10 feat(eDrawing): standardize CxSx headers and extract panel drawings to x1000-PanelDrawing
    [IM-3-IGD-D25-001-000-007-01-All_New_Config copy.dxf, IM-3-IGD-D25-001-000-007-01-All_New_Config.dxf, IO_List-By_SlotConfig_rev02.xlsx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]
2026-10-10 feat(io): add C4S5_C4S6-r01 IO configuration schedule
    [C4S5_C4S6-r01.xlsx]
